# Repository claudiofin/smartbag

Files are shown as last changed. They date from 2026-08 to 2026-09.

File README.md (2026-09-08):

# SmartBag

**A removable smart insert for a handbag that recognises what is inside it —
without putting a tag on anything.**

Everything in this repo is generated by script: the PCB, the CAD, the renders,
the films. One command runs the whole chain, from KiCad to a finished MP4.

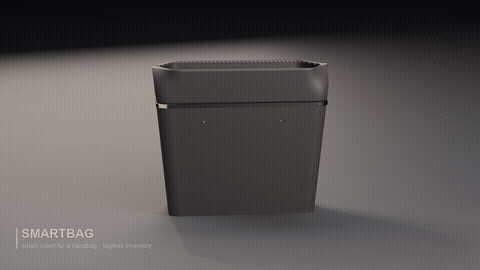
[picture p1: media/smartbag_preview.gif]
the bag opening in section


> *The GIF above is a short preview — click it for the full film.*
>
> **[▶ smartbag.mp4](media/smartbag.mp4)** (23 s) — how it is built ·
> **[▶ smartbag_sequence.mp4](media/smartbag_sequence.mp4)** (22 s) — how it works

---

## Read this first

This is a **design study**. Some of it is now checked by machine; none of it has
been built.

| | |
|---|---|
| schematic | **exists**, generated from `hardware/netlist.py`. **ERC: 0 violations.** |
| board | **113 footprints, six copper layers, routed, assembled on both sides.** DRC: **0 unconnected, 0 clearance violations, 0 shorts**; ERC clean. ⛔ It took a stackup change to get there, and the number that justified it is in [Six layers](#six-layers-and-the-number-that-decided-it). |
| part numbers | ⭐ **every IC is a real part, and its pinout comes from its own datasheet.** `tools/bom_report.py` measures each footprint against the datasheet's package on every run: **23 of 23 agree** — see [The bill of materials](#the-bill-of-materials). |
| firmware | the wake-up chain, the ledger, the taxel driver, the charge policy, the sensor bring-up, **the sensing loop that finally calls `sb_feed()`** and an Arducam Mega driver written from its own register table — **1035 assertions**, `-Werror`. ⭐ **And it builds for the nRF54L15**: [`firmware/target/`](firmware/target/) is a Zephyr app — ten HAL functions, the GATT service, the PMIC through Nordic's driver, a pin map **generated from the netlist** — at **177 KB of flash and 72 KB of RAM**, run by `tools/verify.sh`. ⚠️ Built, never run: nothing has met silicon. |
| recognition on the real part | the SoC has **no NPU**, so it was costed: 6.99 M MACs a frame on a 128 MHz M33 is **110–191 ms** against a settle window of 2000 ms — see [Recognition fits](#recognition-fits-the-processor). |
| recognition | an **enrolment pipeline that runs and is measured** — see [Recognition](#recognition). ⚠️ It now has to run on a Cortex-M33, not an NPU. |
| app | **written and running** — [`app/`](app/), tested against the firmware's own bytes. No native build; it is a web app. |
| RF | full-wave simulation rejected the antenna, closed-form analysis then rejected the whole feed — and the real part **dissolved the problem**: 60 GHz silicon has the antenna inside the package. There is now **no 60 GHz copper on this board.** See [RF](#rf). |
| thermal | **analysed** ([`thermal/budget.py`](thermal/budget.py)). It asked for charge current to be a function of cell temperature; the cell now has an NTC **in the pack**, a PMIC that reads it, and a policy under 544 assertions. |
| the taxel front end | measured wrong, then **fixed in hardware**: six transimpedance amplifiers and a 16:1 multiplexer — see [The taxel matrix](#the-taxel-matrix). |
| the 2.4 GHz antenna | ⛔ its datasheet found **three errors** in this design, one of them a terminal tied to ground that the part marks NC — see [The antenna](#the-antenna). |
| the optics flex | **exists now.** J1 was a connector to nothing for the whole project: the camera, the illuminators and the ToF live here. DRC 0 errors, 1 unconnected item. |
| the taxel sheet | **exists now.** 96 interdigitated sites, 16 columns and 6 rows, no components. **DRC 0 errors, 0 unconnected pads.** |
| fabrication | Gerbers for **all six copper layers**, drill, placement, DRC reports and a generated fab note for all three boards: `tools/fab.sh`. ⛔ The copper layer list is read out of the board file now — it was typed by hand, the stackup grew, and the next run plotted a six-layer board as four with In3 and In4 simply absent from the zip. ⚠️ **Two assembly sides now** — the processor's four decoupling capacitors are underneath it. |
| wireless power | ⛔ there was **no Qi receiver**: a coil was wired straight into a PMIC input that wants 4.0–5.5 V DC. There is now a BQ51013B, a dual resonant tank computed from the coil's own inductance, and a rectifier — see [Wireless power](#wireless-power). |

Run everything that can be checked:

```bash
./tools/verify.sh
```

```
== design constraints ==   all constraints hold
== firmware ==             28 + 324 + 53 + 264 + 21 checks, 0 failures
== protocol ==             15 tests passed
== ERC ==                  0 violations
== DRC ==                  0 errors · 4 unconnected pads · 0 footprint errors
== the other two boards == optics 0 errors, 2 pads · taxels 0 errors, 0 pads
== BOM vs footprints ==    23 of 23 named parts have a real MPN whose package fits
== recognition ==          ⭐ IT FITS, AND WITH ROOM
== physics ==              ✅ the 60 GHz feed question is settled
                           ⛔ Charging as specified puts the cell over its limit.
```

⚠️ The last two lines are printed on every run **on purpose** — and they are the
two findings that **rewrote the board**. The feed loss deleted the 60 GHz copper
and split one transceiver into two sensors; the charging analysis added a
thermistor and chose the PMIC. One is now a ✅ and one is still a ⛔, and both
keep printing: a suite that only reported its passes would be helping to forget
why the design looks the way it does.

## What it is

An **organiser that drops into any handbag** and knows what is inside it,
without tags on the objects:

| | |
|---|---|
| **IR camera** at the mouth | classifies each object as it enters or leaves |
| **60 GHz radar**, two 2×4 patch arrays | maps the volume through fabric — *where* it landed |
| **96-taxel FSR floor** | mass and footprint — *how heavy* and *what shape* |
| **ToF + Hall sensor** | the wake-up chain: closure opens → object enters → camera fires |
| **IMU** | integrates disturbance: tells the map when it has gone stale |

The bag itself is never modified, so the bag's value is never touched. The
insert slides out and moves to another one.

## The films

### smartbag_sequence.mp4 — how it works

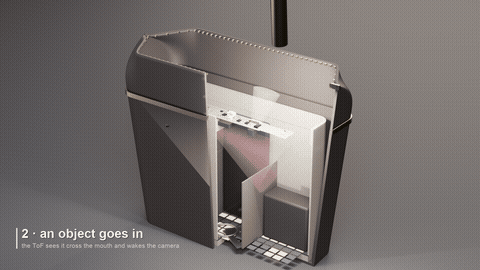
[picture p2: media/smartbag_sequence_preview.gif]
an object goes in and is scanned


1. **the zip opens** — the slider runs, the mouth gapes, the Hall sensor on the
   closure wakes the system
2. **an object goes in** — the ToF intercepts it crossing the mouth
3. **the IR camera fires** — three frames as it passes; the object itself lights
   up under the flash
4. **the radar maps the volume** — where it landed
5. **the FSR matrix weighs it** — the taxels under the object light up *when it
   lands*, not before
6. the zip closes again

### smartbag.mp4 — how it is built

The bag opens in section, the insert comes apart into its five layers with the
real KiCad board on top, the taxels light in a wave under the contents, then it
closes.

## Stills

| | |
|---|---|
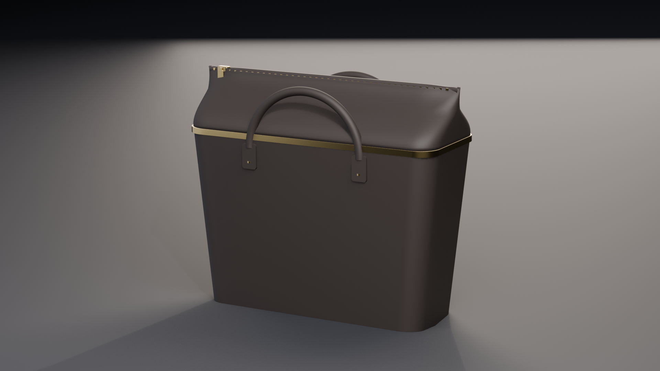
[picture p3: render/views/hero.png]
hero
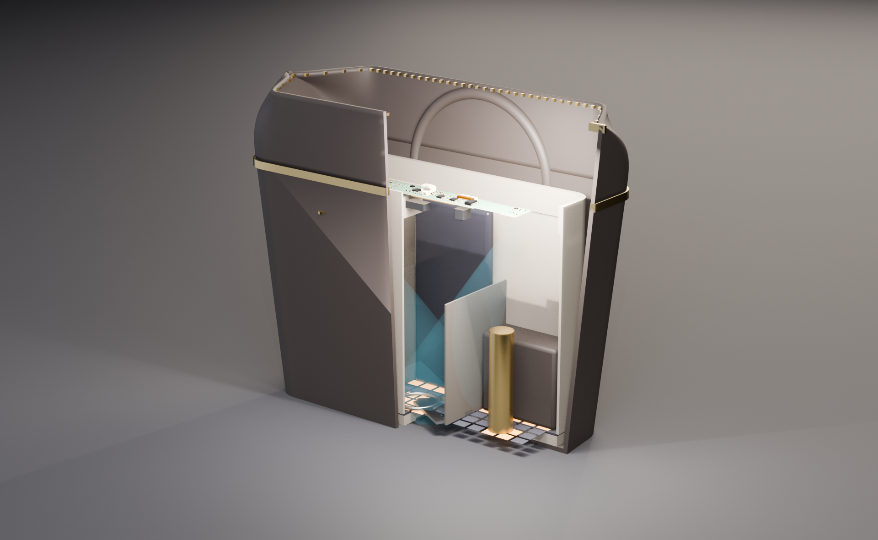
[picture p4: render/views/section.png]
section
|  |  |
| the bag closed: pinched neck, zip pulled shut | the section: contents upright, radar beam, taxels lit |

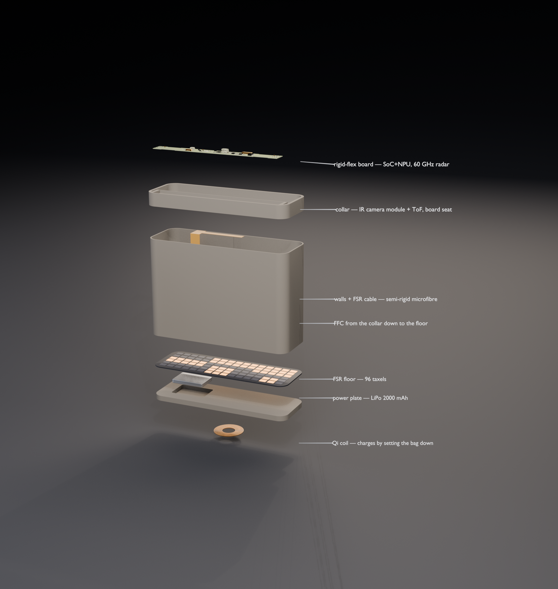
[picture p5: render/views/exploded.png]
exploded


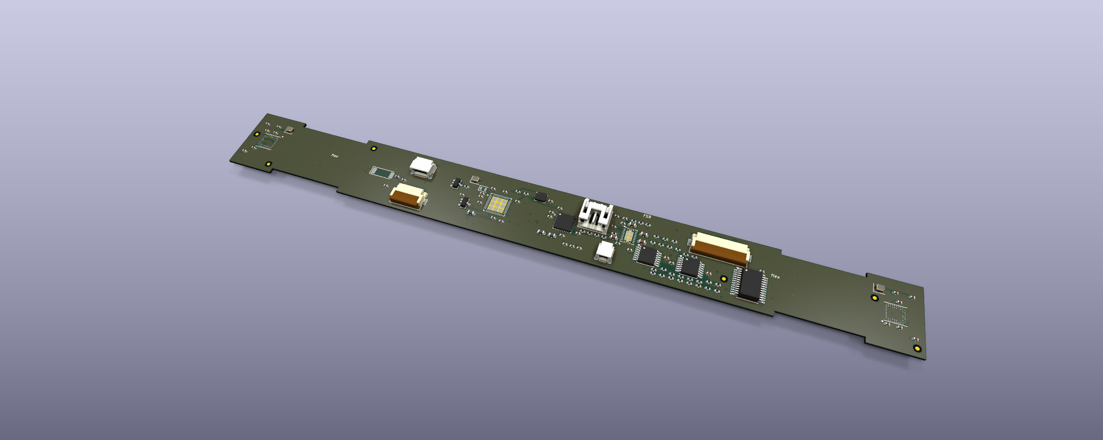
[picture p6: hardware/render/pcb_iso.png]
the board


---

## The pipeline

```
hardware/generate_pcb.py  ──> smartbag_core.kicad_pcb ──> KiCad raytracer renders
                                       │
                                       └─ kicad-cli export glb ──┐
cad/bag_and_insert.py     ──> 15 STL (bag + insert) ─────────────┴─> render/scenes.py
                                                                     (Blender EEVEE)
```

```bash
python3 tools/check.py             # the constraints, in ~0.1 s
./tools/pipeline.sh 1920           # circuit -> geometry -> stills   (~45 s)
./tools/render_animation.sh 1600   # 696 animation frames            (~26 min)
python3 render/build_video.py      # captions, fades, ffmpeg encode  (~3 min)
```

⭐ **`tools/check.py` asserts what the renders discovered.** Every constraint in
it was found the expensive way — modelling something, rendering it, and seeing
it was wrong. A board 51 mm deep in a 4 mm collar wall; an FSR tail 40 mm long
against a 150 mm drop; an object landing on top of a divider. None of those
raise an error anywhere: they produce a picture that looks fine until you look
closely. Written down as assertions they cannot silently come back — and the
first time it ran it caught three more, all invisible in the renders because
something else happened to be in front.

⭐ **It is a chain, not three separate things.** The PCB does not end up in a
PDF: it is exported to GLB and becomes an object in the *same Blender scene* as
the bag. That is the only way to find out that a board does not fit where it was
supposed to — and that is exactly what happened.

## Real numbers

| | |
|---|---|
| bag | 240×95 (floor) → 276×112 at 190 mm, 3.5 mm leather; soft neck 190→245 mm |
| insert | 225 × 78 × 180 mm, removable |
| board | 196 × 20 mm strip, 0.6 mm rigid islands on 2-layer polyimide flex |
| FSR matrix | 16 columns × 6 rows = 96 taxels, 22 lines on a 24-way FFC |
| radar arrays | 2 × (2×4 patches), 2.5 mm pitch = λ₀/2 at 60 GHz |
| battery | **Jauch LP523450JU**, 950 mAh, 53 × 34.5 × 5.8 mm, with PCM and a 10 k NTC on its harness — beside the Qi coil, not on top of it |

## What the renders actually rejected

This is the part worth reading. Putting the PCB and the CAD in the *same scene*
killed several things that looked fine on paper:

- **The first board layout was impossible.** A 126×51 mm cross with the FSR tail
  dropping out of the middle. Dropped into the insert, a board 51 mm deep either
  spans the mouth floating in mid-air or pokes out of the bag: the collar wall is
  4 mm. Redrawn as a **196 × 20 strip** sitting in a 24 mm front band.
- **The FSR tail on the board did not reach the floor.** 40 mm of flex against a
  150 mm drop. It became a **separate FFC** on J4 — which is also how it would
  really be assembled, because the cable has to pull out.
- **The insert has to pass through the smallest cross-section**, the floor, not
  the mouth. Hence 225×78 and not 240×82.
- **The bag never actually closed.** It was an open-mouthed tote, so the only
  thing "opening" was the section. Without a real closure there is no Hall
  sensor either — and that is the first link in the whole chain.
- **A zip is not a hinge; it is a mouth that pinches shut.** Four attempts
  rotated two rigid flaps hinged on the rim (up, down, inwards, outwards). All
  four read as a *hatch*, because two rigid plates rotating about a hinge **are**
  a hatch. The problem was upstream: a bag modelled as a rigid box cannot have a
  credible closure. The rigid body now ends at 190 mm and the last 55 are a
  **soft neck** — a surface with two states (oval mouth / mouth pinched to
  11 mm) interpolated by a shape key. The two rows of teeth do not rotate, they
  **separate**.
- **A zip has to be able to end somewhere.** With a rounded-rectangle mouth the
  teeth stayed 100 mm apart even at the tips and the slider finished its travel
  floating in mid-air. The mouth is now a **pointed oval**: the depth is squeezed
  to 4.5% over the last 40 mm, and only in the upper part of the neck (t³ —
  applied in proportion to height, the ends became wedges and from the side the
  bag looked like it had a pitched roof).
- **The object landed inside another object.** It fell at x = 44, straddling the
  divider at x = 37.5. Moved to x = 60, checked against divider, pouch and keys.
  The number lives in one place, `CONTENTS`, and both the render and the taxel
  logic read it from there.
- **The camera did not exist.** There was a pink cone flashing, but no module
  emitting it: light came out of a hole in the microfibre. A sensor you cannot
  see is a sensor nobody understands. There is now a module with its lens and
  four illuminators — and the **object lights up too**, which is the only thing
  that makes clear the flash is hitting it.
- **The hand was deleted.** Four attempts (from above, tilted, in section, with
  tapered and curled phalanges) and it stayed the worst thing in the frame while
  stealing attention from the sensors. An object descending on its own is
  understood in the first frame and has nothing to get wrong.

## The circuit

The connectivity is declared once, in [`hardware/netlist.py`](hardware/netlist.py):
pins, electrical types and nets for 26 parts. Three things consume it — the
schematic generator, the board generator, and the checks — so the board and the
schematic cannot drift apart. `kicad-cli pcb drc --schematic-parity` reports
**0 footprint errors**, which is that claim, verified.

**ERC found two things that were genuinely missing**, and the fix was to add
them rather than to silence the check:

- **no way to program the board.** SWDIO and SWCLK went nowhere. There is now a
  4-way SWD connector (J5), with its pins declared *bidirectional*, which is
  both electrically accurate and what makes ERC see the SoC's SWCLK input as
  driven.
- **a BLE radio with no antenna.** The SoC's ANT pin connected to nothing. There
  is now a 2.4 GHz chip antenna (AE1).

**DRC went from 439 violations to 0**, and almost all of the reduction was
deleting something rather than adding it:

| | |
|---|---|
| 439 → 215 | the board never declared its process. It is 0.1 mm lines on 2-layer polyimide flex with 0.3/0.15 vias; judged against KiCad's generic 0.2 mm defaults it collected 108 track-width and 112 via/drill violations that said nothing about the layout. |
| 215 → 1 | **the decorative routing.** Before there was a netlist, the generator drew bundles of tracks on net 0 to make the renders look like a circuit. Once the pads carried real nets, DRC read those tracks for what they were: 40 shorts, 6 clearance violations, 168 solder-mask bridges — one object producing more than half the errors on the board. |
| 1 → 0 | a courtyard overlap, and silkscreen. |

⛔ **The board is not routed.** Fanning out a 0.4 mm-pitch QFN-48, laying a
22-line bus and two 60 GHz microstrip feeds is a real job, and faking it with
decorative polylines is exactly the mistake that was just removed.

## RF

[`rf/patch_sim.py`](rf/patch_sim.py) solves Maxwell's equations on the patch
element with openEMS — ground plane, dielectric, patch, probe feed — and it
**falsified the antenna as first drawn**.

The setup is validated first, because a negative result is only worth stating if
the same solver reproduces a case theory says should work: a patch sized by the
transmission-line model (1.31 mm on 0.127 mm) comes back at **59.0 GHz, −9.3 dB**
— within 1.7% of target.

| substrate | patch | f_res | S11 | −10 dB BW | |
|---|---|---|---|---|---|
| 0.600 mm | 1.20 mm | 50.8 GHz | **−2.5 dB** | 0 | the rigid stack, as first drawn |
| 0.250 mm | 1.20 mm | **59.9 GHz** | **−27.2 dB** | **3.5 GHz** | the antenna islands, as now specified |

⛔ **On the 0.6 mm rigid stack the element does not work.** It sits 9 GHz low and
reflects almost everything. `h/λ₀` was 0.12, which is enormous at 60 GHz — the
board is 0.6 mm because that is what the rigid islands are, and nobody had
chosen that number for the antenna.

⭐ **The fix is the stackup, not the artwork.** At 0.25 mm the *same* 1.2 mm patch
matches at −27.2 dB with 3.5 GHz of bandwidth. On a rigid-flex board that costs
nothing: the antenna areas keep the flex core and a thin stiffener instead of the
full rigid buildup. A `.kicad_pcb` carries one board thickness, so it is a
fabrication note, on the Cmts.User layer and in `dimensions.py`.

⚠️ One element in isolation. No array coupling, no flex bend, no connector
parasitics, and εr is assumed — the numbers move with it.

**Getting the simulation to run at all took four wrong hypotheses.** It kept
returning `Energy: ~ nan` from the first timestep, and PML-over-a-conductor, the
lossy dielectric and the port were all blamed before a uniform-mesh control case
came back clean and pinned it on **mesh grading**: a 16:1 jump from the cells
over the patch to the far field. FDTD does not error on that, it silently
returns NaN. `rf/patch_sim.py` now refuses to run a mesh that will diverge, which
turns ninety wasted seconds into one line of output.

```bash
python3 rf/patch_sim.py --sweep
```

### And then the feed, which is worse

Fixing the element fixed the element. [`rf/feed_loss.py`](rf/feed_loss.py) asks
the next question — what does it cost to *reach* it — and the answer ends the
architecture.

The transceiver sits in the middle of a 196 mm board. The two antenna islands
are at the ends, 87 mm and 99 mm away. On the 0.25 mm substrate a 50 Ω line is
0.58 mm wide, and at 60 GHz it loses:

| | |
|---|---|
| dielectric | 0.64 dB/cm |
| conductor, roughened | 0.31 dB/cm |
| **total** | **0.94 dB/cm** |
| over 88 mm | **8.2 dB one way, 16.5 dB there and back** |

⛔ **A radar link budget goes as the fourth power of range.** 16.5 dB round trip
is a factor of 2.6 in range thrown away before the antenna has radiated
anything — on a sensor whose entire job is to see through 78 mm of handbag.

⭐ **This is not a routing problem and no layout fixes it.** The distance is the
floorplan, and the floorplan is the product: the two islands are at the ends
*because* two separated viewpoints are what makes the map work. Three ways out,
all of them architectural:

- a transceiver **on each island**, with a low IF and a reference clock
  distributed down the flex instead of 60 GHz;
- both antennas **next to the transceiver**, giving up the two viewpoints;
- **one island**, and a single viewpoint.

### And then a real part settled it

⭐ **The parts search dissolved the problem.** [`hardware/bom.py`](hardware/bom.py)
went looking for a 60 GHz transceiver you can actually buy. The Acconeer **A121**
is a 50-ball fcCSP, 5.2 × 5.5 × 0.88 mm, 57–64 GHz, 1.8 V, SPI — and its
datasheet says, in so many words:

> "The product has integrated antennas in package, it is not possible to connect
> trace antenna."

There is no 88 mm feed to lose 8.2 dB in, because **a real 60 GHz part is placed
where its antenna has to be.** That is option one above, arrived at by the parts
bin rather than by choice: `ANT_A1` and `ANT_A2` should not be nets, the two
antenna islands should be two sensors, and what runs down the flex to each of
them is SPI at a few tens of MHz instead of 60 GHz.

⚠️ Which also means the footprint on the board — a QFN-40 with four antenna
ports — is for a part that does not exist. That is one of the three mismatches
in [the bill of materials](#the-bill-of-materials).

```bash
python3 rf/feed_loss.py
```

## The board, rebuilt around parts you can buy

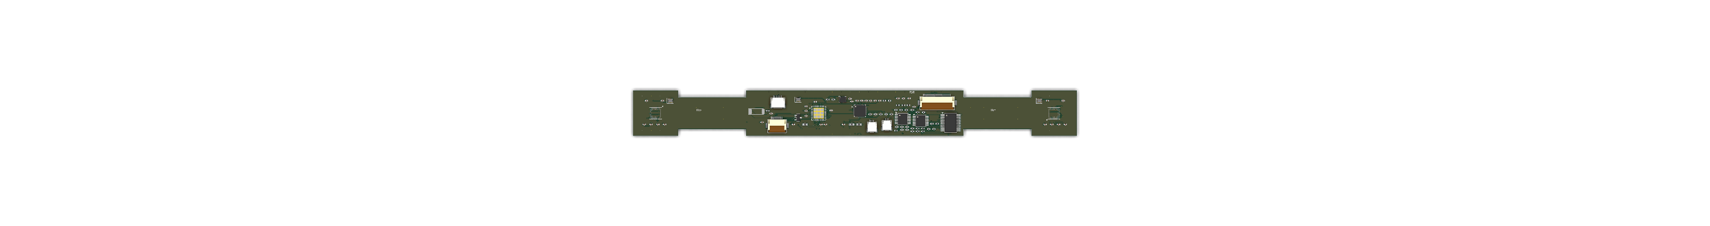
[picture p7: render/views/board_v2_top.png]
the routed board

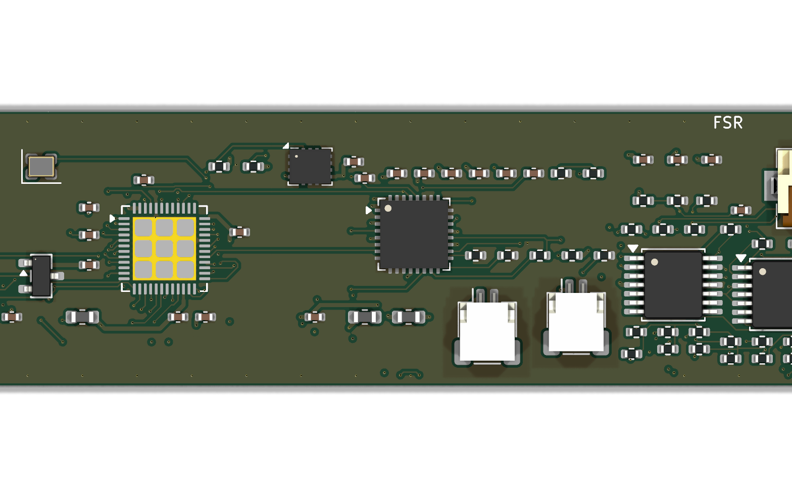
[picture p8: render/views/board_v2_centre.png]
the centre island


*Top: the whole 196 mm strip — two rigid end islands carrying a radar each, two
flex tails, and the centre island. Bottom: the centre island, where the QFN-48
processor, the QFN-32 PMIC, the taxel front end and the connectors live.*

The first version of this board was drawn from component *classes* — "SoC+NPU
BLE 5.4", "mmWave 60 GHz TRX" — with pinouts invented to suit. It said so, which
is better than not saying so, and it was still unbuildable: no real SoC has
ground on exactly pins 3 and 4. Going and finding the real parts changed the
architecture three times, and every change had already been asked for by
something else in this repo.

| what the parts changed | what had asked for it |
|---|---|
| **two radars, one on each end island, and no 60 GHz copper at all** | `rf/feed_loss.py` priced a central transceiver's feed at 8.2 dB one way. The Acconeer A121's datasheet then said the antenna is inside the package and *"it is not possible to connect trace antenna"*. The feed does not exist because a real part is placed where its antenna has to be. |
| **an NTC on the cell, into a PMIC that does JEITA charging** | `thermal/budget.py` put the cell near 60 °C on a 5 W charge against a 45 °C limit and asked for charge current to be a function of cell temperature. The nPM1300 has the input; the invented PMIC had nowhere to put one. |
| **six transimpedance amplifiers and a 16:1 multiplexer** | `firmware/test_sb_fsr.c` measured both scan modes the old board could run: one invents phantom taxels at 39% of a real press, the other reads real ones 83% light. |

⚠️ **And one thing the parts took away.** No BLE SoC in a QFN has an NPU *and* a
camera interface — the ones with an NPU are BGAs with no radio, the ones with a
radio have no NPU. The processor is an **nRF54L15**, a 128 MHz Cortex-M33, and
recognition has to run on it. That is survivable only because the firmware
already waits 2 s for an object to settle before measuring, so inference happens
inside a window that existed anyway.

⭐ **And it has now been counted rather than hoped for.**
[`ml/inference_budget.py`](ml/inference_budget.py) hooks the model and adds up
its multiply-accumulates instead of guessing: **6.99 M MACs**, which is 110–191
ms on a 128 MHz M33 with CMSIS-NN depending on how many cycles per MAC you are
willing to believe. The settle window is 2000 ms. The margin is an order of
magnitude, which is the only reason losing the NPU was survivable.

**113 footprints: 21 named parts, 86 passives, 6 fiducials.** The floorplan lives
in one block in `netlist.py`; [`hardware/place.py`](hardware/place.py) turns it
into positions whose courtyards do not intersect, because a hundred hand-typed
coordinates always collide somewhere — the first pass collided in 28 places.

⚠️ **The fiducials are placed by a different rule from everything else**, and
finding that out cost thirteen DRC violations. A fiducial has no net and no
neighbour it wants to be near, so the push-apart loop has nothing to work with:
it shoved two of them into capacitors and stalled. Telling it to maximise
clearance instead was worse — it emptied every fiducial onto the least crowded
island and left three in a row, and three collinear marks tell a placement
camera about one axis. They are a **decision**: two per rigid island, diagonally
opposite, because the flex tails let the islands move with respect to each other
and a machine that has located one has learned nothing about the next. The
search only nudges them off whatever they landed on.

⛔ **Nothing sits on the flex.** The board is a 196 mm strip with two tails in it,
and a package soldered across a section that bends does not stay soldered. An
early placement pass put a 24-way connector and a row of resistors out over a
tail and off the board edge with them; the placer now knows about the three rigid
islands and refuses.

## Routing

**KiCad has no autorouter.** It had one through version 5 and it was removed, so
the flow is: `pcbnew` writes a Specctra `.dsn`, somebody else's router writes a
`.ses`, `pcbnew` reads it back. The router here is **Freerouting**, a maze router
with rip-up and retry.

```bash
tools/route.sh                      # generate → DSN → route → import → stitch → DRC
hardware/reroute_from_session.sh    # rebuild from the committed .ses, no Java
hardware/stitch.py                 # tie orphaned ground islands back to the plane
```

⭐ **`maze.py` exists because Freerouting recommends something it cannot do.**
When it stops improving it says so: *"it is recommended to stop it and finish the
board manually."* Manually is fine — but a person drawing four tracks and
eyeballing them is exactly the step this project avoids everywhere else. So the
candidates are drawn blind and **DRC decides**: a route is kept only if the net
it was drawn for has fewer breaks and the board has no new violations, and
reverted otherwise. It cannot make the board worse; the worst it can do is fail
to help.

⛔ **Which is a harder test to write than it looks.** "Fewer unconnected pads on
the board" is wrong — KiCad reports one ratsnest line per NET, so closing one of
a net's two breaks changes nothing and a correct repair gets thrown away. "The
pair DRC named is gone" is wrong — KiCad picks a different representative item
every run, so it is always true, and under it this router once accepted twelve
vias that connected nothing and reported each as a success. Counting islands
through KiCad's own connectivity was wrong too. What works is asking DRC how
many breaks **this net** has left.

⚠️ Its first version reverted by reloading the board from the file it had just
written the failed candidate into. Three rejected tracks accumulated in the
board and the tool reported the damage as its starting state.

⛔ **And the maze router's collision model was optimistic by less than a cell**,
which is the hardest kind of wrong to see. Pillow rounds an ellipse *in*, so
every via was drawn as an obstacle up to one grid cell smaller than it is — 50 µm
at the fine pitch. `SPI_MISO` came back from a 2264-cell search with sixteen
clearance violations of 0.02–0.08 mm, every one a track passing a via, and the
router had proposed each of them believing it was legal. Rounding the obstacle
circles out took it to one. See
[Decoupling](#decoupling-the-defect-that-passed-every-check) for the other three
of the same family.

⭐ **Two of the last connections were never routing problems at all**, and
[`hardware/repairs.py`](hardware/repairs.py) says so out loud. One is a *gap* —
two pieces of a net a tenth of a millimetre apart, under a track width, which
looks joined at any zoom a person would use. The other is a *missed drop*: a
track that ends exactly on a pad, on the wrong layer, so the copper is in the
right place, there is no via, and the ratsnest line is **zero millimetres long**.
Sent at either, the maze router routes a centimetre around the houses, because
the pair DRC names is the two islands' representative items and not the two ends
that need joining. Each repair states what has to be true before it applies and
**refuses loudly** if the board has moved under it.

| | |
|---|---|
| tracks / vias | **1713 / 393**, 4.3 m of copper |
| DRC | **0 errors, 0 footprint errors**, schematic parity clean |
| unconnected | **1 item of ~500** |
| layers | F.Cu 724 · In2.Cu 919 · B.Cu 70 · **In1.Cu 0 — a solid ground reference** |

⛔ **Sixteen of those twenty were a pin assignment, not a routing problem.** The
board first came back with one contiguous run of U1's pins unrouted — `MUX_S3`,
`MUX_EN_N`, `CS_RADAR_R`, `RADAR_IRQ_R`, `SPI_MOSI` — and the thing they had in
common was direction: every destination was tens of millimetres to the **east**,
and `MUX_S3` sat on pin 11, which is on the package's **west** edge. That net
began by crossing the whole processor before it could start travelling.

⭐ **Which GPIO carries which signal is a layout decision**, and on this part it
is nearly free: the firmware addresses pins through a HAL of symbolic ids, so
the physical assignment is invisible to it. The P2 block is now ordered by
destination — westbound nets on the west pins, eastbound on the east ones,
furthest travel on the outermost pin. `SPI_SCK`, `SPI_MOSI` and `SPI_MISO` do
not move, because those are the pins the high-speed SPIM is wired to in silicon
and the other instances run at 8 MHz instead of 32.

| | before | after |
|---|---|---|
| unconnected | 16 | **4** |
| autoroute time | 65 min | **15 min** |

⭐ **And one of the four was closed by writing a router for it.**
[`hardware/maze.py`](hardware/maze.py) is A* over a 0.1 mm grid, and it exists
because a fixed set of shapes cannot go *around*: a straight line and two L-bends
per layer, which on a board this dense all cross something. It reports that
honestly and stops.

| | |
|---|---|
| **zones are not obstacles** | almost all of F.Cu and B.Cu is ground pour. KiCad re-fills around new copper, so the route lays itself into the pour and the pour retracts. Treating the pour as solid finds no route anywhere. |
| **obstacles are drawn, not computed** | testing a million grid points against two thousand segments is a minute per net; drawing those segments with a brush already fattened by (their width + clearance + ours) is milliseconds. Pillow is the collision engine. |
| **DRC decides** | every route is applied to a copy, checked by a real `kicad-cli pcb drc`, and kept only if the board comes out with fewer unconnected items and no new violations. |

It closed `RADAR_IRQ_R`, the longest of them — 108 mm from U1 to U6, across both
flex tails.

⭐ **Then a fanout took it to one.** Forty-eight pins escaping on a single layer
was the bottleneck all along, and it stayed invisible because it never produced a
wrong answer — only a router that gave up. U1 is a QFN48 on a 0.4 mm pitch with
thirty-five signals to get out, and without a fanout every one of them travels on
F.Cu until it finds room to drop, so the pins facing away from their destination
cross the whole package on the most congested layer of the board.
`qfn_fanout()` puts a via 0.35 mm outside each pin — what a person would draw,
and the standard escape for a fine-pitch QFN. **10 → 1.**

| | |
|---|---|
| wider flex tails (14 → 17 mm) | 10 → 10 |
| ground vias on the radars' interior balls | 10 → 10 |
| **a fanout via per QFN signal pin** | **10 → 4** |
| **supply pins in the fanout too** | **4 → 1** |

⚠️ The first two look like they did nothing and they were not wasted: the tails
carry the SPI bus that the fanout then had somewhere to put, and the ground vias
are an RF requirement rather than a routing one. What the table actually shows is
that measuring one change at a time is the only way to find out which one was the
constraint.

⛔ **It had gone up to ten first, for two reasons that are both improvements.**
Choosing a cell you can order brought a **JST PH** with it — nearly twice the SH's
footprint area, in the part of the board the SPI bus to the right radar has to
cross. And `via_in_pad()` stopped skipping ground: **fourteen of the A121's
interior balls are ground and not one of them had a via**, so the die's ground was
tied to the plane by whatever copper squeezed between balls on a 0.5 mm pitch. On
a 60 GHz radar with the antenna inside the package that is not a cosmetic
complaint. Twenty-eight more vias, in the tightest area of the board — and
freerouting got worse at exactly the rate you would expect.

⚠️ **The one that is left** is `VDD_3V3` at U1 pin 10. `maze.py` finds a route
that closes it and lands 0.02 mm inside the Power class's 0.15 mm clearance, so
DRC refuses it and so does this project: a rule relaxed to make a violation go
away is not a rule. It is a few minutes for a person with KiCad's interactive
router, which can push and shove neighbouring tracks — something a fixed-grid
router cannot do. The two signals are genuinely
sealed: a flood fill from U1 pin 10 reaches **79 cells** before it runs out of
board. At a 0.4 mm pitch the gap between two adjacent pads is 0.2 mm, and a
0.1 mm track with 0.1 mm either side needs 0.3 — so the escape has to go
outward, and outward is where the other forty pins already went. Closing them is
a floorplan change, not a better router.

⛔ **Turning U1 round is the obvious-looking fix and it does not work.** At 180°
and again at 90°, Freerouting's autorouter finished in minutes and its
*optimiser* then ground for over an hour without ever writing a session file —
three attempts, two angles, same outcome. Reassigning the pins got the same
result for free.

### Three hand-written attempts first, and what they got wrong

466, 989 and 852 violations. Two of the three conclusions drawn from them were
wrong, and finding that out was worth more than the attempts were:

| claimed | verdict |
|---|---|
| "at 0.4 mm pitch via-in-pad is not optional" | ⛔ **false for a QFN** — every pin is on the perimeter and escapes outwards. It is true for a 0.5 mm **BGA**, where four of the A121's signal balls are fully surrounded. Right conclusion, wrong package. |
| "two layers cannot carry this board" | still true, and still only ever measured on two layers. |
| "what is missing is a maze router with rip-up and retry" | ⭐ **true**, and the only one that mattered. |

⛔ **And one cause nobody had looked for.** Those attempts routed to 0.2 mm tracks
and clearances — KiCad's *generic netclass default* — because this project
declared its process **minimums** and never declared what the design **uses**.
DRC cannot complain that 0.2 mm is too wide when 0.1 mm is merely the floor. It
took handing the file to a router, which routes to the netclass, for the gap to
appear.

### What the router taught this board

- ⛔ **An autorouter given four signal layers will use four.** The first routed
  board put 34% of its tracks on In1.Cu — the layer a comment declared was
  "never routed on". A comment is not a rule. Marking it `power` in the DSN
  fixes it, and the price was measured: two signals stopped routing.
- ⛔ **The router has never heard of copper-to-edge clearance.** Specctra's
  boundary *is* the outline, so a via landed 0.120 mm from an edge against a
  0.150 mm rule. The first fix moved the via afterwards; it cleared the edge and
  landed 0.089 mm from a ground pad instead. **Nudging copper after the fact
  just moves a violation somewhere the router is no longer looking.** The
  boundary is now inset before the router ever sees it.
- ⛔ **A thermal spoke wider than its pad connects nothing.** J1's ground fingers
  are 0.3 mm and the zones used 0.4 mm spokes, so the pads sat isolated inside a
  ground pour and DRC reported them as unrouted ground — which reads like a
  routing failure and was a fill setting.
- ⭐ **Turning a part is free and turning it matters.** The A121's SPI pins are
  all on one edge of the ball grid; at 0 degrees that edge faced away from the
  processor on both sensors and the bus had to wrap around a 0.5 mm package.
  Rotating each sensor to face the processor took five unconnected pads off the
  board. ⚠️ Rotating the *processor* the same way looked like the same
  improvement and made Freerouting's optimiser grind for over an hour twice
  without producing a file — so it is not rotated, and `netlist.py` says why.
- ⛔ **A ground pour is not a ground plane until it is stitched.** Routing 1683
  tracks cut the top pour into islands, and an island with no via in it is not
  ground, it is a floating sheet of copper. `hardware/stitch.py` runs *after*
  routing — the islands are made by the routing, so they cannot be found before
  it — and closed six of the nine remaining unconnected pads.

  ⚠️ Its first version approximated each track by nine points to test clearance,
  which leaves 3 mm gaps in the middle of a 26 mm trace; a stitching via landed
  in one, 0.048 mm from a signal. A track is a segment and the distance to it is
  a closed form.

⭐ **The `.ses` is committed.** The routed board is a generated file — generator
plus routing session — and committing only the board would make the routing
something nobody could reproduce or review.

## Decoupling: the defect that passed every check

## Six layers, and the number that decided it

⛔ **Four copper layers meant THREE routable ones**, because In1 is the RF
reference and nothing is routed there — enforced by marking it a `power` layer
in the Specctra export, after the first routed board put 34% of its tracks on it.
A QFN48 with thirty-five escapes exhausts three layers.

⭐ **It was measured, not felt.** U1 pin 22 finished walled in: a breadth-first
search on a 0.1 mm grid over a 28 mm window, on every routable layer, reached

| layer | free cells reachable from the pin |
|---|---|
| F.Cu | 23 |
| In2.Cu | 41 |
| B.Cu | 2 |

**0.4 mm² of space, and no copper of its own net anywhere in it.** Moving the
escape via outward found no clear position within 2.4 mm of the pad either — C7,
C3, L1 and U5's courtyard are all in that millimetre. Straight links, L-bends,
two-segment paths with the corner on a grid, and the maze router itself: none of
them was the problem. The board was.

The stack is now **F.Cu / In1(GND) / In2 / In3 / In4(GND) / B.Cu** — the signal
pair between the two planes, so no signal layer is ever more than one dielectric
from a reference. ⚠️ **On a rigid-flex this is not the usual four-to-six
conversation**: it costs more than on FR4, and whether the flex tails carry all
six is a question for the quote.

⭐ **And it ends the other compromise too.** The two-millimetre decoupling rule
below was a routing constraint dressed as a placement rule; with a fourth
routable layer the capacitors can sit where the datasheet wants them.

### What it produced

```
0 unconnected pads · 0 clearance violations · 0 shorts · ERC 0 errors 0 warnings
```

Six warnings remain and all six are known: two A121 library mismatches that have
been overridden since the footprint was transcribed from its datasheet, and four
escape vias that `drop_dangling` now spares **on purpose** — removing two of
them is what stranded these pins in the first place, and that took most of a
session to find.

⛔ **And the finishing is part of the pipeline now, because it was not.** A
`.ses` file holds what the *router* did; five of this board's connections are
closed after it, by four steps that were being run by hand. Regenerating from
the session threw all of it away and the rebuild still **looked** routed —
which is the worst way for a board file to be wrong. `route.sh` and
`reroute_from_session.sh` run them in the order that matters, and
[`hardware/repairs.py`](hardware/repairs.py) carries the two paths that close
U1 pins 10 and 22 as polylines with a premise each: if the board moves under
them they refuse loudly rather than laying copper into whatever is there now.

⛔ **Forty-one of forty-one.** Every supply pin of every IC on this board had its
nearest decoupling capacitor on the same rail more than 2 mm away. The worst was
the multiplexer at **26 mm** — a 100 nF part twenty-six millimetres from the pin
it serves is not a capacitor, it is an inductor with a capacitor in series with
it. The board had been routed, DRC'd, rendered, costed and declared orderable in
that state.

⚠️ **And `netlist.py` said it had already been fixed.** In as many words:

> ⛔ THE 100 nF PARTS HUG THE PINS THEY DECOUPLE. […] The QFN has VDD on all four
> sides, so there is a capacitor on all four sides.
> `"C5": (-17.5, -5.0),  # beside pins 47/48, top edge`

C5 is 2.2 nF on DECRF — an internal regulator pin, not a supply. **U1 pins 47 and
48 never had decoupling at all**, and neither did U7. The comment described a
repair that had happened on three edges out of four and nobody noticed, because
**a comment is not a check**.

### Why it drifted, and why it could not not drift

`place.py` is a relaxation: *if two courtyards overlap, push both apart*. There
is nothing in it that pulls anything toward anything. Every capacitor started at
a hand-typed coordinate near its pin and every round moved it a little further
away. The floorplan was a hint and the arbiter only knew one direction.

So the intent moved out of the comments and into
[`netlist.py`](hardware/netlist.py)'s `DECOUPLE` map — 23 pairs of *this
capacitor serves that pin* — and `place.py` now reads the pin's real pad position
out of the footprint and places the capacitor against it **after** the relaxation
has settled everything else. Same treatment the fiducials get, for the same
reason: a part that must be within a millimetre of one specific pad is not an
ordinary part.

### The half that was missed, which was the important half

The distance check passed. Then the board came back with **C7 — the processor's
own decoupling — sitting with its ground terminal on a 0.69 mm² scrap of pour
that had no via in it.** Its return path went nowhere.

⛔ **A capacitor 1 mm from its pin with a 20 mm return is worse than one 3 mm away
with a via underneath it.** The loop is what sets the inductance and the loop is
*both* sides. And it was not a coincidence: moving the capacitors hard against
the packages is exactly what pinches the pour off around them. `generate_pcb.py`
now drops a ground via 0.35 mm from every decoupling capacitor's return pad, and
`tools/check.py` measures it.

### And then the escape channels, which is why four parts are on the back

A QFN48 on a 0.4 mm pitch escapes through a ring of vias 0.35 mm outside its
pads, and everything on that edge travels the gap between the package and the
ring. A 0402 in the gap closes it. Measured, not assumed: putting them there cost
`RADAR_IRQ_R` and `CS_RADAR_R`, two signals that had routed for months.

Widening the band the placer keeps clear recovered both. It did not recover the
bottom edge, which has ten signals leaving it — so **U1's four capacitors are on
the back, under their pins**. Ground terminal directly on the bottom pour,
supply terminal up through a via in its own pad, nothing crossing the surface.

⚠️ **It costs a second assembly side.** 109 parts on the front and four on the
back: one extra stencil on five prototypes, a second reflow pass on every board
in volume. That is in `fab/README-FAB.md` and it is a real number, not a detail.

| what the checks now assert | |
|---|---|
| every DECOUPLE pair names a pad that exists | 23/23 |
| every capacitor within 2 mm of its pin, **pad to pad** | 23/23 |
| every capacitor has a ground via within 1 mm of its return | 19/19 on the front; the four on the back are *on* the pour |
| every IC rail has a capacitor anchored to it | 0 uncovered |

### Four tool bugs came out with it

⛔ **The relaxation pushed by a fixed step.** A third of a millimetre each way is
0.7 mm of separation per round, and a part in a lane only fractionally taller
than itself gets thrown past the far wall, bounced back and thrown again —
forever. C80 sat between a resistor and the coil connector in 1.82 mm of room
needing 1.76, and six hundred rounds never placed it. It pushes by half the
overlap now and converges in one.

⛔ **The overlap check ignored rotation.** The two radars are the only rotated
parts on the board, so for them it was checking a rectangle 0.15 mm out in each
axis from the one that gets fabricated. Latent until something sat that close.

⛔ **Pillow draws ellipses rounding *in*.** The maze router's line case already
knew this — `math.ceil(width) + 1`, with a comment — and the ellipse case did
not, so **every via was drawn as an obstacle up to a cell smaller than it is**. At
the fine 0.05 mm grid that is 50 µm of clearance the router believed it had. Not
a rounding curiosity: it is exactly the size of the failures. `SPI_MISO` came
back from a 2264-cell search with sixteen clearance violations of 0.02–0.08 mm,
every one a track passing a via, and the router had proposed each of them
believing it was legal. Rounding the obstacle circles out took it to one.

⛔ **`GetNetsByName()` does not match Python strings.** `"VDD_3V3" in nets.keys()`
is `False` for a net that is right there. Two repair tools reported politely that
they had nothing to do while skipping every net on the board — which is
indistinguishable from a board with nothing wrong.

⚠️ **And two writers, two dialects.** `generate_pcb.py` writes a via's net as a
number (`(net 3)`); KiCad's own writer, which touches the file the moment
anything runs `pcbnew` on it, writes the name (`(net "GND")`). The return-via
check knew one of them, so on a board KiCad had rewritten it found **no vias at
all** — and "no vias" has the same shape as a real defect. It reads both now, and
fails loudly if it finds none.

## Thermal

[`thermal/budget.py`](thermal/budget.py). **The interesting case is not the one
you expect.**

A 60 GHz ping and an NPU inference sound like the thermal problem. They are not:
0.15 s, forty times a day.

| | |
|---|---|
| every sensing load, averaged | **0.18 mW** |
| whole-bag rise from it | **+0.000 K** |
| worst burst, adiabatic, package only | **+5 K**, gone in seconds |

⛔ **Charging is the thermal problem.** 5 W in at 80% is a watt of loss for two
hours, inside a closed bag, with the Qi coil directly under the lithium cell —
and the insert wall between it and the outside world is soft microfibre over
foam, which is to say an insulator, chosen for exactly the reason it is bad here.

| | |
|---|---|
| wall, 3 mm of k = 0.05 | 11 K/W |
| surface | 23 K/W |
| **coil face** | **≈ 60 °C** |
| **cell temperature** | **≈ 26 °C**, against a 45 °C charging limit |

⭐ **The cell got out of it by moving, not by being argued with.** Every earlier
run of this model put the cell near 60 °C, and that number rested on one sentence:
*the Qi coil sits directly under the LiPo*. It did — because the cell was a
148 mm pouch drawn to fill the insert floor, and there was nowhere else for the
coil to go. Choosing **a cell you can actually order** made it 53 mm, which left
170 mm of floor free, so the two now sit **side by side**. The heat has to travel
62 mm along foam to reach the cell — 4493 K/W against the 23 K/W it would take
straight up to air — and takes **0.5%** of the coil's rise.

⚠️ **The finding moves rather than disappearing.** A watt still has nowhere to go;
all that changed is what is sitting on top of it. The coil face is still at
**≈ 60 °C**, against microfibre, foam and then leather, for two hours at a time.
Nothing there has a 45 °C limit, but leather ages and a bag is a thing people
hold — so the interlock keeps its place and changes its reason.

✅ **Implemented**, and the numbers are the cell's own rather than lithium's in
general. [`firmware/sb_power.c`](firmware/sb_power.c) holds the policy — full
current only with the bag **open** and the cell between **15 and 45 °C**, 2.9 W
otherwise, 0.5 C between 45 and 55, and nothing at all if the thermistor reads
open-circuit — under **276 host assertions**, including a sweep over every cell
temperature with the bag shut.

⛔ **Those thresholds were 10 and 40 until the cell was real.** Not wrong — a
guess that happened to be conservative, which is not the same as being right.
The LP523450JU datasheet states its own table (0.2 C from 0 to 15 °C, 1.0 C from
15 to 45, 0.5 C from 45 to 55) and `tools/check.py` now asserts the firmware
against it, so the two cannot drift apart again.

⛔ **And the thermistor moved off the board.** It was a 0402 NTC beside the PMIC,
which measures the PMIC: the cell whose temperature the entire policy is about is
twenty millimetres of foam away. It is now the third pin of the battery
connector, in the pack, where the nPM1300's datasheet calls it *the battery
thermistor* — so [`J2`](hardware/bom.py) is a 3-way SM03B-SRSS-TB and not the
2-way part it was. A pull-up resistor went with it: the PMIC's measurement is
ratiometric against its own reference, and a second pull-up to VSYS corrupts it.

⚠️ The number above is still what the hardware does **unconfigured**, and it is
kept for that reason — it is true on the first boot, before anything writes to
the PMIC. A limit is only real once somebody has set it.

```bash
python3 thermal/budget.py
```

## Wireless power

⛔ **There was no receiver.** For the whole project J3 was labelled *Qi coil* and
wired into the PMIC's VBUS — an input whose datasheet asks for **4.0 to 5.5 V
DC**. A coil on a charging pad does not produce that. It produces alternating
current at 100–200 kHz, at whatever amplitude the coupling happens to give, and
the design had nothing between the two. Every one of the checks in this
repository passed, because none of them knew what a coil is.

⭐ **What the missing piece actually is.** A Qi receiver is not a rectifier with
extra steps. It is a resonant network, a synchronous rectifier, and a
*communication channel* — the receiver tells the transmitter how much power to
send by modulating its own load, and a transmitter that hears nothing shuts down
after a few seconds. The part is a **BQ51013B**, and it brings eleven components
with it:

| | |
|---|---|
| **Cs**, series with the coil | **270 nF** C0G — resonates 8.8 µH at 100 kHz |
| **Cd**, parallel | **2.7 nF** C0G — the 1 MHz tank the transmitter pings to detect a receiver |
| **COMM1/COMM2** | the load-modulation capacitors that let the receiver talk back |
| **CLAMP1/CLAMP2, BOOT1/BOOT2** | overvoltage clamp and the rectifier's bootstrap rails |
| **RILIM, ADEN, FOD** | current limit, and the resistor divider that tells the transmitter what losses to expect |

Both resonant values come from the coil's own inductance rather than from a
reference design — [`hardware/qi_resonance.py`](hardware/qi_resonance.py) prints
them and, more usefully, prints how far they move if the assembled **L′** is not
the datasheet's 8.8 µH: 10% high takes Cs to 262 nF, 20% to 240 nF.

⚠️ **C0G is not a preference here.** Both capacitors carry the full coil current
at 100 kHz, and a class-II dielectric loses capacitance under bias — an X7R part
of the same nominal value detunes the tank as soon as it is working.

⚠️ **Still untuned on hardware.** The resonance is computed, the FOD divider is a
starting value, and neither can be finished without a built board: L′ has to be
measured on the assembled coil in its final position, and FOD has to be
calibrated against a real transmitter. Both are named in
[`fab/README-FAB.md`](tools/fab_notes.py).

## The taxel matrix

96 sensors on 22 wires and **not one diode** — that is what makes the matrix
affordable, and it is also a circuit in which current does not stay where you
put it.

[`firmware/test_sb_fsr.c`](firmware/test_sb_fsr.c) does not mock the hardware. It
builds the nodal admittance matrix of the real thing — 16 columns, 6 rows, 96
resistors, a sense resistor per row — and solves it. Press three taxels in an L:

| scan mode | the phantom taxel | a real taxel |
|---|---|---|
| unselected columns floating | **112 µS — 39% of a real press** | 289 µS |
| unselected columns grounded | 0 µS | **83 µS instead of 500 — 83% low** |
| rows at virtual ground (TIA) | 0 µS | **500 µS, exact** |

⛔ **Neither mode the board can actually run is usable.** Floating columns
manufacture objects that are not there — three contacts create a fourth, the
same sneak path that makes cheap keyboards register phantom keys, and a bag full
of objects is exactly the many-simultaneous-contacts case that provokes it.
Grounding the columns kills the phantom and then puts them in parallel with the
sense resistor, so every real taxel reads six times light whenever anything else
in its row is loaded.

⭐ **The third row is the control case, and it is what makes the other two mean
something:** the matrix is not inherently unreadable. Hold the rows at virtual
ground and every non-selected taxel has zero volts across it, carries nothing,
and the reading is exactly the selected taxel. That costs six op-amps, or one
plus an analog mux. Neither is in `hardware/netlist.py`.

⚠️ Selecting `SB_FSR_SCAN_TIA` in firmware on the board as drawn changes the
drive pattern and nothing else. This is a hardware gap, stated as one.

The same tests found an ordinary bug the interesting one would have hidden: blob
centroids were stored as `int16_t` micrometres, which saturates at 32.8 mm on a
225 mm insert. Every object in the outer two thirds of the bag reported the same
position, and it read as plausible because 32 mm is a real place.

## The bill of materials

`netlist.py` used to name component *classes* — "SoC+NPU BLE 5.4", "mmWave
60 GHz TRX" — and pick a package that looked plausible for each. ⛔ **That is a
comfortable way to be wrong: a footprint invented to fit an idea always fits.**

[`hardware/bom.py`](hardware/bom.py) names parts you can buy and copies their
package dimensions out of their own datasheets;
[`tools/bom_report.py`](tools/bom_report.py) measures what the KiCad footprints
actually are and prints every disagreement.

```bash
tools/fetch_datasheets.sh       # the PDFs are not committed — see below
python3 tools/bom_report.py     # writes hardware/bom.csv
```

**23 of 23 named parts agree with their datasheets**, and the three that did not
were fixed by changing the board, not the spreadsheet — see [the
rebuild](#the-board-rebuilt-around-parts-you-can-buy). Plus 82 passives, whose
values are read out of `netlist.py` rather than kept in a second list that can
drift.

⭐ **The check had to be rewritten twice before it was worth anything**, and both
mistakes are instructive:

| version | what it did | what it certified |
|---|---|---|
| 1 | counted `(pad "...")` records | **passed U2**, the worst mismatch on the board: KiCad splits a QFN-40 thermal pad into nine sub-pads, giving 40 + 9 + 1 = **50 pad records** — exactly the ball count of the 50-ball part it resembles in no other way. |
| 2 | counted distinct *numeric* pad numbers | scored the A121 at **zero pins**. A BGA's pads are named A1, K9, J10; a rule written for QFNs reports the part as empty rather than as wrong. |
| 3 | distinct pad **names**, minus mechanical ones | thermal sub-pads share a name and collapse to one, which is the behaviour that made the check worth writing. |

A coincidence in one number is all it takes for a naive check to certify the
thing it exists to catch.

⚠️ **The datasheets are not in the repo.** They are third-party copyrighted
documents: reading one to check a package dimension is ordinary use,
republishing a vendor's PDF from a public repository is not. `bom.py` carries the
URL and the numbers read out of each, and the fetch script puts the documents
back on your disk. Several vendors (Mouser, LCSC, Hirose) serve an HTML challenge
page to `curl`, so those are reported as failures and left to a browser rather
than saved as a PDF-named error page.

⛔ **Reading a datasheet is not always reading text.** The nRF54L15's QFN48 pin
table is split across page breaks in a way no text extractor survives — three
attempts produced three different wrong pinouts — so the assignment *figure* was
rasterised and read as an image. The nPM1300's figure is the opposite: numbers
only, with the names in a table on the next page.

### What is still missing

This list used to have five entries and now has two, and the three that left did
not leave quietly:

- ~~a camera module~~ — **CAM is an Arducam Mega 3MP NoIR**, $29.99, with a
  driver in [`firmware/sb_camera.c`](firmware/sb_camera.c) written from its
  application note's register table and its own SDK. ⛔ Writing that driver
  found a mistake nobody had noticed: register 0x20 offers JPEG, RGB and YUV and
  **no greyscale**, so the 96×96 frame the model wants is 18 432 bytes on the
  wire and not 9 216, and `ml/inference_budget.py` had been charging the SPI
  burst at half its real cost since the day it was written.
- ~~an NPU~~ — settled by arithmetic rather than by a part;
  `ml/inference_budget.py` puts the whole pipeline at 137…219 ms inside a 2 s
  window the firmware already waits.
- ~~a real fuel gauge~~ — the state of charge was a straight line from 3.0 V to
  4.2 V. ⛔ **The cell's own datasheet refutes that line.** "Delivery State of
  Charge: Max. 30% (3.75–3.79 V); Optional 60% (3.85–3.95 V)" is two points on
  this cell's discharge curve, and the straight line reads the first of them as
  **64% where the cell says 30%**. [`firmware/sb_power.c`](firmware/sb_power.c)
  now interpolates the four points the datasheet actually gives, and corrects
  the terminal voltage for 180 mΩ of pack impedance — at the 1 A charge current
  that is 180 mV, a fifth of the cell's whole range.
- **a tuned antenna match** — L2/C6/C11 are the chip vendor's reference values,
  and a chip antenna matches against the ground plane around it. This ground
  plane is not theirs. ⚠️ This one cannot be closed on paper; see
  [Calibration](#calibration-the-four-things-a-datasheet-cannot-settle).
- **real sensor data** — every threshold is a datasheet figure or arithmetic
  over one, and `ml/classify.py`'s accuracy is measured on rendered primitives.
  Whether a wallet can be told from a passport through four IR LEDs at 96×96 is
  a question the built thing answers and nothing else does.

## Calibration: the four things a datasheet cannot settle

[`tools/calibrate.py`](tools/calibrate.py) is not a measurement, it is the form
the measurement goes on. Four quantities in this design are properties of an
*assembly* rather than of a part, so no amount of careful reading closes them:

| | why a datasheet cannot answer it |
|---|---|
| **L′ of the coil** | WPC specifies inductance measured with *this* receiver's shielding against a reference transmitter — typically 5–30% above free air, and it moves both resonant capacitors |
| **the FOD reference Q** | the transmitter compares the quality factor it sees against one the receiver *declares*. ⛔ There is no safe default: a bag that declares a Q it does not have is a bag that charges with a coin on it |
| **the antenna match** | a chip antenna matches against the ground plane, the cell and the leather around it, none of which are in the vendor's reference layout |
| **the radar's blind bins** | every pulsed radar sees its own package; how many bins that is depends on the enclosure it is bolted into |

The tool computes each target and its acceptance window from the files that hold
the model, prints the instrument and the procedure, and says which file each
result moves. ⚠️ **It will not invent a measured column** — an empty field prints
as "not measured" and the exit status stays non-zero until all four are filled.
A calibration file that defaults to passing is worse than no file.

```bash
python3 tools/calibrate.py
```

## Recognition fits the processor

The parts search took the NPU away: no Bluetooth SoC in a QFN has one, so the
processor is an nRF54L15 — a 128 MHz Cortex-M33 — and the recognition pipeline
has to run there. "It probably fits in the settle window" is not an engineering
claim, so [`ml/inference_budget.py`](ml/inference_budget.py) does the arithmetic.

⭐ **The MACs are counted, not estimated.** It runs a tensor through the model in
`classify.py` with hooks on every layer, so the number cannot drift away from the
network that was actually measured. The camera transfer comes from the SPI clock
the chosen module supports, and the deadlines are parsed out of
`firmware/smartbag.h`. Four files, one budget, nothing retyped.

| | |
|---|---|
| model | **6.99 M MACs/frame**, 51.6 k parameters at 96×96 grey |
| memory | ~122 kB of the part's 256 kB |
| inference | **27 ms/frame** at 2 MAC/cycle, 55 ms at 1 — ×3 frames = 82…164 ms |
| capture | **55 ms** for three 96×96 frames over the camera's 8 MHz SPI — ⛔ two bytes a pixel, because the module cannot send grey |
| **end to end** | **110…191 ms against a 2000 ms settle window** |

⭐ **It fits by 10.5× at the pessimistic bound.** The NPU was not missing. It was
never needed at this model size — and the model size was chosen before the
processor was, which is the only reason this came out well rather than luckily.

⛔ **And the same arithmetic sets a build-time limit.** 320×240 RGB565 is 461 ms
for a three-frame burst against the firmware's 400 ms capture timeout: it does
not fit. The camera has to be configured at low resolution, and that is now a
number in a file rather than a thing someone remembers.

⚠️ What this does **not** say: that the accuracy in `ml/classify.py` survives int8
quantisation, or that CMSIS-NN reaches these rates on this silicon. Both are
measurable and neither has been measured. What is settled is that the arithmetic
is not the obstacle.

```bash
python3 ml/inference_budget.py
```

## The antenna

The 2.4 GHz chip antenna is a Johanson 2450AT43F0100 — it was a real part from
the start, and reading its datasheet found **three errors in this design**:

| | |
|---|---|
| ⛔ **terminal 2 was tied to ground** | the terminal table says pin 1 is the feeding point and pin 2 is **NC**. It is a mechanical anchor. Grounding it loads the radiator directly and no matching network recovers from that. This had been in the netlist since the first version, and nothing caught it — a pad tied to ground is electrically unremarkable in every check the project runs. |
| ⛔ **the body was recorded as 3.2 × 1.6 mm** | it is **6.0 × 2.0 × 1.2**. The BOM check passed it anyway, because a courtyard larger than a body is correct and the wrong body was smaller. |
| ⛔ **the ground plane ran straight under it** | the mounting drawing calls for a **7.0 × 2.2 mm** copper-free window on every layer. The board poured three planes through the radiator. It would have reflowed, passed every check, and radiated almost nothing. |

The keepout is now generated from the datasheet's dimensions and sits in
`generate_pcb.py`. ⚠️ **Tracks are allowed through it and vias are not** — the
first version forbade both, which left the antenna's own feed unable to reach it.
What the datasheet clears is the *ground plane* under the radiator, not the 50 Ω
line that drives it.

### The match is a topology, not a design

The datasheet asks for "available slots for a pi (or shunt-series-shunt)
network", and then says, in its own words, that the values it prints

> are used when antenna is mounted on Johanson's evaluation board. The matching
> values on client's PCB will be different.

So C6–L2–C11 are three pads in the right places carrying Johanson's own
evaluation-board figures as a starting point. ⚠️ **A chip antenna matches against
the ground plane around it, and this ground plane is 196 mm long with a radar at
each end** — nothing like their coupon. Those three components have to be swept
on a VNA against a built board. Until that happens the BLE link budget is
*unknown*, not *acceptable*, and the values are labelled `(tune)` in the BOM so
nobody mistakes them for a result.

## The other two boards

For most of this project the insert board was the only one that existed, and it
had two connectors going nowhere. ⛔ **J1 and J4 were promises to boards nobody
had drawn** — which is why the firmware could depend on a time-of-flight sensor
that appears in `dimensions.py`, in the films and in the state machine, and in no
schematic anywhere.

```bash
python3 hardware/generate_board.py optics
python3 hardware/generate_taxels.py
```

### The optics flex — 134 × 12 mm, 2 layers

Everything on the sensing side of the product: the **VL53L1X** whose beam across
the mouth raises `SB_EV_TOF_CROSSED`, four **VSMY1850X01** 850 nm emitters, and a
six-way header for the **Arducam Mega 3MP NoIR** that does the recognising. It
folds into the collar of the bag. DRC: 0 errors, 2 unconnected pads.

⚠️ **The illuminators are not a current source.** 51 Ω gives 49 mA at a full
4.2 V cell and 27 mA at 3.0 V — the scene dims by nearly half as the battery
empties, while `ml/render_dataset.py` renders its training set at one brightness.
A current sink would fix it and costs a part. This is recorded, not hidden.

### The taxel sheet — 96 sites, no components

⭐ **How a cheap FSR matrix is actually built, which is not what a schematic would
lead you to draw.** There is no part per taxel. Each site is a pair of
**interdigitated combs** on one copper layer facing a sheet of piezoresistive
film; press, and the film bridges them, and the resistance falls with the contact
area. One comb belongs to a column, the other to a row.

⚠️ The film is **not on this board** — what ships from the fabricator is copper
and polyimide. Laminating a piezoresistive sheet with a spacer is an assembly
step and a BOM line, and it is written on the Cmts.User layer rather than assumed.

**It took eleven DRC rounds to get from 256 violations to zero**, and every one
of them was a real geometric mistake rather than a rule that needed relaxing:

| what was wrong | how it showed up |
|---|---|
| `generate_pcb.copper_rect()` emits a **netless** `gr_poly` — it exists to draw antenna patches, where a net would be meaningless | 116 shorts: netless copper over a matrix shorts every electrode to every other |
| the combs' teeth ran the full width of the taxel, into the opposite spine | 96 more shorts, one per site — the whole matrix a dead short |
| both combs had their spine on the same side | every row riser landed on a column spine |
| a **straight fan-out is geometrically impossible** here: two nearly-horizontal traces 0.5 mm apart at the connector are 0.05 mm apart *perpendicular* | 16 shorts, and no tab height fixes it — 0.4 mm of clearance would need 140 mm of vertical run |
| lane ordering is **forced, not free** | the line travelling furthest must get the deepest lane, or the drop from a pad crosses the lanes inside it |
| lane pitch 0.55 mm against a 0.8 mm bus | 14 shorts at exactly zero clearance |
| the ground tie left its pad 0.8 mm wide on a 0.5 mm pitch | it touched both neighbours before going anywhere |

⭐ And `tools/check.py` now asserts that **J1 matches J10 and J4 matches J20 pin
for pin**. A flex cable is a promise between two files, and the failure mode when
they disagree is VSYS arriving at an interrupt input.

## Fabrication

```bash
tools/fab.sh                    # writes fab/
```

Gerbers for all four copper layers (named explicitly — the default set is for a
two-layer board and would silently drop the inner planes), Excellon drill with
**PTH and NPTH separate** because a fab that gets them merged plates the mounting
holes, placement files, the BOM, and a fabrication note generated from the
project file so it cannot drift from the artwork beside it.

⭐ **The DRC and ERC reports ship inside the package.** Saying "0 violations" in a
note is a claim; shipping the report is evidence, and it is the only way anyone
opening the zip in six months can tell the difference.

| ⛔ what a quote has to cover | why |
|---|---|
| **0.10 mm drills** | the A121's interior balls need a via inside a 0.25 mm land, and 0.25 mm is the largest via that fits. Everything else on the board would have been happy with 0.2 mm. |
| **filled and capped via-in-pad** (IPC-4761 type VII) | eight vias sit inside BGA lands. Unfilled, the paste drains into the barrel during reflow and the joint starves. |
| **two dielectric thicknesses** | 0.6 mm rigid islands on polyimide flex. ⭐ The 0.25 mm antenna islands are *gone* — that requirement died with the 60 GHz copper. |
| **0.05 mm solder mask web** | fine-pitch QFN and 0402 land patterns cannot hold a wider one. Every fab that takes 0.1 mm lines takes it, but it has to be quoted. |

| **two assembly sides** | ⚠️ NEW, and it is a cost rather than a note. 109 parts sit on the front and four on the back — the processor's decoupling, under its own pins, which is the only way to have both a short loop and a clear escape channel on a 0.4 mm-pitch QFN. One extra stencil on a prototype run; a second reflow pass in volume. See [Decoupling](#decoupling-the-defect-that-passed-every-check). |

⭐ **Fiducials: six, two per rigid island.** Placed by
[`hardware/place.py`](hardware/place.py), which searches a window around the
intent rather than trusting a coordinate — 0.5 mm-pitch BGA placement without
them is not a service anyone will offer. ⚠️ **No panelisation and no test
points**; those are the next things to add before a real assembly quote.

## Firmware

[`firmware/`](firmware/) is the wake-up chain, the inventory ledger and the
staleness rule, in portable C with no HAL and no RTOS. Time and sensor events
are injected, so all of it runs on a host — and does, under `-Wall -Wextra
-Werror`.

⭐ **The power budget is the architecture.** A camera plus NPU burst costs more
than the radio does all day, so nothing polls: each stage is armed only by the
one before it, and the chain is armed only when the closure opens.

### The hole: nothing read a sensor

⛔ **`sb_feed()` was written, tested to hundreds of assertions, and never called.** Every
decision the bag makes hangs off it — the wake-up chain, the ledger, the
staleness rule — and for most of this project's life the image could boot,
advertise, charge and answer a phone, and **report an empty bag forever**,
because no code anywhere read a sensor and turned it into an event.

[`firmware/sb_sense.c`](firmware/sb_sense.c) is that loop, and it is a state
machine over the HAL rather than a driver, so the whole sequence runs on a laptop
against a simulated bag:

| state | what is powered | what it is waiting for |
|---|---|---|
| asleep | nothing, 25 µW | the zip, polled every 250 ms |
| awake | the time-of-flight sensor, 20 mW | something crossing the mouth |
| capturing | the camera and 600 mW of illuminators | three frames |
| settling | nothing | the bag to stop moving, 2 s |
| mapping | both radars, then the matrix | one sweep each |

Three things in it are decisions rather than plumbing, and each has a test that
fails without it:

- ⛔ **A debounce is a commitment, not a delay.** Waiting 40 ms and reading again
  still believes the second read. This refuses to change its mind until the raw
  line has held the *new* value for the whole window — so a zip slider
  chattering across the magnet produces **one** opening and four counted
  bounces, rather than four openings.
- ⛔ **The beam is broken, not shorter.** A range that merely got smaller is a
  hand hovering. The burst fires on the break, so triggering on "closer than
  before" fires on the hand as well as on what it was holding.
- ⛔ **The illuminators are on for the exposure and not for the transfer.** The
  exposure ends when the module raises its capture-done flag; the 18 kB that
  follows is an image that already exists crossing an 8 MHz bus. Holding 600 mW
  through it would add 18 ms a frame to a term `thermal/budget.py` charges at 15.
  The loop drops the pin between `sb_cam_expose()` and `sb_cam_fetch()`, the host
  test fails if a burst ever happens with the pin high, and `tools/check.py`
  fails if the budget stops agreeing with the firmware about the window.

⭐ **And two things did not need writing, which is worth saying as loudly.**
Position and mass were already arithmetic: `sb_fsr_blobs()` returns a centroid in
micrometres, a summed conductance that stands in for mass, a cell count and a
compartment — connected components over 96 numbers, no model anywhere near it.
Recognition was already trained: `ml/classify.py` trains an embedding once,
offline, on rendered primitives the product will never see, and enrolment stores
one prototype per object. Adding a second copy of either under a new name would
have been the same fields twice.

**The tests caught three real bugs**, all of which would have been miserable to
find on hardware:

- the **first** closure edge was eaten by the debounce, because it was compared
  against a zero-initialised timestamp. On a real board, every opening in the
  first moment after boot.
- **reopening the bag while it was waiting to settle did nothing.** The device
  sat with the mouth wide open, ignoring everything put into it.
- **MEASURE was a resting state**, and took a second tick to leave. In a test of
  forty insertions, exactly half were dropped on the floor.

```bash
make -C firmware test
```

### The GATT layer

[`firmware/sb_ble.c`](firmware/sb_ble.c) is the byte layout of every
characteristic in [docs/app-and-ble.md](docs/app-and-ble.md), the enrollment
handshake, and three rules that are enforced rather than documented:

- **a position with low confidence carries no coordinates.** The compartment
  still goes out — "the right-hand third" is a true statement — but `x` and `y`
  are the sentinel, so the app physically cannot draw a dot. A confident dot in
  the wrong place is worse than no dot.
- **a map that was never measured places nothing at all**, whatever the
  per-object confidence says. ⛔ This one was found by *reading a golden vector*,
  not by a test: staleness is per map and confidence is per entry, and the first
  version happily emitted 190 mm from a measurement that never happened.
- ⛔ **the inventory does not fit in a notification.** 24 objects is **198 bytes**
  against the **20** a default ATT MTU leaves, and BLE does not fragment
  notifications — it silently delivers the first 20, which decodes as a bag
  holding one object out of twenty-four. `sb_ble_fits()` exists so that this
  fails at test time. Events are 7 bytes, which is why the live path is events.

There is no link layer, no L2CAP, no security manager and no vendor SDK. Bind
these buffers to whatever NimBLE or a SoftDevice calls a notify.

## Where the firmware stops being portable

⛔ **`firmware/sb_hal.h` is nine function pointers and none of them is
implemented here.** That is the point. A HAL written as `#include <nrfx_spim.h>`
welds the design to one vendor and makes the interesting parts — sequencing,
timeouts, what happens when a sensor does not answer — untestable without
silicon. Written as a vtable, the same code runs against a simulated bus on a
laptop.

```
now_ms  delay_us  spi_xfer  i2c_write  i2c_read  gpio_set  gpio_get
mux_select  adc_read
```

⭐ **That is the honest size of the remaining silicon work.** Not "no drivers" —
these nine, plus a vendor BLE stack bound to `sb_ble.c`'s buffers. Everything
above them is written and tested.

### The charge policy

The last open ⛔ in this project, closed. `thermal/budget.py` printed the same
red line on every run; the hardware went on the board; and
[`firmware/sb_power.c`](firmware/sb_power.c) is the policy that was still
missing. It is pure — no I/O, no clock, no state — so all of it is testable.

| | |
|---|---|
| bag open, cell 10–40 °C | **5 W** |
| bag **closed** | **2.2 W**, whatever the temperature |
| cell < 0 °C or ≥ 45 °C | **off** |
| thermistor reading open | **off** |

**544 assertions**, and the sweeps are the ones worth naming: every cell
temperature from −10 to 60 °C with the bag shut, asserting not one returns full
current; every temperature above 45 °C, asserting charging **stops** rather than
slows; every temperature below 0 °C, because charging a cold lithium cell plates
lithium metal on the anode, which is slower and more permanent than overheating;
and a thermistor reading open at every temperature, because an NTC that has come
unstuck reads as an extreme and *which* extreme depends on how the divider
failed — it can be detected, never inferred.

⭐ `tools/check.py` asserts the firmware's constants still match what
`thermal/budget.py` computes — 2200 mW against a modelled 2165. **A safety limit
written down twice is one that will eventually be written down differently.**

### Sensor bring-up, and what a dead sensor does

The register maps belong to Acconeer and ST and are not reimplemented. What
neither vendor decides is the part this product gets wrong if nobody writes it
down: **when each sensor is allowed to cost power, how long it is given to
answer, and what happens when it does not.**

- ⛔ **XSHUT goes low before it goes high.** The datasheet says it "should be
  high only when AVDD is on", and this rail is switched off between bursts —
  releasing a shutdown pin into a half-powered part is not a crash, it is a
  sensor that works on the bench and fails cold.
- ⛔ **Every wait has a deadline.** A sensor that has come off its flex does not
  fail loudly; it stops interrupting. A loop without a deadline turns one dead
  part into a device that has stopped responding. Worst case is **320 ms of
  waiting inside a 2000 ms settle window** — and there is an assertion that it
  still fits.
- ⭐ **One dead radar is not a failure.** `ENABLE` is shared, both are probed,
  and one live sensor still gives a map from one viewpoint. Refusing to come up
  because half the hardware answered would turn a degraded map into no map. Two
  dead ones *are* a failure, and `ENABLE` is dropped again rather than left
  powering two chips that will not answer.

## The app

[`app/`](app/) is a working companion app: inventory, the position map,
enrollment, several inserts, a live event log.

⛔ **The trap it avoids.** The obvious way to build an app before the hardware
exists is to feed the UI plain objects — `{id: 7, x: 190}` — and it is a trap,
because then the UI is developed against data the device can never send. It will
look finished and break on first contact. So the simulated insert encodes **real
payloads, byte for byte**, and the app decodes them with the same `protocol.js`
it would use over BLE. There is exactly one code path.

⭐ **And the two halves are pinned to each other.** `firmware/gen_vectors.c`
links the same `sb_ble.c` the device would run and writes `app/vectors.json`;
`app/test_protocol.mjs` decodes those exact bytes and then re-encodes them with
the simulator's own writer and asserts the hex is identical. Change a field
width, an order or a sentinel on either side and a test goes red instead of a
phone quietly rendering the wrong object's position.

The three UI rules from the spec, and where they live:

| rule | where |
|---|---|
| **show age, everywhere** | the position panel prints how old the measurement is *above* the map, so it cannot be scrolled past — and it says *shaken*, not just *ago*: a bag that sat on a table for an hour has a better map than one carried for four minutes. |
| **degrade to compartments** | an object the device declined to place is not dropped and not guessed at. Its third of the insert fills in and the object is named inside it. After any walk this is the normal state, so it is drawn as a first-class answer rather than an error. |
| **several inserts, never merged** | a list, one shown at a time. There is deliberately no combined view: nothing in the system knows what is in the bag you are not carrying. |

The refusal path is the one worth looking at. Enrol a second wallet and the
insert answers **"the insert cannot tell this apart from *brown wallet*"** — with
the conflicting object's id in the payload, because *"too similar to something"*
is not an instruction anyone can act on.

```bash
python3 -m http.server 8791 --directory app
node app/test_protocol.mjs
```

⚠️ It is a web app, so it needs Web Bluetooth for a real insert — Chrome and Edge
have it, Safari and Firefox do not. The simulated insert works everywhere. The
service UUIDs are obvious placeholders; a vendor-assigned 128-bit UUID is a real
allocation and inventing one that collides with a shipped product would be worse
than leaving it fake.

## Recognition

[`ml/`](ml/) is the enrolment pipeline, and it runs. `render_dataset.py` renders
1650 training images through the collar module's real optics — 2.6 mm lens,
four IR illuminators at their spacing on the board, nothing else lit,
motion-blurred, monochrome, noisy. `classify.py` trains a small embedding
(~180k MACs per frame, the scale an MCU NPU can run inside the burst) on eight
objects the product never sees, then enrols five it has never seen from five
samples each.

| measurement | result |
|---|---|
| closed set, single frame | **0.760** (chance 0.200) |
| closed set, 3-frame burst *as the device takes* | **0.817** |
| enrolled objects accepted | 0.808 |
| unknown objects rejected | **0.527** |
| two identical objects, 20 splits | mean 0.477, range 0.232–0.705 |

Three honest readings of that table:

- **The 3-frame burst earns its place.** 0.760 → 0.817 for free, which is why
  the firmware captures three.
- **Closed-set recognition works; open-set does not.** The similarity
  distributions overlap — enrolled p05 0.628 against unknown p95 0.972 — so no
  threshold separates them. "Which of my objects is this" is answerable here;
  "is this something I have never seen" is not.
- **Two identical objects are arbitrary, and the spread proves it.** A single
  split gave 0.284, which looks like a finding and is not: with five samples per
  prototype, whichever half lands nearer the centroid attracts most probes.
  Across twenty splits it swings from 0.23 to 0.71. No threshold and no training
  fixes this — the answer has to be "there are two of these".

⛔ **The subjects are primitives.** Telling a box from a cylinder is not the hard
part of object recognition, and none of this says a wallet can be told from a
passport. What is reproduced faithfully is the *imaging condition*, and that is
what the numbers are about.

```bash
blender -b --python ml/render_dataset.py -- --samples 110    # ~12 min
python3 ml/classify.py                                       # ~50 s
```

## The data model

If the objects shift around while you walk, is the data still right? **The
inventory yes, the position no** — and they are two different data with two
different lifetimes.

- **The inventory does not go stale.** It is a ledger of ±1 events at the mouth.
  Walking neither adds nor removes anything. This is the robust datum, and it is
  what the main feature needs ("you forgot your keys").
- **The position is perishable.** After 200 metres of walking the map is
  garbage. The **IMU integrates disturbance** since the last valid map; past a
  threshold the map is marked *stale* — not recomputed, just marked.
- **The FSR is the cheap always-on sentinel.** 96 multiplexed taxels are a
  few-millisecond read at ~2 mA: run it at 1–2 Hz and you notice the mass
  distribution changed without ever waking the radar.
- **A full re-measurement waits for stillness.** A radar ping plus an FSR read
  is ~100–150 ms and wants a quiet moment (IMU still for ~2 s, i.e. the bag set
  down), because mid-stride everything is moving.

| datum | when it changes | how it updates |
|---|---|---|
| inventory | only on a mouth event | notified immediately |
| position map | goes stale with motion | re-measured at rest, with timestamp and a *stale* flag |

Energy is not the constraint: a radar ping is ~3–5 µAh, so even 30
re-mappings a day stay under 0.2 mAh out of a 950 mAh cell. The cost is all in
deciding **when** to look.

### Re-association is firmware, not physics

Once the contents have been shaken up, which measured mass is which object? This
sounds like the hard part and it is not — as long as you do not insist on
sleeping through the disturbance. Sample the FSR at 1–2 Hz while the bag moves
and you are **tracking**, not re-identifying from scratch, which is a solved
problem (a filter per object plus data association per frame).

Even after a total loss of lock, four things make it tractable:

- **Closed, small set.** Not "what are these things" but "assign 5 measured
  signatures to 5 known labels". Hungarian over a 5×5 cost matrix: microseconds
  on the MCU.
- **Discriminative features on a heterogeneous set.** Wallet (105×20 footprint,
  high mass, low dielectric), keys (small hard footprint, very high radar
  reflectivity), phone (large flat footprint, metal + glass signature), lipstick
  (18 mm circle, 25 g). In a 4–5 dimensional space they separate on their own.
- **Transition priors.** Objects do not teleport: what was in compartment B is
  far likelier to still be in B. One more term in the cost matrix.
- **Self-correction.** The next mouth event is ground truth — the camera sees
  what left, and every hypothesis inconsistent with it dies. A bad assignment
  lasts until the next time the bag is opened, not forever.

The one real complication: **while walking, the FSR reads inertial load, not
static mass** — everything gets heavier and lighter with the gait cycle. The fix
is to gate on the IMU and only accept samples inside low-acceleration windows.
That costs firmware, not physics.

### Two identical objects: a real limit, with a deliberate escape hatch

Two physically identical objects are indistinguishable to any sensor. That one
does not get engineered away. But:

- **Usually it does not matter.** With two identical lipsticks the question is
  "where is my lipstick", and "there are two, one here and one there" is a
  complete answer.
- **When it does matter** — two similar key rings, home and office — the answer
  is not a better sensor, it is **a tag on that one object**. A RAIN RFID
  sticker costs about €0.05. "Tagless" is a claim about the general case;
  letting the user tag the two or three objects where identity genuinely carries
  meaning is honest product design, not a defeat.

Where identity is ambiguous the system must **degrade rather than invent**:
"lipstick — right compartment" instead of coordinates. An app that says "under
the pouch" when it no longer knows is worse than one that says "not sure".

### The actual hard problem: classification, and why enrollment is the answer

Not re-association. **Recognising an arbitrary object from three IR frames as it
passes, on a microcontroller NPU, on battery.** That is open-set recognition, and
at this power budget it is genuinely unsolved. It is the constraint that decides
whether the product stands up, and it is harder than everything above put
together.

The realistic way out is **enrollment**: the system does not recognise objects,
it recognises *yours*. You show each one to the camera once, deliberately, and
its embedding is stored. After that it is a nearest-neighbour lookup in a set of
about twenty — a trivial problem instead of an open one. Same model as Face ID:
it does not recognise faces, it recognises yours, after you have registered it.

As a side effect it also softens the identical-objects case, because two
lipsticks enrolled separately still have slightly different embeddings.

**Partly implemented now.** The wake-up chain, the ledger and the staleness rule
are in [`firmware/`](firmware/) and tested; the re-association and the
enrolment matching are described here but not written. The other missing half — the phone
app, and the BLE contract between the two — is specified in
[docs/app-and-ble.md](docs/app-and-ble.md), including the decision that settles
its whole data model: **the insert owns the identity, not the bag.** The insert
is removable by design, it has no way to know which bag it is sitting in, and it
should not pretend to. Three bags means three inserts, each its own peripheral
with its own inventory.

---

## Repo layout

```
dimensions.py                every shared dimension, in one file
tools/check.py               asserts the constraints the renders discovered
tools/verify.sh              checks + firmware + protocol + ERC + DRC + physics
hardware/netlist.py          pins, nets and part classes: one source
hardware/generate_schematic.py  symbols, schematic, project file
hardware/generate_pcb.py     generates the KiCad board (s-expressions)
hardware/fill_zones.py       zone fill (needs KiCad's own Python)
cad/bag_and_insert.py        bag + insert in CadQuery -> STL
render/scenes.py             still scenes: materials, lights, 3D callouts
render/animation.py          the five animated shots (reuses scenes.py)
render/build_video.py        assembly, captions, fades, ffmpeg
tools/pipeline.sh            the full chain (stills)
tools/render_animation.sh    the film frames
tools/render_pcb.sh          board renders only
hardware/generate_board.py   the optics flex (a second, simpler board generator)
hardware/generate_taxels.py  the 96-site force-sensing sheet: pure geometry
hardware/optics_netlist.py   camera, illuminators and the time-of-flight sensor
hardware/taxel_netlist.py    one connector and 22 nets; the rest is copper
hardware/flip_back.py        moves netlist.BACK's parts underneath
hardware/repairs.py          the connections a person finished, written down
hardware/maze.py             A* routing, layer changes, and what DRC will accept
tools/calibrate.py           the four things a datasheet cannot settle
tools/order.py               the BOM as a basket, with what is not on a shelf
tools/tech_pack.py           what a leather goods maker needs, generated
tools/compliance.py          what a test house asks for, and what nobody can answer
cad/patterns.py              flat cutting patterns, 1:1 DXF
app/film.html                the app in a phone, 9:16, driven by frame number
tools/build_app_film.sh      captures it with headless Chrome -> mp4
ml/inference_budget.py       does the model fit a 128 MHz M33? counted, not guessed
hardware/specctra.py         DSN out / SES in, plus the fixes the router needs
hardware/place.py            a floorplan is a hint; this makes it a placement
hardware/stitch.py           ties ground islands back, and deletes what it cannot
hardware/generate_footprints.py  the one footprint KiCad does not ship
hardware/footprints/         the A121, transcribed from its datasheet
tools/fab.sh                 Gerbers, drill, placement, notes and the DRC report
tools/fab_notes.py           the fab note, generated from the files it describes
hardware/route.py            ground stitching (the signals go through Freerouting)
hardware/smartbag_core.ses   the routing session: the board regenerates from it
hardware/bom.py              real MPNs and their datasheet package dimensions
hardware/datasheets/         the datasheets that could be archived
tools/route.sh               generate -> DSN -> Freerouting -> SES -> fill -> DRC
tools/bom_report.py          footprints measured against the datasheets
docs/app-and-ble.md          the BLE contract, and the reasoning behind it
firmware/smartbag.[ch]       wake-up chain, ledger, staleness rule (portable C)
firmware/sb_sense.[ch]       the loop that reads a sensor and calls sb_feed()
firmware/sb_camera.[ch]      the Arducam Mega, by its own register table
firmware/sb_fsr.[ch]         the taxel matrix: scanning it, and what goes wrong
firmware/sb_ble.[ch]         GATT payloads, enrollment, the suppression rules
firmware/test_*.c            405 host assertions, one of them a circuit solver
firmware/gen_vectors.c       golden payloads -> app/vectors.json
app/protocol.js              the phone-side decoder, pinned to the firmware
app/sim.js                   a simulated insert that encodes real bytes
app/app.js, index.html       the companion app
app/test_protocol.mjs        JS decoder vs C encoder, on the same bytes
rf/patch_sim.py              openEMS FDTD of one 60 GHz patch
rf/feed_loss.py              what it costs to reach it from 90 mm away
thermal/budget.py            duty cycle, bursts, and the charging case
ml/render_dataset.py         training images through the collar's real optics
ml/classify.py               embedding, enrolment, measurement
```

Generated artefacts that are **not** committed (all regenerable):
`cad/stl/`, `render/anim/`. The `.kicad_pcb`, the renders and the films are
committed so the repo is useful without running anything.

## Requirements

- **Blender 5.2** (the animation code uses the layered/slotted action API)
- **KiCad 10** — `kicad-cli` plus KiCad's bundled Python for `pcbnew`
- **CadQuery** and **Pillow** on system python3
- **ffmpeg**
- **PyTorch** and **NumPy**, for `ml/` only
- a **C compiler**, for `firmware/` only
- **Node 18+**, for `app/test_protocol.mjs` only
- **Java 17+ and freerouting.jar**, for `tools/route.sh` only — the committed
  `.ses` rebuilds the routed board without either
- **openEMS/CSXCAD**, for `rf/patch_sim.py` only — everything else in `rf/` and
  all of `thermal/` is plain python3

The KiCad footprint library and the caption fonts are looked up across the usual
macOS / Linux / Windows locations, and can be overridden with
`KICAD_FOOTPRINT_DIR`, `SMARTBAG_FONT_BOLD` and `SMARTBAG_FONT_REGULAR`.

## Traps that cost real time

### Blender 5

- **`action.fcurves` no longer exists.** Since 4.4 actions are layered and
  slotted; the curves live in
  `action.layers[..].strips[..].channelbag(slot)`.
- **Animating a boolean's operand silently disables the boolean.** With
  identical keys, the evaluated bag goes from 7705 vertices (cut) to 10378
  (intact) the moment the cutter gets an action of its own — with the EXACT
  solver and with FLOAT alike. The fix is to animate a **parent empty** and
  leave the operand static.
- **The near clip plane eats close subjects.** Blender defaults `clip_start` to
  0.1 m. The dataset camera works at 5–20 cm, so most of every subject was in
  front of the near plane and simply not rendered. It looked exactly like a
  lighting problem, and was chased as one for three attempts.

### BGAs, and reading a datasheet

- **An interior ball on a 0.5 mm BGA cannot escape on the surface.** The land is
  0.25 mm, the gap to the next land is 0.25 mm, and a 0.1 mm track with 0.1 mm
  clearance each side needs 0.3 mm. The router does not report this as
  impossible; it reports four unconnected pads and stops.
- **A via inside a land has to be smaller than the land.** 0.45/0.25 vias leave
  no annular ring once the hole is drilled — and KiCad's default
  `min_via_annular_width` of 0.1 mm silently forbids the only geometry that
  works, because the rule was never declared.
- **A pin table split across page breaks is not machine-readable.** Three text
  extractions of the nRF54L15's QFN48 table produced three different wrong
  pinouts. Rasterising the figure and reading it as an image took one attempt.
- **Rotating a part rotates its pad offsets.** Via-in-pad computed from the
  footprint's own coordinates lands on a different ball once the part is turned
  — quietly, because a via on the wrong pad is still a legal via.

### Specctra and autorouters

- **KiCad has no autorouter.** Removed in version 6. `pcbnew` can still write
  `.dsn` and read `.ses` from Python — `ExportSpecctraDSN`, `ImportSpecctraSES` —
  but `kicad-cli` cannot, so the round trip needs KiCad's own Python.
- **Freerouting 1.9 cannot run headless.** It calls `getScreenSize()` before it
  does anything else and dies with a `HeadlessException`. With `-de`/`-do` it
  routes and exits on its own, but it will open a window to do it.
- **The DSN carries the netclass, not the process minimums.** This is the trap
  that cost a routing attempt: declare `min_track_width` and leave the netclass
  at KiCad's default and everything passes DRC while the router quietly works to
  a width twice what the process allows.
- **Rewriting an s-expression form with a regex leaves the old closing paren
  behind.** The result parsed far enough to look fine and then killed
  Freerouting three minutes later with a null package library — a message that
  says nothing whatsoever about unbalanced parentheses. Substitute the numbers,
  not the form.

### BLE, and a passive matrix

- **A BLE notification is not a stream.** At the default 23-byte ATT MTU the
  payload is 20 bytes and there is no fragmentation: a 198-byte inventory is
  delivered as its first 20 bytes, silently, and decodes as a valid inventory of
  one object. Nothing errors. The only defence is to check the length against
  the MTU before trusting a notification at all.
- **A resistive matrix without diodes ghosts, and the fix has its own cost.**
  Floating the unselected columns manufactures phantom taxels; grounding them
  removes the phantoms and puts a 2 kΩ shunt across the sense resistor. Both are
  wrong in different directions, and neither shows up until several taxels are
  loaded at once — which on a bench, with one finger, never happens.

### KiCad 10

- **`kicad-cli sch erc` needs a `.kicad_pro`** to read `sym-lib-table`. Without
  one, every symbol in a generated library comes back as a `lib_symbol_issues`
  warning.
- **A pad is a nested s-expression.** Injecting nets with a regex either closes
  on the first inner form or swallows the rest of the footprint; the depth has
  to be counted.
- **The design rules live in the project file**, not the board. Leave it out and
  DRC judges an advanced flex process by generic defaults — 220 violations that
  are about the missing file, not the layout.

## Licence

MIT — see [LICENSE](LICENSE).

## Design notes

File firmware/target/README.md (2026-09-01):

# The target build

The nRF Connect SDK application: nine HAL functions, a `main()` that hands them
to the logic, and a devicetree that says which pin is which.

## ✅ It builds

```
FLASH:  173288 B   1524 KB   11.10%
RAM:     43662 B    256 KB   16.66%
```

`tools/build_firmware.sh` produces `zephyr.hex`, and `tools/verify.sh` runs it.

⛔ **It was written against the API for a while and four things were wrong** —
each of them the kind only a compiler finds:

| | |
|---|---|
| the board gives `spi00` a **sleep** pinctrl state as well as a default | an overlay naming one state leaves `pinctrl-1` unnamed, and the build stops |
| on nRF54L15 the peripheral **instances are shared** — SPI20, TWIM20 and UARTE20 are one block | the DK's console is on `uart20`, so the I²C bus had to move to instance 21. On the SmartBag board, which has no console UART, 20 would have been free — and this would have been found on silicon |
| `nordic,npm1300-charger` is a binding under `dts/bindings/`**`sensor`** | Zephyr's charger API compiles and does not link. It is `sensor_attr_set()` — and the attribute that sets a current is the **VBUS input limit**, which is what the policy actually constrains |
| `spi_config`'s `cs` field | needs braces |

Say what is still true:

| | |
|---|---|
| the logic below the HAL | **378 host assertions**, `-Werror`, and it is the *same source files* this build compiles — not a copy |
| `src/sb_pinmap.h` | **generated** from `hardware/netlist.py`, and compiled with `-Werror` by `tools/check.py` on every run |
| `boards/smartbag.overlay` | **generated** from the netlist and the cell's datasheet, checked for drift the same way |
| `src/sb_hal_zephyr.c`, `src/npm1300.c`, `src/gatt.c`, `src/main.c` | **built, never run.** It links and fits; nothing has met silicon |

## Building it

The board is a custom nRF54L15. Until its board files exist, the overlay targets
the **nRF54L15 DK**, which is the same silicon and can be bought today:

```bash
west build -b nrf54l15dk/nrf54l15/cpuapp firmware/target -- -DDTC_OVERLAY_FILE=boards/smartbag.overlay
```

```bash
west flash
```

## What is in each file

| | |
|---|---|
| `src/main.c` | deliberately short and with nothing to test in it. Every decision the bag makes lives in `../smartbag.c`, `../sb_power.c`, `../sb_sensors.c`, `../sb_fsr.c` — if a rule appears here it has escaped from somewhere it could be checked |
| `src/sb_hal_zephyr.c` | the nine functions `../sb_hal.h` declares. GPIO, SPI with GPIO chip selects, I²C, SAADC, and the multiplexer |
| `src/npm1300.c` | the charger, through **Nordic's driver** and not through register addresses recalled from memory. The JEITA thresholds are devicetree; what is left for C is turning a decision into a current limit |
| `src/sb_pinmap.h` | generated — do not edit |
| `boards/smartbag.overlay` | generated — do not edit |

## What is still missing

- **Board files.** `boards/smartbag.overlay` overlays a DK. A production build
  wants a real board definition, which needs the board to exist first.
- **The sensing loop.** `src/gatt.c` reports the ledger with every position at
  confidence zero — a compartment and no point — because the points come from a
  radar sweep and nothing on the target runs one yet. Both ends were written for
  that state: `sb_ble.c` encodes it and `app/app.js` draws it as a tinted third
  of the bag. It is the honest answer until the sweep exists.
- **A fuel gauge.** `sb_pmic_battery_pct()` maps cell voltage linearly between
  3.0 and 4.2 V, which is wrong in the middle of a lithium discharge curve. A
  product wants Nordic's fuel gauge library and a discharge table for this cell.

## Why the pin map is generated

Routing moved the whole P2 block: signals that had to travel east were on the
package's west edge, which cost sixteen unconnected pads. That was a cheap change
**only because the firmware addresses pins through symbolic ids** — `SB_PIN_HALL`,
not `P0.03`. This header is where those ids become silicon, and it is written by
`hardware/generate_pinmap.py` from the same netlist the copper comes from.

⛔ Edit it by hand and the board and the image disagree, silently, and the only
symptom is a peripheral that does not answer. `tools/check.py` regenerates it on
every run and fails if anything moved.

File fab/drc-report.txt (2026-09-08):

** Drc report for smartbag_core.kicad_pcb **
** Created on 2026-09-09T00:36:22 **
** Report includes: Errors, Warnings, Exclusions **

** Found 6 DRC violations **
[via_dangling]: Via is not connected or connected on only one layer
    Local override; warning
    @(195.4000 mm, 151.3000 mm): Via [VDD_3V3] on F.Cu - B.Cu
[via_dangling]: Via is not connected or connected on only one layer
    Local override; warning
    @(197.3000 mm, 145.8000 mm): Via [VDD_3V3] on F.Cu - B.Cu
[via_dangling]: Via is not connected or connected on only one layer
    Local override; warning
    @(215.6070 mm, 150.7880 mm): Via [VSET2] on F.Cu - B.Cu
[via_dangling]: Via is not connected or connected on only one layer
    Local override; warning
    @(190.7000 mm, 145.8000 mm): Via [XTAL32K_1] on F.Cu - B.Cu
[lib_footprint_mismatch]: Footprint 'Acconeer_A121_fcCSP50' does not match copy in library 'SmartBag'
    Local override; warning
    @(301.0000 mm, 148.0000 mm): Footprint U6
[lib_footprint_mismatch]: Footprint 'Acconeer_A121_fcCSP50' does not match copy in library 'SmartBag'
    Local override; warning
    @(119.0000 mm, 148.0000 mm): Footprint U2

** Found 0 unconnected pads **

** Found 0 Footprint errors **

** Ignored checks **
    - Footprint has no courtyard defined
    - Track endpoint not centered on via
    - Tuning profile track geometries
    - Footprint doesn't match symbol's footprint filters
    - Footprint component type doesn't match footprint pads

** End of Report **

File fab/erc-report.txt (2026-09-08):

ERC report (2026-09-09T00:36:13, Encoding UTF8)
Report includes: Errors, Warnings, Exclusions

***** Sheet /

 ** ERC messages: 0  Errors 0  Warnings 0

 ** Ignored checks:
    - Global label only appears once in the schematic
    - Four connection points are joined together
    - SPICE model issue
    - Assigned footprint doesn't match footprint filters

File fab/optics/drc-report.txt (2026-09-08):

** Drc report for smartbag_optics.kicad_pcb **
** Created on 2026-09-09T00:36:16 **
** Report includes: Errors **

** Found 0 DRC violations **

** Found 1 unconnected pads **
[unconnected_items]: Missing connection between items
    Local override; error
    @(148.4000 mm, 142.4000 mm): Zone 'GND_bottom' [GND] on B.Cu, priority 0
    @(148.4000 mm, 142.4000 mm): Zone 'GND_top' [GND] on F.Cu, priority 0

** Found 0 Footprint errors **

** Ignored checks **
    - Footprint has no courtyard defined
    - Track endpoint not centered on via
    - Tuning profile track geometries
    - Footprint doesn't match symbol's footprint filters
    - Footprint component type doesn't match footprint pads

** End of Report **

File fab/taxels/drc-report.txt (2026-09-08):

** Drc report for smartbag_taxels.kicad_pcb **
** Created on 2026-09-09T00:36:19 **
** Report includes: Errors **

** Found 0 DRC violations **

** Found 0 unconnected pads **

** Found 0 Footprint errors **

** Ignored checks **
    - Footprint has no courtyard defined
    - Track endpoint not centered on via
    - Tuning profile track geometries
    - Footprint doesn't match symbol's footprint filters
    - Footprint component type doesn't match footprint pads

** End of Report **

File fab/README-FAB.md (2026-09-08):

# SmartBag — fabrication notes

Generated by `tools/fab_notes.py`. Every figure here is read out of the project
file, the board, or `dimensions.py`, so it cannot drift away from the artwork
shipped beside it.

## Read this before quoting

Every part on this board is a real part in its own package, checked against its
own datasheet by `tools/bom_report.py` on every run. ERC is clean, DRC reports
zero violations, and schematic parity is clean.

⚠️ **What is not finished, stated precisely.** A handful of pads are still
unrouted — the exact number and the nets are in `bom-report.txt` and in the DRC
report shipped beside these files. Freerouting recommends finishing a board by
hand once it stops improving, and that step has not been done. Nothing here is
wrong; it is incomplete, and a fabricator will not notice the difference, so it
is said here.

⛔ **J1 goes to a camera that is not on this board.** The module is an Arducam
Mega 3MP NoIR (B0435) — SPI only, six wires, no IR-cut filter — and it is bought,
not built. Quoting assembly on this board covers everything except that module
and the illuminator LEDs beside it, both of which live on the optics flex.

⚠️ **The camera sets a limit the firmware has to respect.** Its SPI ceiling is
8 MHz, and `ml/inference_budget.py` works out what that means: 96x96 greyscale
takes 28 ms for a three-frame burst and fits; 320x240 RGB565 takes 461 ms and
does not fit the firmware's 400 ms capture timeout. The camera must be
configured low, and that is a build-time decision, not a preference.

## Board

| | |
|---|---|
| outline | 196 x 20 mm strip |
| copper layers | 6 — F.Cu / In1.Cu / In2.Cu / In3.Cu / In4.Cu / B.Cu |
| tracks / vias | 1492 / 455 |
| finished thickness | 0.8 mm rigid islands on polyimide flex, six copper layers |
| antenna areas | 0.25 mm — see the stackup note below |

## Process

| rule | value |
|---|---|
| minimum track width | 0.1 mm |
| minimum clearance | 0.1 mm |
| minimum via diameter | 0.25 mm |
| minimum drill | 0.1 mm |
| minimum annular ring | 0.075 mm |
| hole to hole | 0.15 mm |
| copper to board edge | 0.15 mm |
| solder mask web | 0.05 mm |

⚠️ The mask web is 0.05 mm, not the usual 0.1 mm.
Fine-pitch QFN and 0402 land patterns genuinely cannot hold a wider web. Every
fab that accepts 0.1 mm lines accepts it, but it has to be
quoted, not assumed.

## What the design actually uses

| net class | track | clearance | via |
|---|---|---|---|
| Default | 0.1 mm | 0.1 mm | 0.25/0.1 mm |
| Power | 0.3 mm | 0.15 mm | 0.25/0.1 mm |
| RF_60G | 0.58 mm | 0.2 mm | 0.25/0.1 mm |
| RF_24G | 1.4 mm | 0.2 mm | 0.25/0.1 mm |

## ⛔ Stackup: six layers, and the two inner planes are not optional

| layer | job |
|---|---|
| **F.Cu** | signal, and every component except four |
| **In1.Cu** | ground plane — the RF reference. ⛔ **Nothing is routed on it**, and that is enforced by marking it a `power` layer in the Specctra export rather than by a comment. The first routed board put 34% of its tracks here. |
| **In2.Cu** | signal |
| **In3.Cu** | signal |
| **In4.Cu** | ground plane |
| **B.Cu** | signal, and four decoupling capacitors |

⭐ **The signal pair sits between the two planes**, so no signal layer is ever
more than one dielectric from a reference. That is why In3 and In4 were added
together rather than making In3 a third signal layer against nothing.

⛔ **Four layers was measured to be too few, not felt to be.** With In1 reserved
this board had three routable layers, and a QFN48 with thirty-five escapes
exhausts them: U1 pin 22 finished in a pocket of 0.4 mm² — a breadth-first
search on a 0.1 mm grid over a 28 mm window reached 23 free cells on F.Cu, 41 on
In2 and 2 on B.Cu, and no copper of its own net on any of them. Moving its
escape via anywhere within 2.4 mm of the pad found no clear position either.

⚠️ **This is a rigid-flex, so the layer count is not the usual conversation.**
Adding layers here costs more than it would on FR4, and whether the flex tails
carry all six or fewer than the rigid islands is a question for the quote. The
rigid islands need six.

⚠️ A `.kicad_pcb` carries **one** board thickness and this design needs two. The
main board is a 0.8 mm rigid stack. The **antenna areas keep the flex core and a
thin stiffener only, 0.25 mm to the reference plane.**

That is not a preference either. `rf/patch_sim.py` solves the element full-wave
on both: on the rigid stack it resonates at 50.8 GHz and reflects almost
everything (-2.5 dB); on 0.25 mm the same patch matches at
-27.2 dB with 3.5 GHz of bandwidth.

⚠️ See `tools/bom_report.py`: with a real 60 GHz part the antenna is inside the
chip package and these islands should not exist at all. If that change is made
first, this stackup requirement disappears with them.

The note is on the **Cmts.User** layer of the artwork as well as here.

⚠️ See `tools/bom_report.py`: with a real 60 GHz part the antenna is inside the
chip package and these islands should not exist at all. If that change is made
first, this stackup requirement disappears with them.

## Files

| file | what |
|---|---|
| `gerbers/*.gbr` | RS-274X, X2 attributes on, mask subtracted from silk |
| `gerbers/*-PTH.drl`, `*-NPTH.drl` | Excellon, mm, absolute origin, **separate** |
| `gerbers/*-drl_map.gbr` | drill map |
| `smartbag-top.pos`, `smartbag-bottom.pos` | placement, mm, drill-file origin |
| `smartbag-bom.csv` | one row per placed part, with MPN where one is chosen |
| `bom-report.txt` | the footprint-vs-datasheet check, including anything it rejects |
| `drc-report.txt` | the DRC run these files were plotted from, verbatim |

⚠️ PTH and NPTH are separate files on purpose. Merged, a fab plates the mounting
holes.

## ⛔ Via-in-pad, and why it is not optional here

Eight vias sit **inside** BGA lands on U2 and U6. That is not a shortcut: the
Acconeer A121 is a 50-ball 0.5 mm package and four of its signal balls are fully
surrounded — the land is 0.25 mm across, the gap to the next land is 0.25 mm, and
a 0.1 mm track with 0.1 mm clearance on each side needs 0.3 mm. There is no route
out of those balls on the surface.

**These holes must be filled and capped (IPC-4761 type VII).** An unfilled via in
a pad drains the solder paste into the barrel during reflow and starves the
joint. This is a real cost adder and it has to be quoted, not assumed.

⚠️ The same constraint sets the drill for the whole board: 0.25 mm vias on
**0.10 mm** drills, because 0.25 mm is the largest via that fits inside that
land. Everything else on the board would have been happy with 0.2 mm.

## Assembly

- **8 parts at 0.5 mm pitch or finer**, including two 50-ball BGAs.
  Reflow only; nothing here is hand-solderable, and the ground pours use solid
  pad connection rather than thermal relief for that reason.
- ⚠️ **The A121 is MSL 3 and takes at most two reflow passes.** Bake before use
  if the dry-pack has been open.
- **6 fiducials**, two per rigid island, diagonally opposite. ⚠️ Two per
  island and not three on the board: the flex tails let the islands move with
  respect to each other, so a machine that has located one has learned nothing
  about the next. Each has a 2 mm keepout on every layer — the footprint's own
  soldermask opening — so no copper shows through the window.
- No panelisation, no tooling holes, no test points.

## Ordering

| | |
|---|---|
| `smartbag-order.csv` | the named parts with manufacturer and Digi-Key numbers and **quantities for 5 boards plus 2 spares** — upload it to a distributor's BOM tool and the basket prices itself |
| `smartbag-passives.csv` | the 29 passive values as a SPECIFICATION rather than part numbers |
| `smartbag-bom.csv` | every line with its datasheet, for the record |

⛔ **The passives are deliberately not part numbers.** All 86 of them are 0402
commodity parts, and an assembly house fits those from its own reels; naming a
particular Murata reel raises the price and adds lead time for no electrical
reason. What has to be exact is the value, the tolerance, the dielectric and the
voltage, and those are in the file.

⚠️ **Two lines are not commodity and decide the schedule.** The Würth
760308103202 receiver coil showed **zero stock** at Digi-Key when this was
written — it is a catalogue part with a lead time and it is the only line here
that has one, so it is the line to order first. The Jauch cell is stocked but is
a lithium pouch: it ships under UN38.3 and some couriers will not carry it by
air at all.

⭐ **Prices in `hardware/bom.py` carry the date they were taken** and are there to
size an order, not to be believed later. A number in a repository does not go out
of stock on its own.

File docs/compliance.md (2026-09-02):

# SmartBag — what has to be certified, and what nobody has asked yet

⚠️ **Generated by `tools/compliance.py` from `hardware/bom.py` and
`thermal/budget.py`.** The equipment table is derived, so it cannot drift from
the design. The rest is a list of what to go and find out.

⛔ **Nothing here is legal advice and no clause number is quoted unless it is
certain.** A wrong standard reference in a compliance plan is worse than a blank
one: it gets believed, budgeted and scheduled, and the mistake surfaces at the
lab. Where the applicable standard depends on a judgement a test house makes,
this says so.

---

## 1 · What radiates

This is the table a test house asks for first, and it is the reason this file is
generated rather than written.

| | part | band | antenna | duty cycle | |
|---|---|---|---|---|---|
| **Bluetooth LE** | NRF54L15-QFAA-R | 2400–2483.5 MHz | chip antenna 2450AT43F0100E | advertising 1 ms/s; a connection during a sync | intentional radiator. The one everybody expects. |
| **60 GHz radar ×2** | A121-001-T&R | 57–64 GHz | antenna inside the package | ≈50 ms per event, ≈40 events a day | ⛔ THE HARD ONE. Two of them, and they are the reason this document exists. |
| **wireless power receiver** | BQ51013BRHLR | ≈100–205 kHz (WPC) | Ø48 mm coil, 760308103202 | only while on a pad | a receiver, not a transmitter — but it is part of the system a lab measures. |

Average power of the whole product, from `thermal/budget.py`: **0.15 mW**. The
duty cycles above are not incidental — they are the architecture. Nothing polls;
each stage is armed by the one before it.

## 2 · Europe

The product is radio equipment, so it falls under the **Radio Equipment
Directive (2014/53/EU)**. Under RED a manufacturer self-declares against
harmonised standards, and where no harmonised standard covers a case, a
**notified body** has to be involved.

| what | status |
|---|---|
| **2.4 GHz BLE** | ✅ well-trodden. A wideband data transmission module in this band is the most tested thing in consumer electronics, and the SoC vendor supplies test reports for its own radio. The *product* still has to be measured — the antenna is on this board, next to this ground plane, inside leather. |
| **60 GHz radar ×2** | ⛔ **the open question.** 57–64 GHz is licence-exempt in the EU for short-range devices, but which harmonised standard applies to a pulsed coherent radar in a consumer bag — and whether one applies at all — is a judgement for a test house. **Ask Acconeer first**: they sell the A121 into consumer products and will know what route their customers take, and whether any of it transfers. |
| **EMC** | applies. Immunity and emissions for a radio product. |
| **RF exposure** | applies. Two radars and a BLE radio against a body, in a bag carried against a hip. The powers are tiny; the assessment still has to exist. |
| **Electrical safety** | applies to the product as a whole, including the charging path. |
| **Battery** | the cell is already **UN 38.3** and **IEC 62133-2** certified by Jauch — that is on its datasheet. ⚠️ The finished product is a separate matter. |
| **RoHS / REACH** | applies. Every part in `hardware/bom.py` is a current catalogue part from a major distributor, so compliance data exists for all of them — but it has to be collected. |
| **WEEE** | applies. It is an electronic product with a built-in battery. |

## 3 · United States

| what | status |
|---|---|
| **2.4 GHz BLE** | standard FCC certification for an intentional radiator in the ISM band. |
| **60 GHz radar** | ⛔ **do not assume this is the same as Europe.** The rules for 57–64 GHz field-disturbance sensors in the US have their own history and their own limits, and they are not the same question as the European one. Ask a US test house directly, and ask Acconeer what their customers have done. **This may be the constraint that decides which markets ship first.** |
| **Battery shipping** | the finished bag contains a lithium cell: **UN 3481**, packed with equipment. |

## 4 · Wireless power

The receiver is a **BQ51013BRHLR** — a standard WPC 5 W receiver —
so any Qi pad speaks its language.

- ⚠️ **Using the Qi logo requires WPC membership and certification of the
  receiver.** Without it the product still works on Qi pads; it just cannot be
  called Qi in marketing or on the box.
- ⛔ **Foreign object detection is not certified, it is calibrated.** The
  transmitter compares the receiver's quality factor against a number the
  receiver declares, and that number has to be measured on the assembled bag.
  See `tools/calibrate.py`. A bag that declares a Q it does not have is a bag
  that charges with a coin on it.

## 5 · The order this actually happens in

⭐ **The 60 GHz question comes first and it is the only one that can kill the
design.** Everything else is cost and schedule; that one is a yes or a no, and
it wants answering before five prototypes are ordered rather than after.

1. **Ask Acconeer.** What route do their consumer customers take in the EU and
   the US, what test reports exist for the A121, and what transfers to a product
   that embeds it. One email, and it may answer most of section 2 and 3.
2. **Ask one test house for a scoping call.** They will want the table in
   section 1. That call is usually free and it produces the real standards list
   and a quote.
3. **Then order the prototypes** — the radiated measurements need a built board
   in a built bag, so the sample is the input to everything above anyway.
4. Battery paperwork, RoHS/REACH declarations, WEEE registration: these are
   administration and they follow the technical work.

## 6 · What this means for the schedule

⚠️ **Certification is measured in months and thousands, not days.** A full RED
route for a product with an unusual radiator is the longest single item between
here and a shipped box — longer than tooling the bag, longer than the PCB lead
times, longer than the firmware.

⛔ **And it is not in any plan in this repository.** That is the finding, and it
is why this file exists.

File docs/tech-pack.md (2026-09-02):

# SmartBag — tech pack

⚠️ **Generated by `tools/tech_pack.py` from `dimensions.py`, `hardware/bom.py`
and `cad/patterns.py`.** Do not edit this file; edit the design and run it again.
Everything below is derived, so a change to the bag reaches the person cutting
the hides instead of stopping at a CAD model.

⛔ **This is a first pattern, and that is how the trade works.** You cannot unroll
a 3D loft into a leather pattern and cut hides from it: a structured bag gets its
shape from the stiffener and the stitching as much as from the outline, leather
stretches on the bias and not across it, and every maker eases a curve
differently. Cut a toile in cheap material first. Two or three iterations before
the pattern is right is normal and none of them are a fault in this document.

---

## 1 · The bag

| | |
|---|---|
| silhouette | flared trapezoid, rigid body then a soft neck |
| base | **240 × 95 mm**, R20 vertical corners |
| at the top of the rigid body | **276 × 112 mm**, R22 |
| rigid height | **190 mm** |
| mouth | **245 mm** from the base — the last 55 mm is the soft neck |
| leather | structured, **3.5 mm** finished thickness |
| handles | rolled, attached at **z = 176 mm** — to the body, not the rim |

⚠️ **The handles do not go on the rim.** The neck pinches shut; a handle stitched
to the rim hangs in mid-air the moment the bag is closed.

## 2 · Cut list

Patterns: [`fab/patterns/smartbag-patterns.dxf`](../fab/patterns/smartbag-patterns.dxf),
1:1 in millimetres. **CUT** layer is the cutting line, **SEAM** the stitch line,
8 mm apart.

| panel | ×  | cut size | note |
|---|---|---|---|
| **front/back** | 2 | 248 × 207 mm | flat face, 200 -> 232 mm over 190.9 mm of slant |
| **gusset** | 2 | 153 × 207 mm | side face 55 mm plus a 20 mm corner each end; 118 -> 137 mm |
| **base** | 1 | 256 × 111 mm | 240 x 95 mm, R20 corners |
| **neck** | 1 | 754 × 71 mm | band 738 x 55 mm, joined into a loop at one end |
| **handle** | 2 | 291 × 56 mm | rolled over a 9 mm core; 195 mm of arc plus 40 mm tabs each end, attached at z = 176 mm |

**Leather, panels only: 2694 cm² (2.90 sq ft).** At a
realistic 65% yield once the belly, the brands and the scars are avoided, about
**4.46 sq ft a bag** — before lining, stiffener,
reinforcement patches and the closure, which roughly double it.

---

## 3 · What the electronics require — these are specifications

### 3.1 ⛔ The charging window: Ø56 mm at the centre of the base

A **Ø48 mm** wireless charging coil sits at the exact centre of the
insert's underside, facing down through the base of the bag. Inside a
**Ø56 mm** circle centred on the base:

- ⛔ **no metal of any kind.** No feet, no rivets, no plate, no magnetic snaps,
  no metallised or foil-backed lining, no metal-cored stiffener.
- ⛔ **base thickness 3.5 mm and not more.** This is the gap between the
  two coils and it is already most of the budget: a standard pad works to about
  5 mm coil to coil, and 3.5 mm of leather plus the pad's own surface uses
  it up. A doubled base or a thick reinforcement here stops the bag charging and
  will look like an electronics fault.
- ✅ leather, fabric lining, non-woven stiffener, thread and glue are all fine.
  The field does not care about them.

⚠️ **Metal feet are standard practice on a bag this size and they are the single
most likely thing to go wrong.** If the bag needs feet, they go **outside** the
Ø56 mm circle and they should be non-metallic.

### 3.2 ⛔ The closure magnet wakes the product

The insert has a magnetic sensor in its collar: it is what tells the bag it has
been opened, and the entire power budget depends on it. Everything else is
asleep until the closure opens.

- the closure **must** carry a small permanent magnet;
- it has to pass within about **5 mm** of the insert collar when the bag shuts;
- ⛔ **one magnet, and no other magnets anywhere in the bag.** A magnetic
  pocket snap near the collar holds the product permanently awake, which shows
  up as a battery that lasts days instead of months;
- ⛔ **no magnet within Ø56 mm of the base centre** — see 3.1.

### 3.3 The insert pocket

The insert is a rigid tray that drops into the bag and sits on its inner floor.

| | |
|---|---|
| footprint | **225 × 78 mm**, R16 |
| height | **179.6 mm** |
| bag inner at the base | 233 × 88 mm |
| clearance | **4.0 mm** each side, **5.0 mm** front and back |

⚠️ **That clearance is small and it is where a lining goes.** A padded or quilted
lining on the lower walls does not leave room for the insert. Line the walls flat.

### 3.4 The cell is a lithium pouch

LP523450JU+PCM+JST PHR-3 70MM — 950 mAh, in the insert, not in the bag. It
never comes out and there is no user-accessible battery door.

- ⛔ nothing in the construction may compress the base of the insert;
- ⚠️ the finished bag ships with a cell in it, which is a **UN 3481** shipment
  and needs the paperwork. The cell itself is already **UN 38.3** and
  **IEC 62133-2** certified by its maker — that is on its datasheet — but the
  finished product is a separate declaration.

---

## 4 · What is still open on the bag

Everything in section 3 is settled. None of the following is:

- ⛔ **no maker.** No pellettiere has seen this, no sample has been sewn, no
  quote exists.
- ⛔ **no closure chosen.** The neck has to pinch shut and carry a magnet;
  whether that is a zip, a magnetic flap or a drawstring is a design decision
  nobody has taken, and it changes the neck pattern.
- ⛔ **no lining or stiffener specified.** Which stiffener a structured bag uses
  decides how the panels are cut, so this comes before the pattern is final.
- ⛔ **no hardware.** Handle fixings, feet if any, closure hardware.
- ⚠️ **the pattern has never been cut.** See the note at the top: expect two or
  three iterations with the maker.

---

## 5 · How to read the rest of the repository

| you want | look at |
|---|---|
| the shape in 3D | `cad/bag_and_insert.py`, and `render/views/section.png` |
| what goes inside | `README.md`, "The circuit" |
| why the coil is where it is | `thermal/budget.py` — it moved the cell, not the coil |
| the numbers behind this file | `dimensions.py` |

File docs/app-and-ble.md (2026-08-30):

# The companion app, and the BLE contract it talks to

**This document is now implemented on both sides.** The device side is
[`firmware/sb_ble.c`](../firmware/sb_ble.c); the phone side is
[`app/`](../app/). What follows is still the specification — it is the reason
each field exists, which the code cannot tell you — and it is now also checked:
`firmware/gen_vectors.c` writes golden payloads and `app/test_protocol.mjs`
decodes those exact bytes, so the two halves cannot drift apart quietly.

It was written first because the repo was describing a device that had no way to
tell anyone what it knew. An insert that recognises its contents and cannot
report them is not half a product, it is no product — and the interface is the
part worth pinning down early, because it is where the two halves have to agree.

⚠️ Still not implemented, and listed at the end: pairing, bonding, encryption,
OTA, and anything to do with an account.

---

## What owns the identity: the insert, not the bag

This decides the whole data model, so it comes first.

The insert is **removable by design** — that is the entire reason it exists, so
the bag never has to be modified. Which means:

- **one insert = one BLE peripheral = one inventory.** The insert is the thing
  with a MAC address, a ledger and a battery. It is the unit.
- **the bag is not a thing the system knows about.** Move the insert from the
  black tote to the tan one and nothing changes electrically. The insert has no
  sensor that could tell it which bag it is sitting in, and it should not
  pretend otherwise.
- **several bags means several inserts.** If you own three, the app pairs three
  peripherals and shows three inventories. "Which bag am I carrying?" becomes
  "which insert is in range?", which is a question BLE can actually answer.

The app may of course let you *name* an insert ("work bag", "weekend") — but
that is a label the user assigns, not something the hardware discovers. Anything
else would be an invented fact, which is the failure mode this whole design
keeps trying to avoid.

### The one honest exception

If someone genuinely needs the insert to know which bag it is in, the answer is
the same escape hatch as for two identical objects: a passive tag **in the bag**.
The current board has no NFC reader, so this is not free — it is a hardware
change, and it is listed here as a possibility, not a plan.

---

## Two data, two update policies

The app must never render these the same way, because they do not have the same
truth value. (See the data model section of the main README for the reasoning.)

| datum | changes | staleness |
|---|---|---|
| **inventory** — what is inside | only on an event at the mouth | never goes stale on its own |
| **position map** — where each thing is | on every disturbance | perishable; carries a timestamp and a `stale` flag |

An inventory entry is a fact. A position is a measurement with an age. The UI
has to show the age, and has to be able to say *"I do not know precisely"* —
"lipstick, right compartment, measured 40 minutes ago" is a good answer;
"lipstick, under the pouch" when the map is three walks old is a lie with a
confident font.

---

## GATT service

One primary service. All multi-byte values little-endian, all lengths in bytes.

**Service** `SmartBag Inventory` — 128-bit UUID, vendor-assigned.

### `Inventory` — read, notify

The current contents. Notified on every change; a full read returns the whole
list.

```
uint8   version            protocol version, starts at 1
uint8   count              number of entries that follow
uint32  ledger_seq         increments on every mouth event, ever
{ repeated `count` times:
  uint16  object_id        stable id assigned at enrollment
  uint8   class            enum: wallet, phone, keys, pouch, cosmetic, ...
  uint8   flags            bit0 confirmed by camera · bit1 present by mass only
  uint32  since            seconds since it entered (device uptime clock)
}
```

`ledger_seq` lets the app detect that it missed events while out of range and
ask for a resync, without the device having to buffer notifications.

### `PositionMap` — read, notify

Where things are, and how much to trust it.

```
uint8   version
uint8   count
uint8   staleness          0 = just measured, 255 = badly shaken since
uint32  measured_ago       seconds since the last full measurement
{ repeated `count` times:
  uint16  object_id
  int16   x, y             millimetres, insert coordinates
  uint8   compartment      0 left · 1 middle · 2 right · 255 unknown
  uint8   confidence       0..255 from the assignment cost
}
```

⚠️ **`compartment` is not derived from `x`.** When confidence is low the device
reports the compartment it is still sure of and sets `x, y` to a sentinel. The
app must render the compartment, not invent a dot on a map. Two fields exist
precisely so the device can answer at the resolution it actually has.

### `Event` — notify only

The wake-up chain, as it happens. Small and frequent; this is what makes the app
feel live rather than polled.

```
uint8   type               1 closure opened · 2 closure closed · 3 object in
                           · 4 object out · 5 remap done · 6 low battery
uint16  object_id          0 if not applicable
uint32  timestamp
```

### `Enrollment` — write, indicate

The registration flow (see the README: recognition is closed-set, so every
object has to be shown once).

```
write:   uint8 command   1 begin · 2 commit · 3 abort · 4 forget
         uint16 object_id     (0 on begin: the device allocates one)
         uint8  class
         utf8   label[..]     user-visible name
indicate: uint8 status   1 ready, show the object
                         2 captured, N samples so far
                         3 committed
                         4 failed: too dark / too fast / too similar to <id>
```

⚠️ Status 4 with `too similar to <id>` is the one that matters. If a new object
is not separable from one already enrolled, the device must **say so at
enrollment time**, not silently accept it and then confuse the two forever.

### `DeviceInfo` — read

```
uint8   version
uint8   battery_pct
uint16  firmware            major << 8 | minor
uint32  uptime              seconds
uint8   taxel_faults        taxels failing self-test, 0..96
uint8   state               the wake-up chain state, for diagnostics
uint16  energy_uah          charge spent since boot
```

### ⛔ The size limit that decides the transport

A full inventory is `6 + 24 × 8` = **198 bytes**. The default ATT MTU is 23,
which leaves **20**, and BLE does **not** fragment notifications — it delivers
the first 20 bytes and reports success. Those 20 bytes are a structurally valid
inventory containing one object.

So: either the phone negotiates an MTU of at least 201, or the app must **read**
`Inventory` rather than rely on the notification. `sb_ble_fits()` on the device
and `fitsNotification()` in the app both exist to make this a loud failure
instead of a quiet one.

⭐ `Event` is 7 bytes on purpose. The live path has to work on a link that
negotiated nothing.

---

## What the app has to do that is not obvious

- **Show age, everywhere.** Any position older than a few minutes gets rendered
  as an approximation. This is the single most important UI decision in the
  product.
- **Degrade to compartments.** The map view must have a legible "somewhere in
  the right compartment" state. If the design only works when coordinates are
  exact, it will look broken in normal use.
- **Handle several inserts without pretending they are one bag.** A list of
  inserts, each with its own inventory. No merged "everything I own" view that
  implies knowledge nobody has.
- **Own the enrollment flow.** It is the setup cost of the whole product and the
  place where it will be abandoned. Ten objects at ten seconds each is the
  budget worth designing against.
- **Survive being out of range.** `ledger_seq` in, resync out. The bag keeps
  working when the phone is not there; that is the point of putting the
  intelligence in the insert.

## What is deliberately not specified here

Pairing and bonding, the encryption of the characteristics, OTA updates, and
anything to do with a cloud account. All of them are real work, none of them are
interesting design decisions at this stage, and guessing at them would add
volume without adding information.

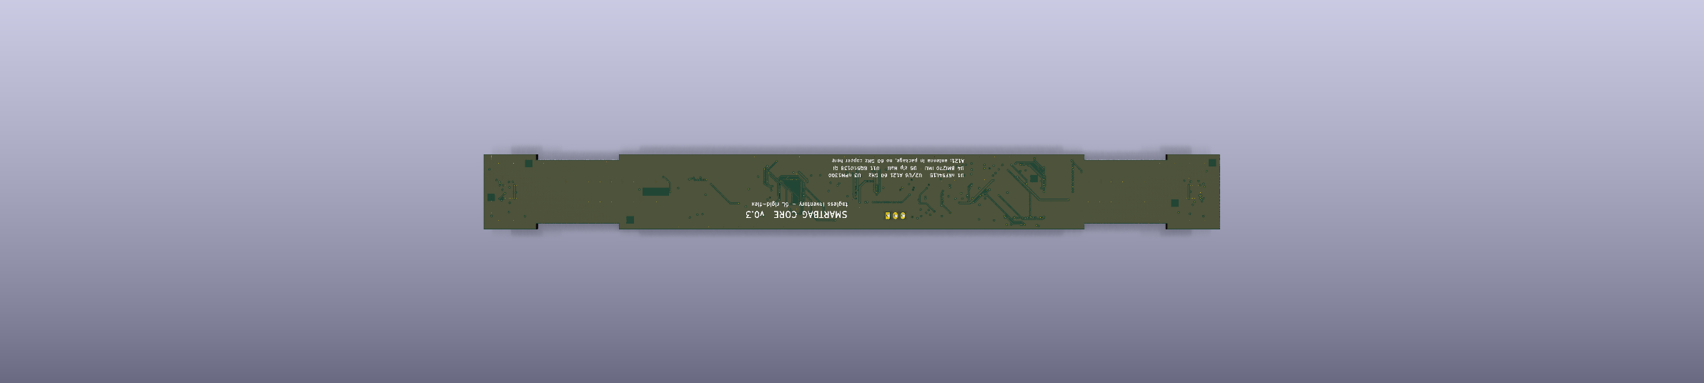
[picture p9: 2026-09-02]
hardware/render/pcb_bottom.png

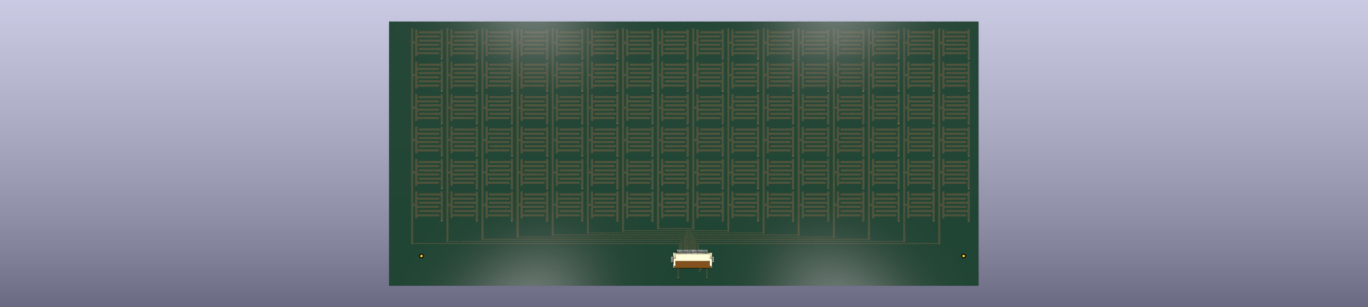
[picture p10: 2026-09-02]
hardware/render/pcb_taxels.png

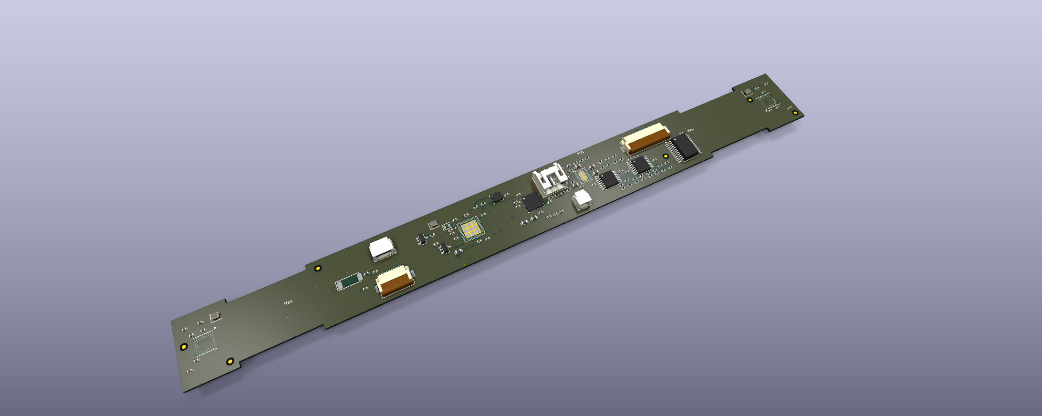
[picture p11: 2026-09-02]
hardware/render/pcb_iso_b.png

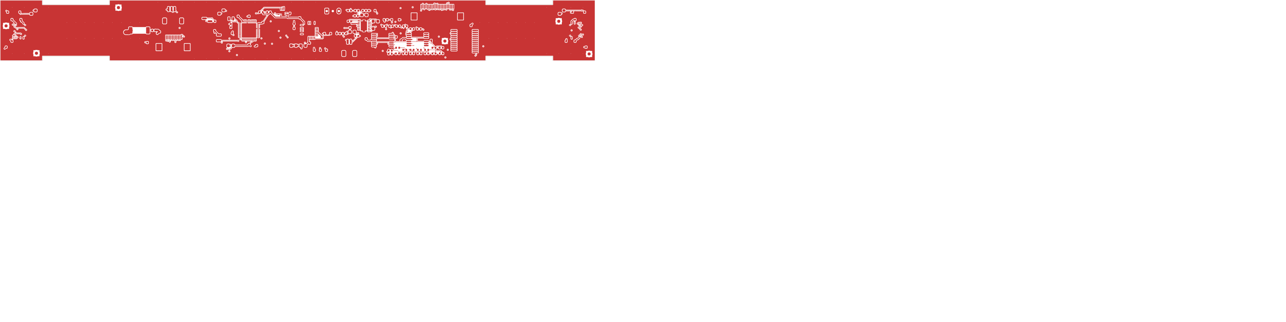
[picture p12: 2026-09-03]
media/evidence/artwork-top-copper.png

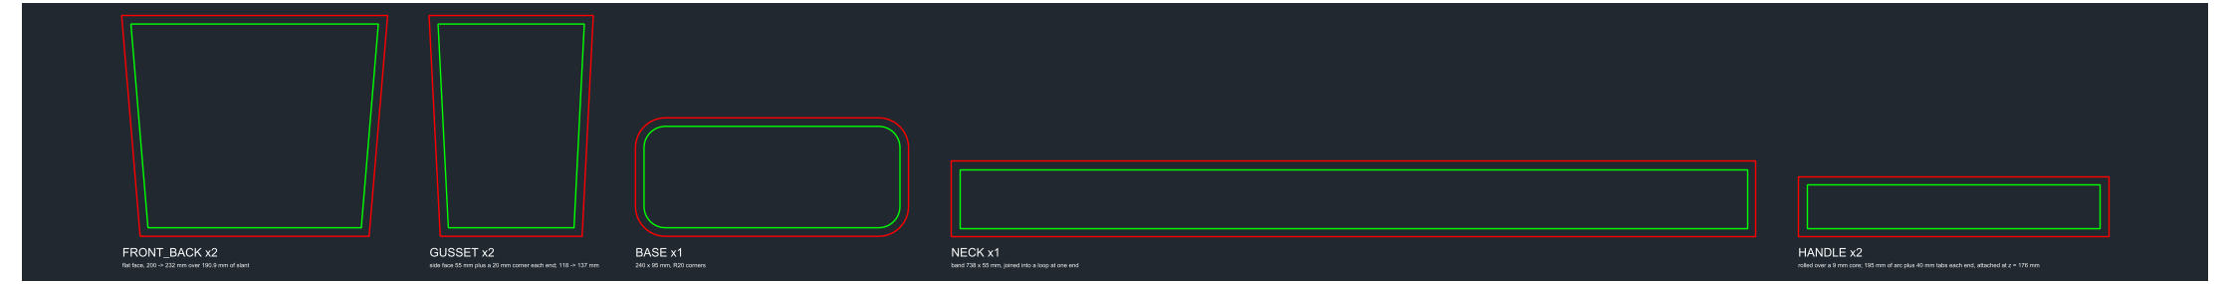
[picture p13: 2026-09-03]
media/evidence/pattern-1to1.png

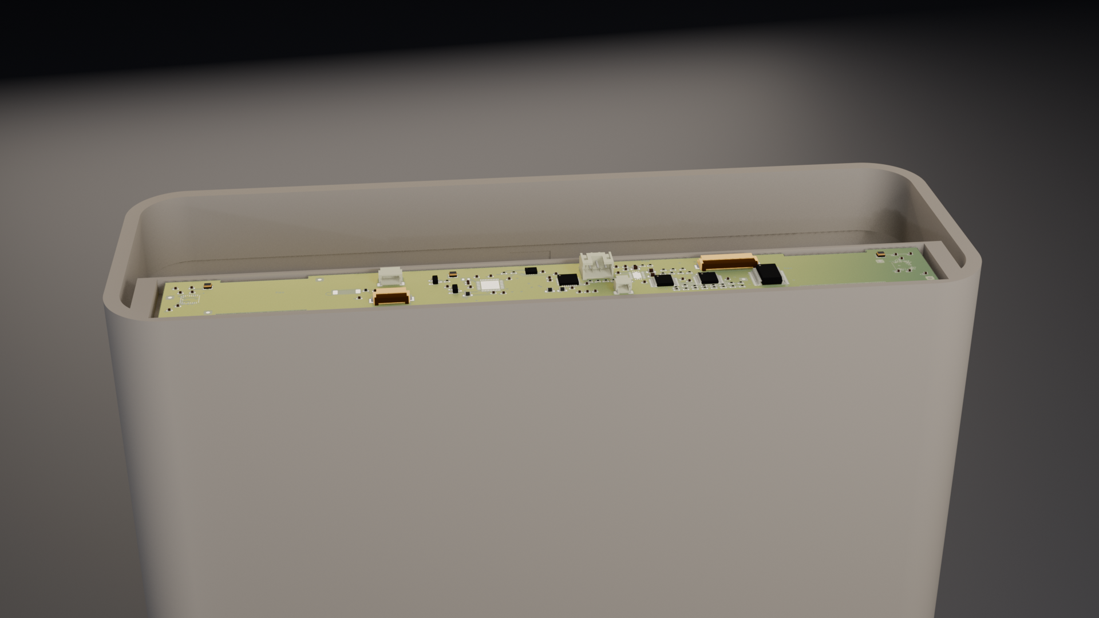
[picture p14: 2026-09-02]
render/views/collar.png

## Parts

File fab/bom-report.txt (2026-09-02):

BOM vs footprints — measured, not asserted

  ok U1   NRF54L15-QFAA-R        QFN48      datasheet  48 pins / 6.0x6.0 mm   footprint  49 pins /   7.5x7.2 mm
  ok U2   A121-001-T&R           fcCSP50    datasheet  50 pins / 5.2x5.5 mm   footprint  50 pins /   5.7x6.0 mm
  ok U6   A121-001-T&R           fcCSP50    datasheet  50 pins / 5.2x5.5 mm   footprint  50 pins /   5.7x6.0 mm
  ok U3   NPM1300-QEAA-R7        QFN32      datasheet  32 pins / 5.0x5.0 mm   footprint  33 pins /   6.6x6.3 mm
  ok U4   BMI270                 LGA-14     datasheet  14 pins / 2.5x3.0 mm   footprint  14 pins /   3.8x3.3 mm
  ok U5   DRV5032FBDBZR          SOT-23-3   datasheet   3 pins / 2.92x2.37 mm   footprint   3 pins /   3.9x3.4 mm
  ok U11  BQ51013BRHLR           VQFN-20 (RHL) datasheet  20 pins / 4.5x3.5 mm   footprint  21 pins /   4.4x5.4 mm
  ok Q1   SI2302CDS-T1-GE3       SOT-23     datasheet   3 pins / 2.9x1.3 mm   footprint   3 pins /   3.9x3.4 mm   [pdf not archived]
  ok U7   CD74HC4067SM96         SSOP-24    datasheet  24 pins / 5.3x8.2 mm   footprint  24 pins /   9.4x8.9 mm
  ok U8   TLV9064IPWR            TSSOP-14   datasheet  14 pins / 4.4x5.0 mm   footprint  14 pins /   7.7x5.6 mm   [pdf not archived]
  ok U9   TLV9064IPWR            TSSOP-14   datasheet  14 pins / 4.4x5.0 mm   footprint  14 pins /   7.7x5.6 mm   [pdf not archived]
  ok Y1   ABM8-32.000MHZ-B2-T    SMD-2016-4 datasheet   4 pins / 2.0x1.6 mm   footprint   4 pins /   3.0x2.6 mm   [pdf not archived]
  ok Y4   ABS07-32.768KHZ-9-T    SMD-2012-2 datasheet   2 pins / 2.0x1.2 mm   footprint   2 pins /   3.0x2.2 mm   [pdf not archived]
  ok Y2   ABM8-24.000MHZ-B2-T    SMD-2016-4 datasheet   4 pins / 2.0x1.6 mm   footprint   4 pins /   3.0x2.6 mm   [pdf not archived]
  ok Y3   ABM8-24.000MHZ-B2-T    SMD-2016-4 datasheet   4 pins / 2.0x1.6 mm   footprint   4 pins /   3.0x2.6 mm   [pdf not archived]
  ok J1   FH12-12S-0.5SH(55)     FH12-12S   datasheet  12 pins / 10.4x4.3 mm   footprint  12 pins /  12.1x7.9 mm   [pdf not archived]
  ok J4   FH12-24S-0.5SH(55)     FH12-24S   datasheet  24 pins / 16.4x4.3 mm   footprint  24 pins /  18.1x7.9 mm   [pdf not archived]
  ok J2   S3B-PH-K-S(LF)(SN)     JST-PH-03  datasheet   3 pins / 7.9x4.5 mm   footprint   3 pins /   8.9x8.6 mm   [pdf not archived]
  ok J3   SM02B-SRSS-TB(LF)(SN)  JST-SH-02  datasheet   2 pins / 4.25x2.9 mm   footprint   2 pins /   5.8x6.6 mm   [pdf not archived]
  ok J5   SM04B-SRSS-TB(LF)(SN)  JST-SH-04  datasheet   4 pins / 6.25x2.9 mm   footprint   4 pins /   7.8x6.6 mm   [pdf not archived]
  ok AE1  2450AT43F0100E         SMD chip   datasheet   2 pins / 6.0x2.0 mm   footprint   2 pins /   7.4x2.7 mm   [pdf not archived]
  ok U10  VL53L1CXV0FY/1         LGA-12     datasheet  12 pins / 4.9x2.5 mm   footprint  12 pins /   5.5x3.1 mm
  ok J11  SM06B-SRSS-TB(LF)(SN)  JST-SH-06  datasheet   6 pins / 8.25x2.9 mm   footprint   6 pins /   9.8x6.6 mm   [pdf not archived]

  availability, as of 2026-08-30 — a snapshot, not a promise:
     U1   LCSC C42458750, $3.99/1, $2.72/100, out of stock 2026-08-30
     U2   distributor stock not verified
     U6   distributor stock not verified
     U3   LCSC C7501206, $1.75/1, $1.66/100, out of stock 2026-08-30
     U4   commodity, widely stocked
     U5   commodity, widely stocked
     U11  commodity
     Q1   commodity
     U7   commodity
     U8   commodity
     U9   commodity
     Y1   commodity
     Y4   commodity
     Y2   commodity
     Y3   commodity
     J1   commodity
     J4   commodity
     J2   commodity
     J3   commodity
     J5   commodity
     AE1  commodity
     U10  commodity
     J11  commodity

  86 passives in 29 distinct values, derived from the netlist:
     0402           0.3p C0G               x1   C11
     0402           0R                     x1   R12
     0402           1.2k 1%                x1   R11
     0402           1.5p NP0               x1   C6
     0402           100R 1%                x1   R21
     0402           100k 1%                x17  R13 R60 R61 R62 R63 R64 +11 more
     0402           100n X7R               x11  C4 C50 C51 C52 C61 C62 +5 more
     0402           10k 1%                 x4   R2 R22 R3 R5
     0402           10n X7R                x2   C82 C83
     0603           10u X5R 25V            x1   C88
     0402           10u X5R 6.3V           x3   C40 C41 C42
     0402           10u X6S 6.3V           x1   C3
     0402           1M 1%                  x1   R4
     0402           1k 1%                  x1   R6
     0402           1u X5R                 x13  C20 C21 C22 C23 C30 C31 +7 more
     0402           2.2n X7R               x1   C5
     0603           2.2u 1.2A              x2   L3 L4
     0402           2.2u X6T 2.5V          x2   C1 C2
     0402           2.7n                   x1   L2
     0402           220R 1%                x1   R20
     0603           220n C0G (Cs)          x1   C80
     0402           2n2 C0G (Cd)           x1   C81
     0402           4.7k 1%                x2   R7 R8
     0603           4.7u 120mA             x1   L1
     0603           470n X7R 25V           x2   C84 C85
     0402           47n X7R                x2   C86 C87
     0402           6.8k 1%                x1   R10
     0402           8.2k 1%                x6   R40 R41 R42 R43 R44 R45
     0402           8p NP0                 x4   C24 C25 C34 C35
⚠️ 2 things the design needs and the board has not got:

   - a tuned antenna match
     L2/C6/C11 are the chip vendor's reference values. A chip antenna matches against the ground plane around it, and this ground plane is not theirs. ⚠️ This one cannot be closed on paper: it wants a network analyser and one of the boards this BOM orders.

   - real sensor data
     every threshold in the firmware is either a datasheet figure or arithmetic over one, and ml/classify.py's accuracy is measured on rendered primitives. Whether a wallet can be told from a passport through four IR LEDs at 96x96 is a question the built thing answers and nothing else does.

wrote hardware/bom.csv

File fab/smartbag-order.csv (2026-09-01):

Manufacturer Part Number | Digi-Key Part Number | Quantity | Customer Reference | Description
NRF54L15-QFAA-R | 1490-NRF54L15-QFAA-R-ND | 7 | U1 | Cortex-M33 wireless SoC, Bluetooth LE, 1.5 MB NVM, 256 kB RAM
A121-001-T&R | 1891-A121-001-T&RCT-ND | 7 | U2 | 60 GHz pulsed coherent radar, antenna in package, SPI
A121-001-T&R | 1891-A121-001-T&RCT-ND | 7 | U6 | 60 GHz radar, second viewpoint at the other end of the insert
NPM1300-QEAA-R7 | 1490-NPM1300-QEAA-R7CT-ND | 7 | U3 | PMIC: 800 mA charger with NTC/JEITA, fuel gauge, 2 bucks, 2 LDOs
BQ51013BRHLR | 296-38885-1-ND | 7 | U11 | 5 W Qi receiver: synchronous rectifier, WPC control, 5 V out
760308103202 | 732-5257-ND | 7 | L_COIL | WE-WPCC Qi receiver coil, 12 µH, 48 mm, litz wire with shield
LP523450JU+PCM+JST PHR-3 70MM | 1908-LP523450JU+PCM+JSTPHR-370MM-ND | 7 | BT1 | Li-Po 3.7 V 950 mAh pouch, PCM + 10k NTC, JST PHR-3 harness
BMI270 | 828-1091-1-ND | 7 | U4 | 6-axis IMU, 14-pin LGA, I2C
DRV5032FBDBZR | 296-47323-1-ND | 7 | U5 | Omnipolar digital Hall latch, 1.65-5.5 V, ~540 nA average
CD74HC4067SM96 |  | 7 | U7 | 16:1 analog multiplexer, the FSR column selector
TLV9064IPWR | 296-50014-1-ND | 7 | U8 | Quad RRIO op-amp, 1.8-5.5 V — four of the six taxel amplifiers
TLV9064IPWR | 296-50014-1-ND | 7 | U9 | Quad RRIO op-amp — the remaining two amplifiers
ABM8-32.000MHZ-B2-T |  | 7 | Y1 | 32 MHz crystal, Cl = 8 pF — the SoC's HFXO
ABM8-24.000MHZ-B2-T |  | 7 | Y2 | 24 MHz crystal for the first radar
ABM8-24.000MHZ-B2-T |  | 7 | Y3 | 24 MHz crystal for the second radar
FH12-12S-0.5SH(55) |  | 12 | J1 | FFC connector, 12 way, 0.5 mm — the optics flex
SI2302CDS-T1-GE3 | SI2302CDS-T1-GE3CT-ND | 7 | Q1 | Logic-level N-channel MOSFET — the illuminator switch
ABS07-32.768KHZ-9-T | 535-9544-1-ND | 7 | Y4 | 32.768 kHz crystal, Cl = 9 pF — the low-power timebase
FH12-24S-0.5SH(55) |  | 7 | J4 | FFC connector, 24 way — the taxel matrix
S3B-PH-K-S(LF)(SN) | 455-1720-ND | 7 | J2 | PH series 3-pin 2.0 mm side-entry header — the cell
SM02B-SRSS-TB(LF)(SN) | 455-SM02B-SRSS-TBCT-ND | 7 | J3 | SH series 2-pin header — the Qi receiver coil
SM04B-SRSS-TB(LF)(SN) | 455-SM04B-SRSS-TBCT-ND | 7 | J5 | SH series 4-pin header — SWD
2450AT43F0100E | 712-2450AT43F0100001ECT-ND | 7 | AE1 | 2.4 GHz ceramic chip antenna
VL53L1CXV0FY/1 | 497-17764-1-ND | 7 | U10 | Time-of-flight ranging sensor, 940 nm, I2C, LGA-12
VSMY1850X01 | VSMY1850X01CT-ND | 7 | D1..D4 | 850 nm infrared emitter, 0805, Vf 1.65 V at 100 mA
SM06B-SRSS-TB(LF)(SN) |  | 12 | J11 | SH series 6-pin 1.0 mm header — the camera module
B0435 (Arducam Mega 3MP NoIR) |  | 7 | CAM | 3 MP SPI camera module, M12 lens, no IR-cut filter

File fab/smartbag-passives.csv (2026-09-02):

Value | Package | Quantity per board | Total | References
0.3p C0G | 0402 | 1 | 7 | C11
0R | 0402 | 1 | 7 | R12
1.2k 1% | 0402 | 1 | 7 | R11
1.5p NP0 | 0402 | 1 | 7 | C6
100R 1% | 0402 | 1 | 7 | R21
100k 1% | 0402 | 17 | 87 | R13 R60 R61 R62 R63 R64 R65 R66 R67 R68 R69 R70 R71 R72 R73 R74 R75
100n X7R | 0402 | 11 | 57 | C4 C50 C51 C52 C61 C62 C63 C64 C7 C8 C9
10k 1% | 0402 | 4 | 22 | R2 R22 R3 R5
10n X7R | 0402 | 2 | 12 | C82 C83
10u X5R 25V | 0603 | 1 | 7 | C88
10u X5R 6.3V | 0402 | 3 | 17 | C40 C41 C42
10u X6S 6.3V | 0402 | 1 | 7 | C3
1M 1% | 0402 | 1 | 7 | R4
1k 1% | 0402 | 1 | 7 | R6
1u X5R | 0402 | 13 | 67 | C20 C21 C22 C23 C30 C31 C32 C33 C43 C44 C45 C46 C60
2.2n X7R | 0402 | 1 | 7 | C5
2.2u 1.2A | 0603 | 2 | 12 | L3 L4
2.2u X6T 2.5V | 0402 | 2 | 12 | C1 C2
2.7n | 0402 | 1 | 7 | L2
220R 1% | 0402 | 1 | 7 | R20
220n C0G (Cs) | 0603 | 1 | 7 | C80
2n2 C0G (Cd) | 0402 | 1 | 7 | C81
4.7k 1% | 0402 | 2 | 12 | R7 R8
4.7u 120mA | 0603 | 1 | 7 | L1
470n X7R 25V | 0603 | 2 | 12 | C84 C85
47n X7R | 0402 | 2 | 12 | C86 C87
6.8k 1% | 0402 | 1 | 7 | R10
8.2k 1% | 0402 | 6 | 32 | R40 R41 R42 R43 R44 R45
8p NP0 | 0402 | 4 | 22 | C24 C25 C34 C35

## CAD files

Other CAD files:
fab/patterns/smartbag-patterns.dxf

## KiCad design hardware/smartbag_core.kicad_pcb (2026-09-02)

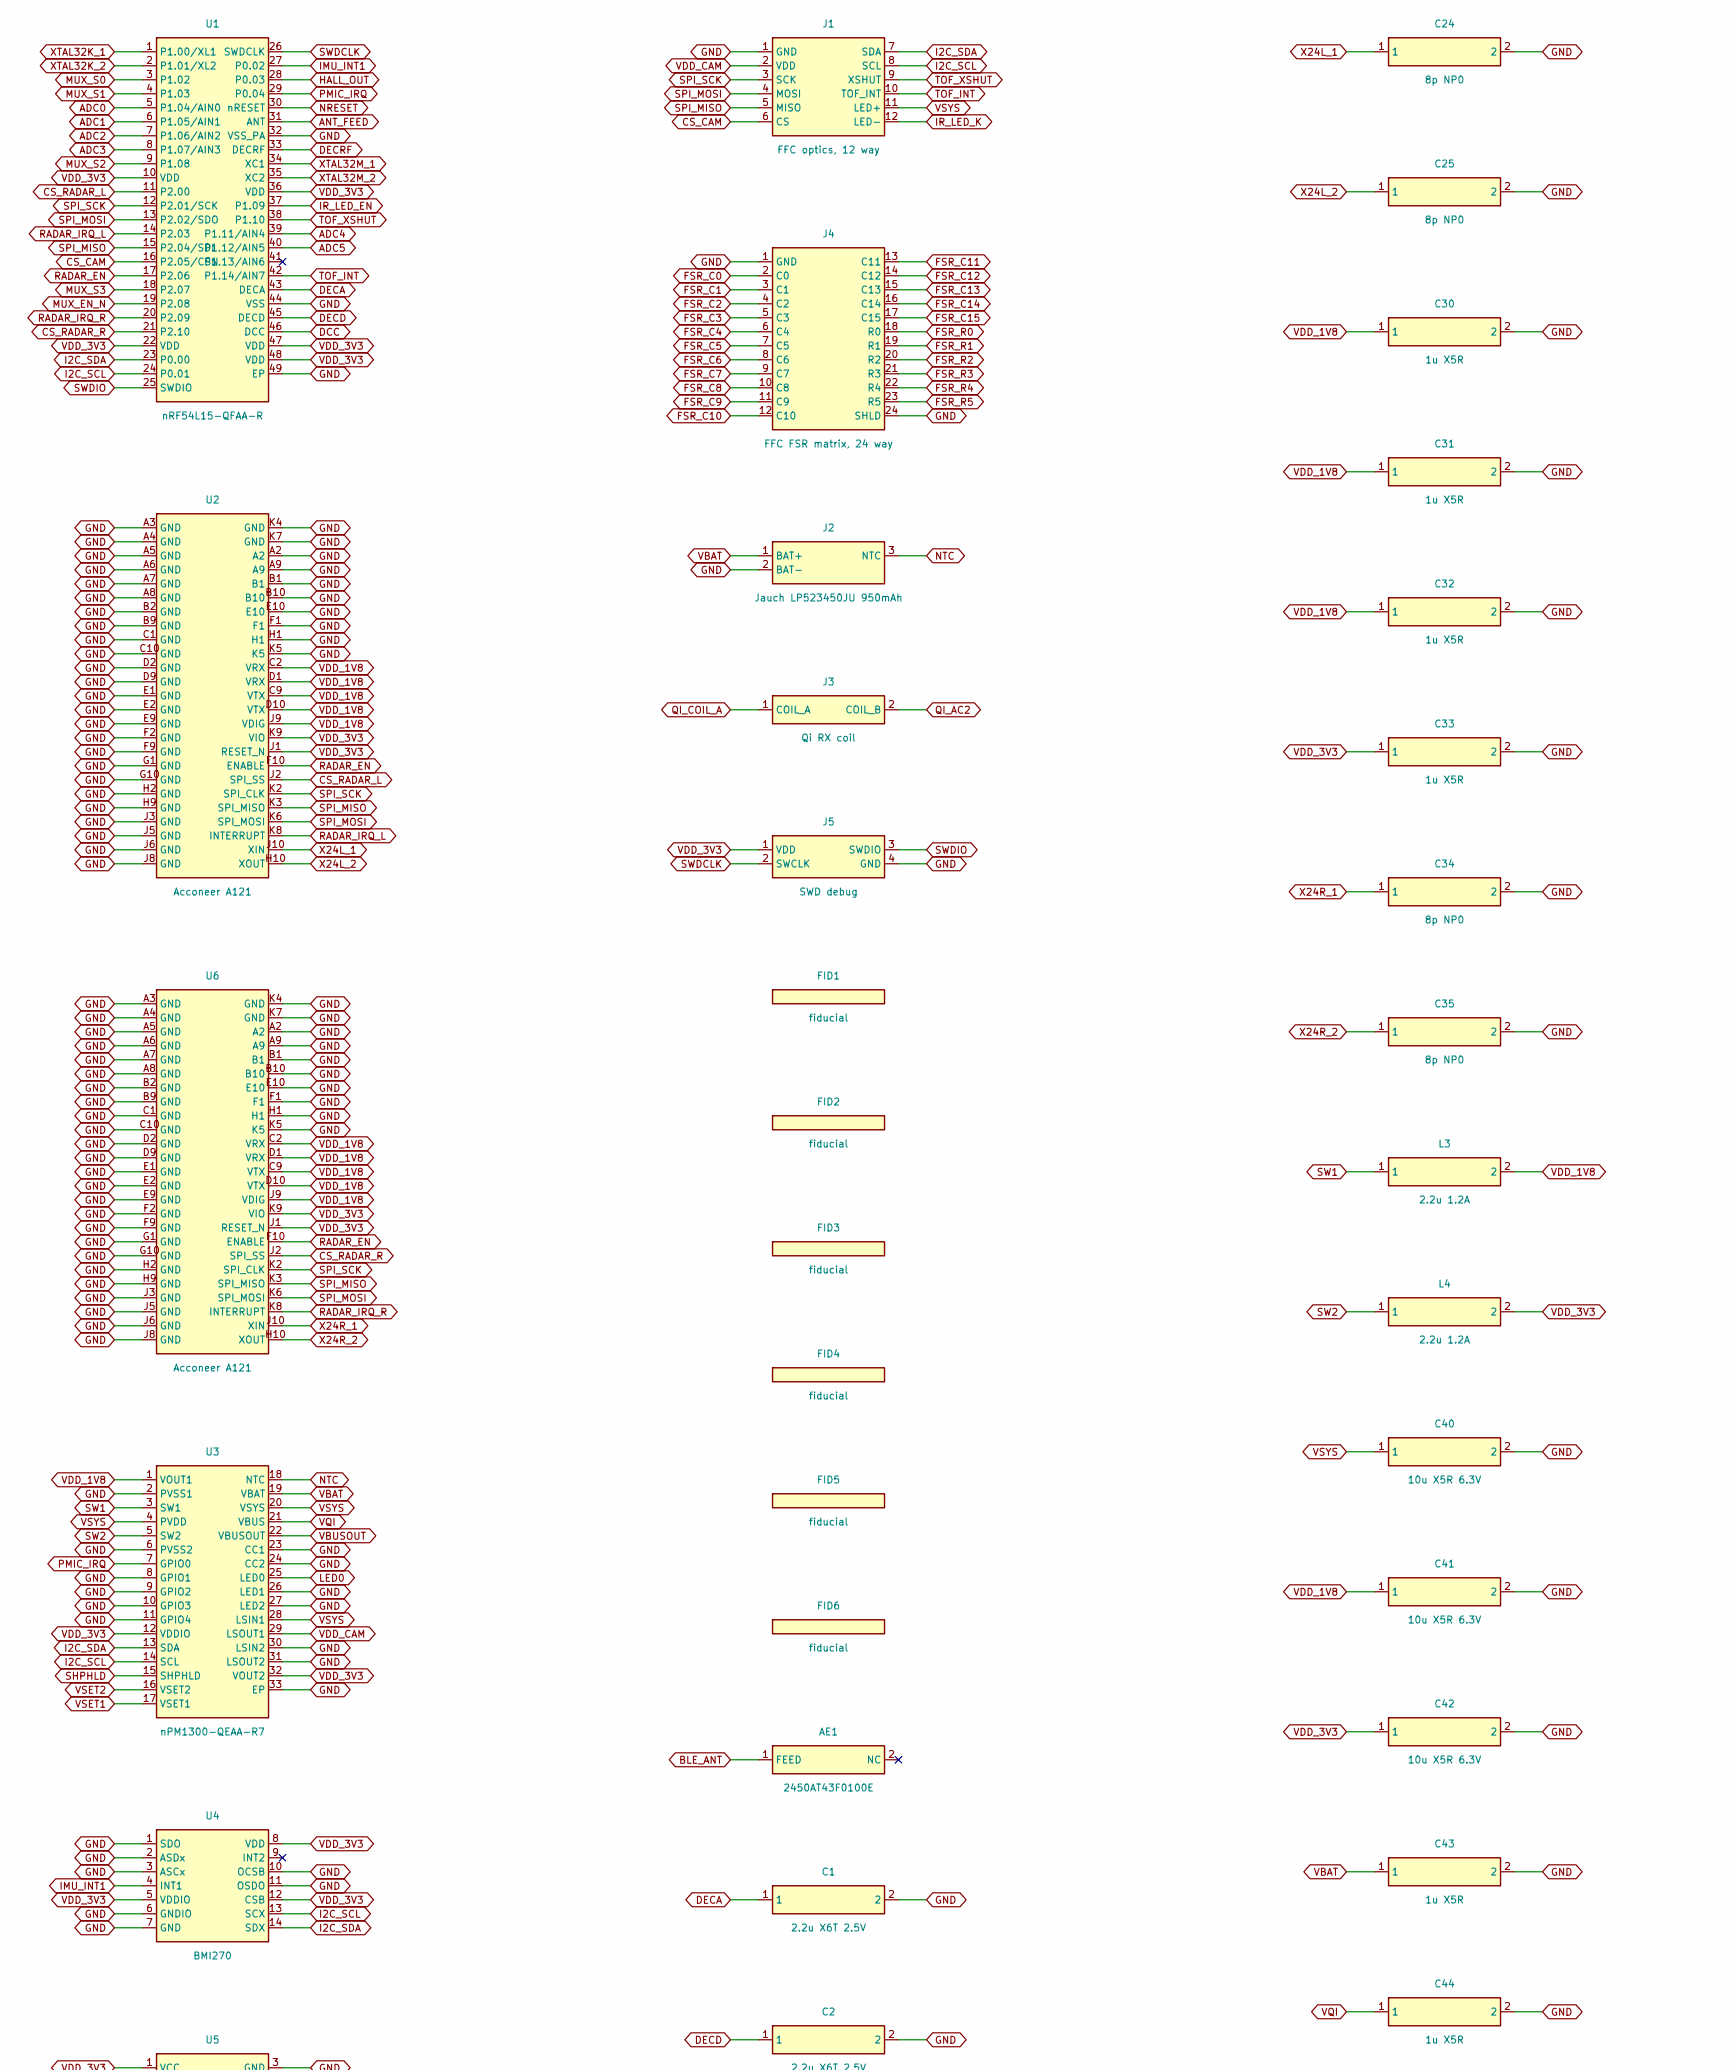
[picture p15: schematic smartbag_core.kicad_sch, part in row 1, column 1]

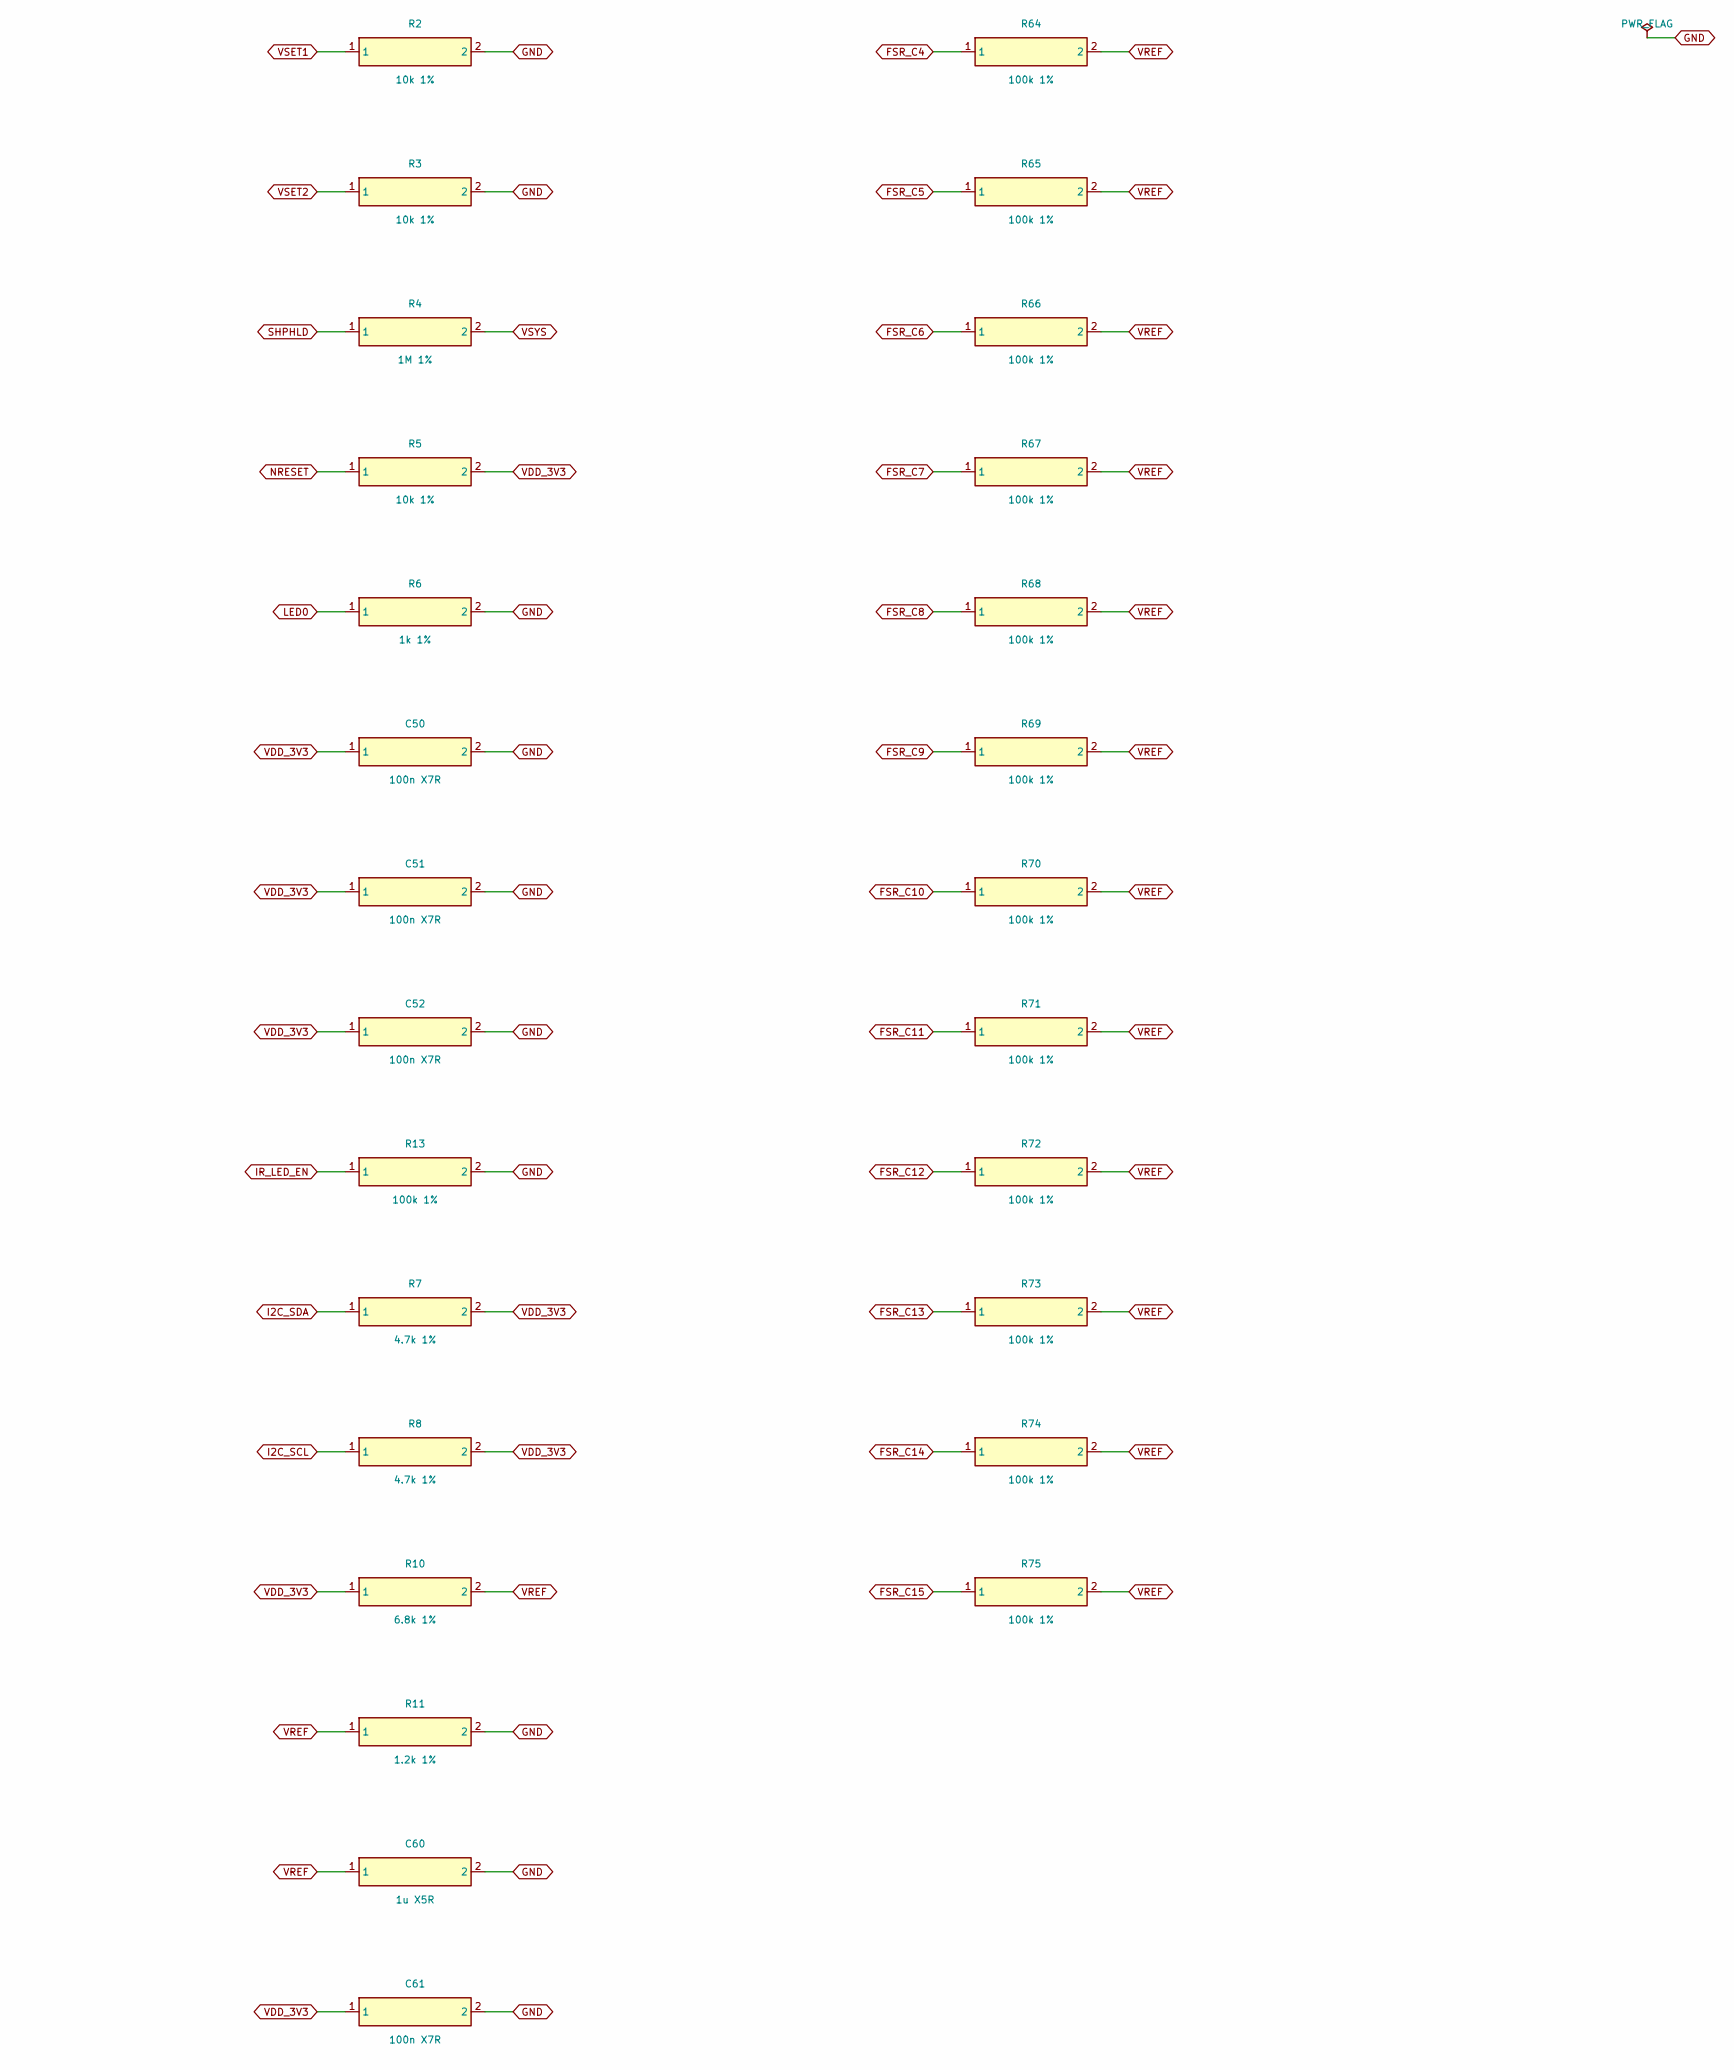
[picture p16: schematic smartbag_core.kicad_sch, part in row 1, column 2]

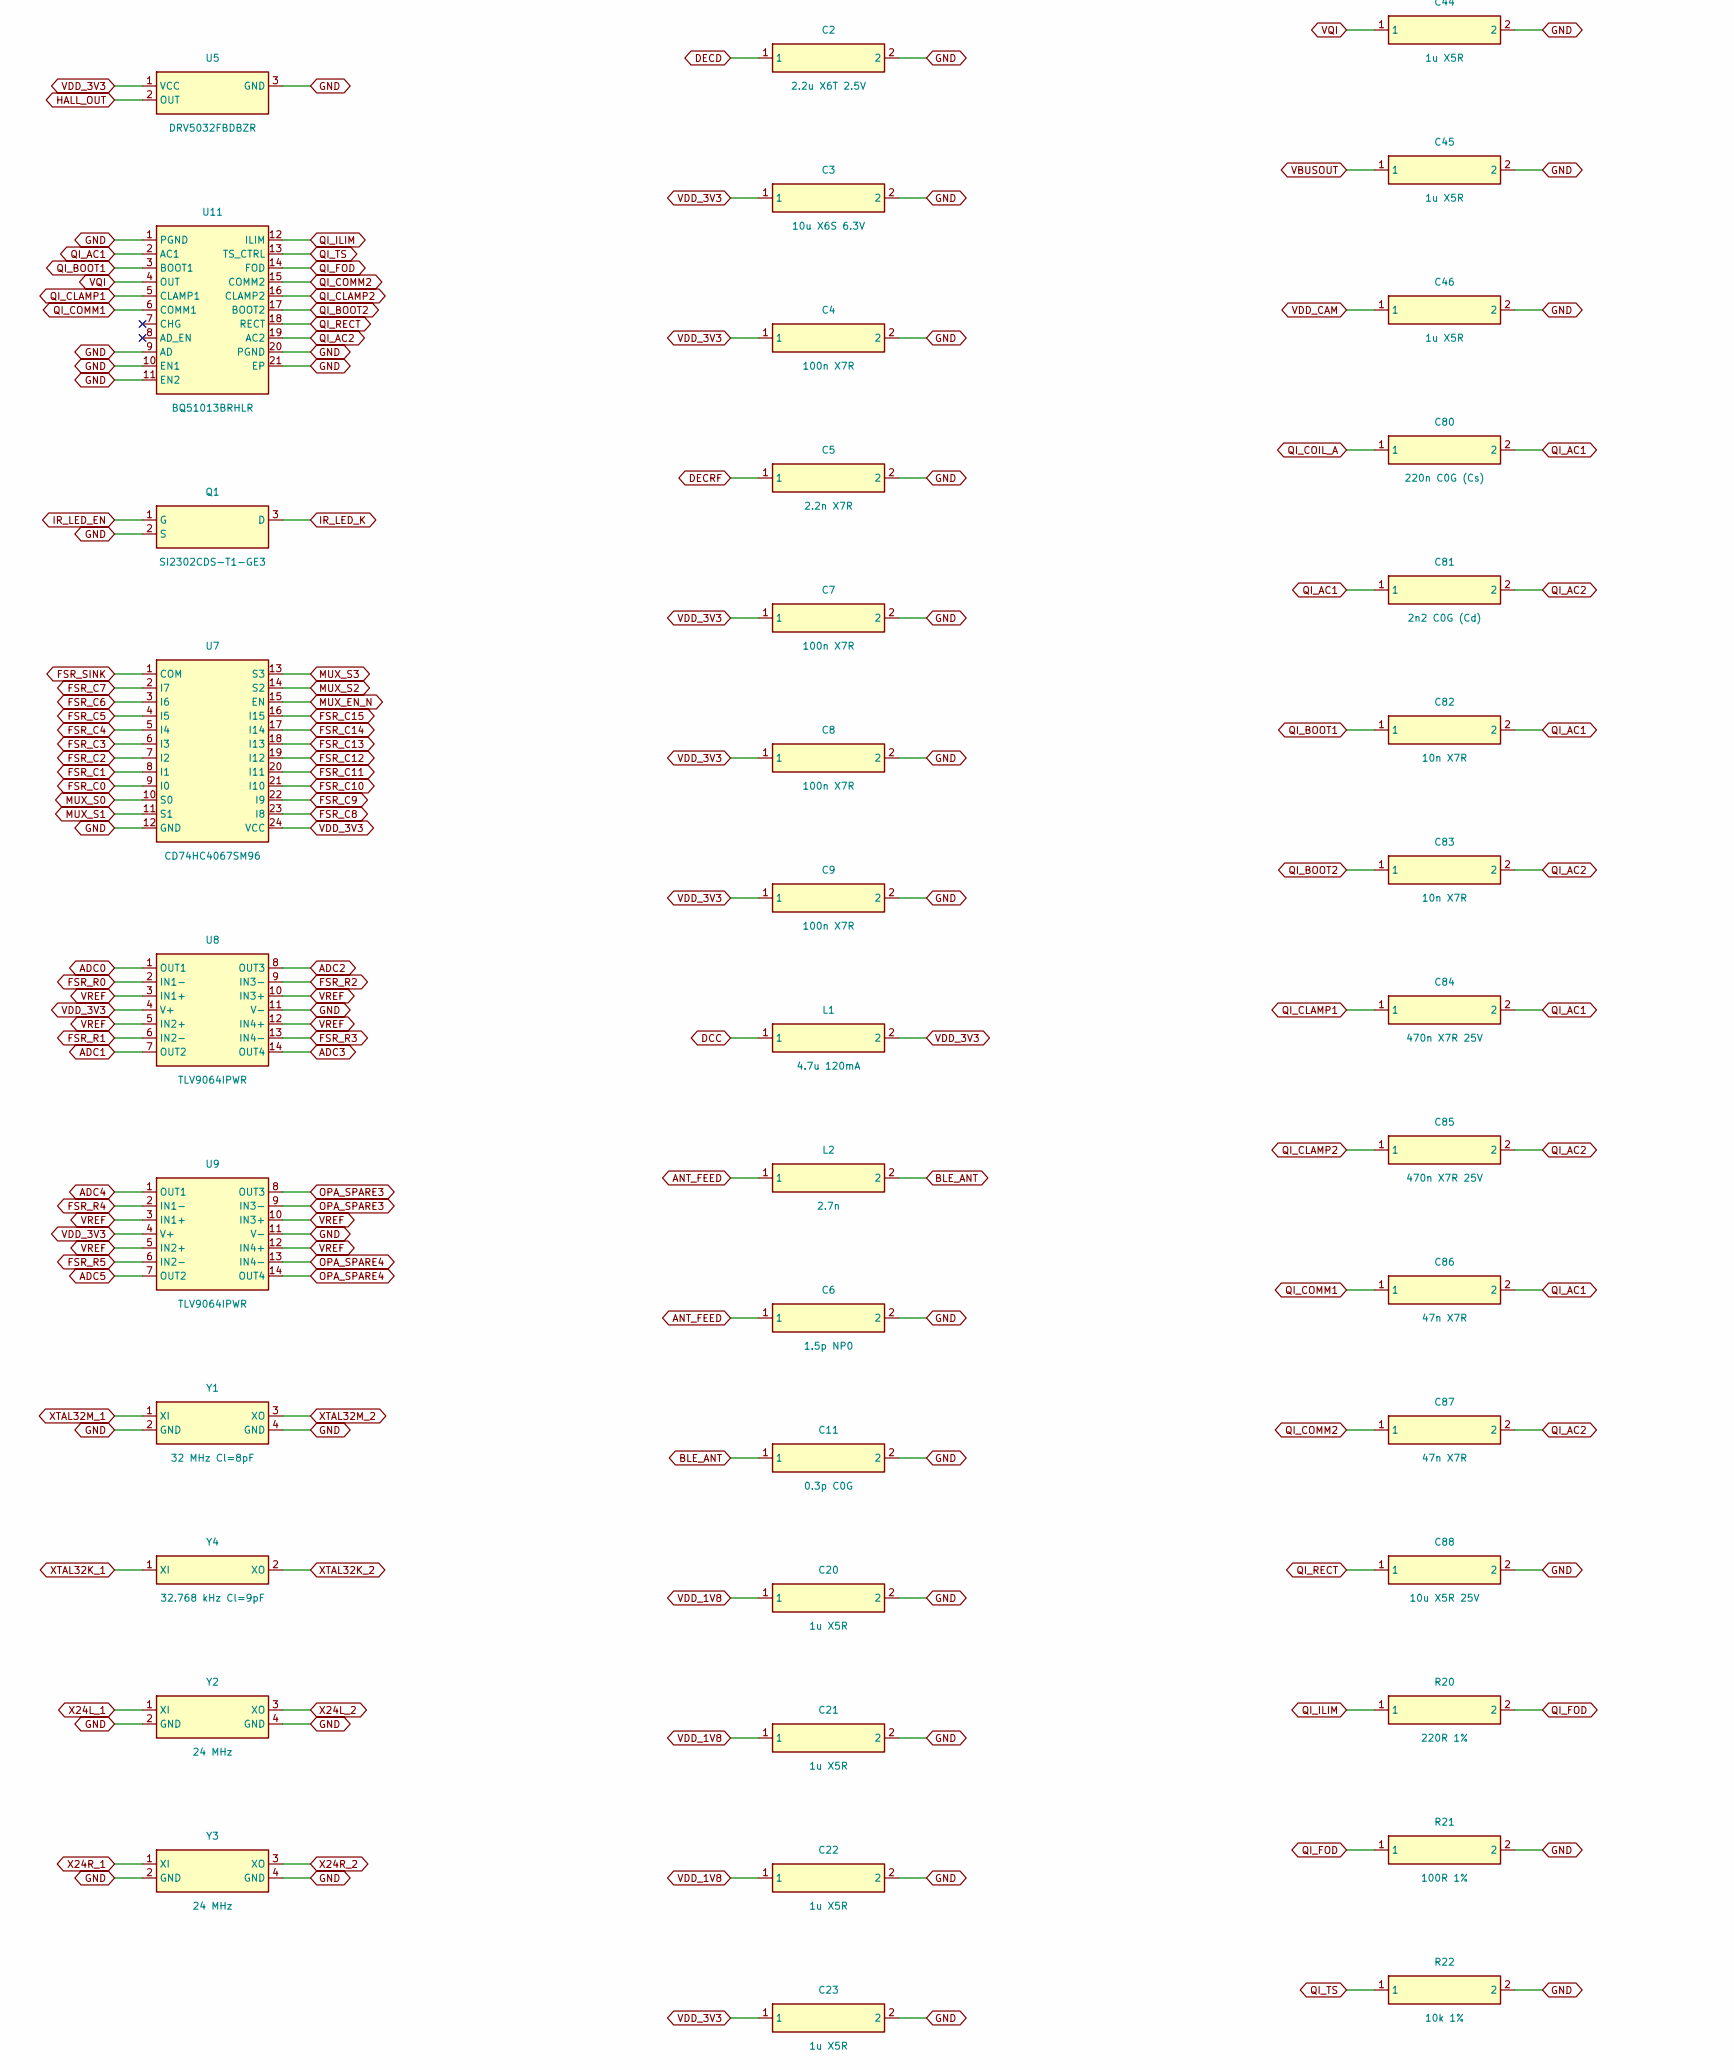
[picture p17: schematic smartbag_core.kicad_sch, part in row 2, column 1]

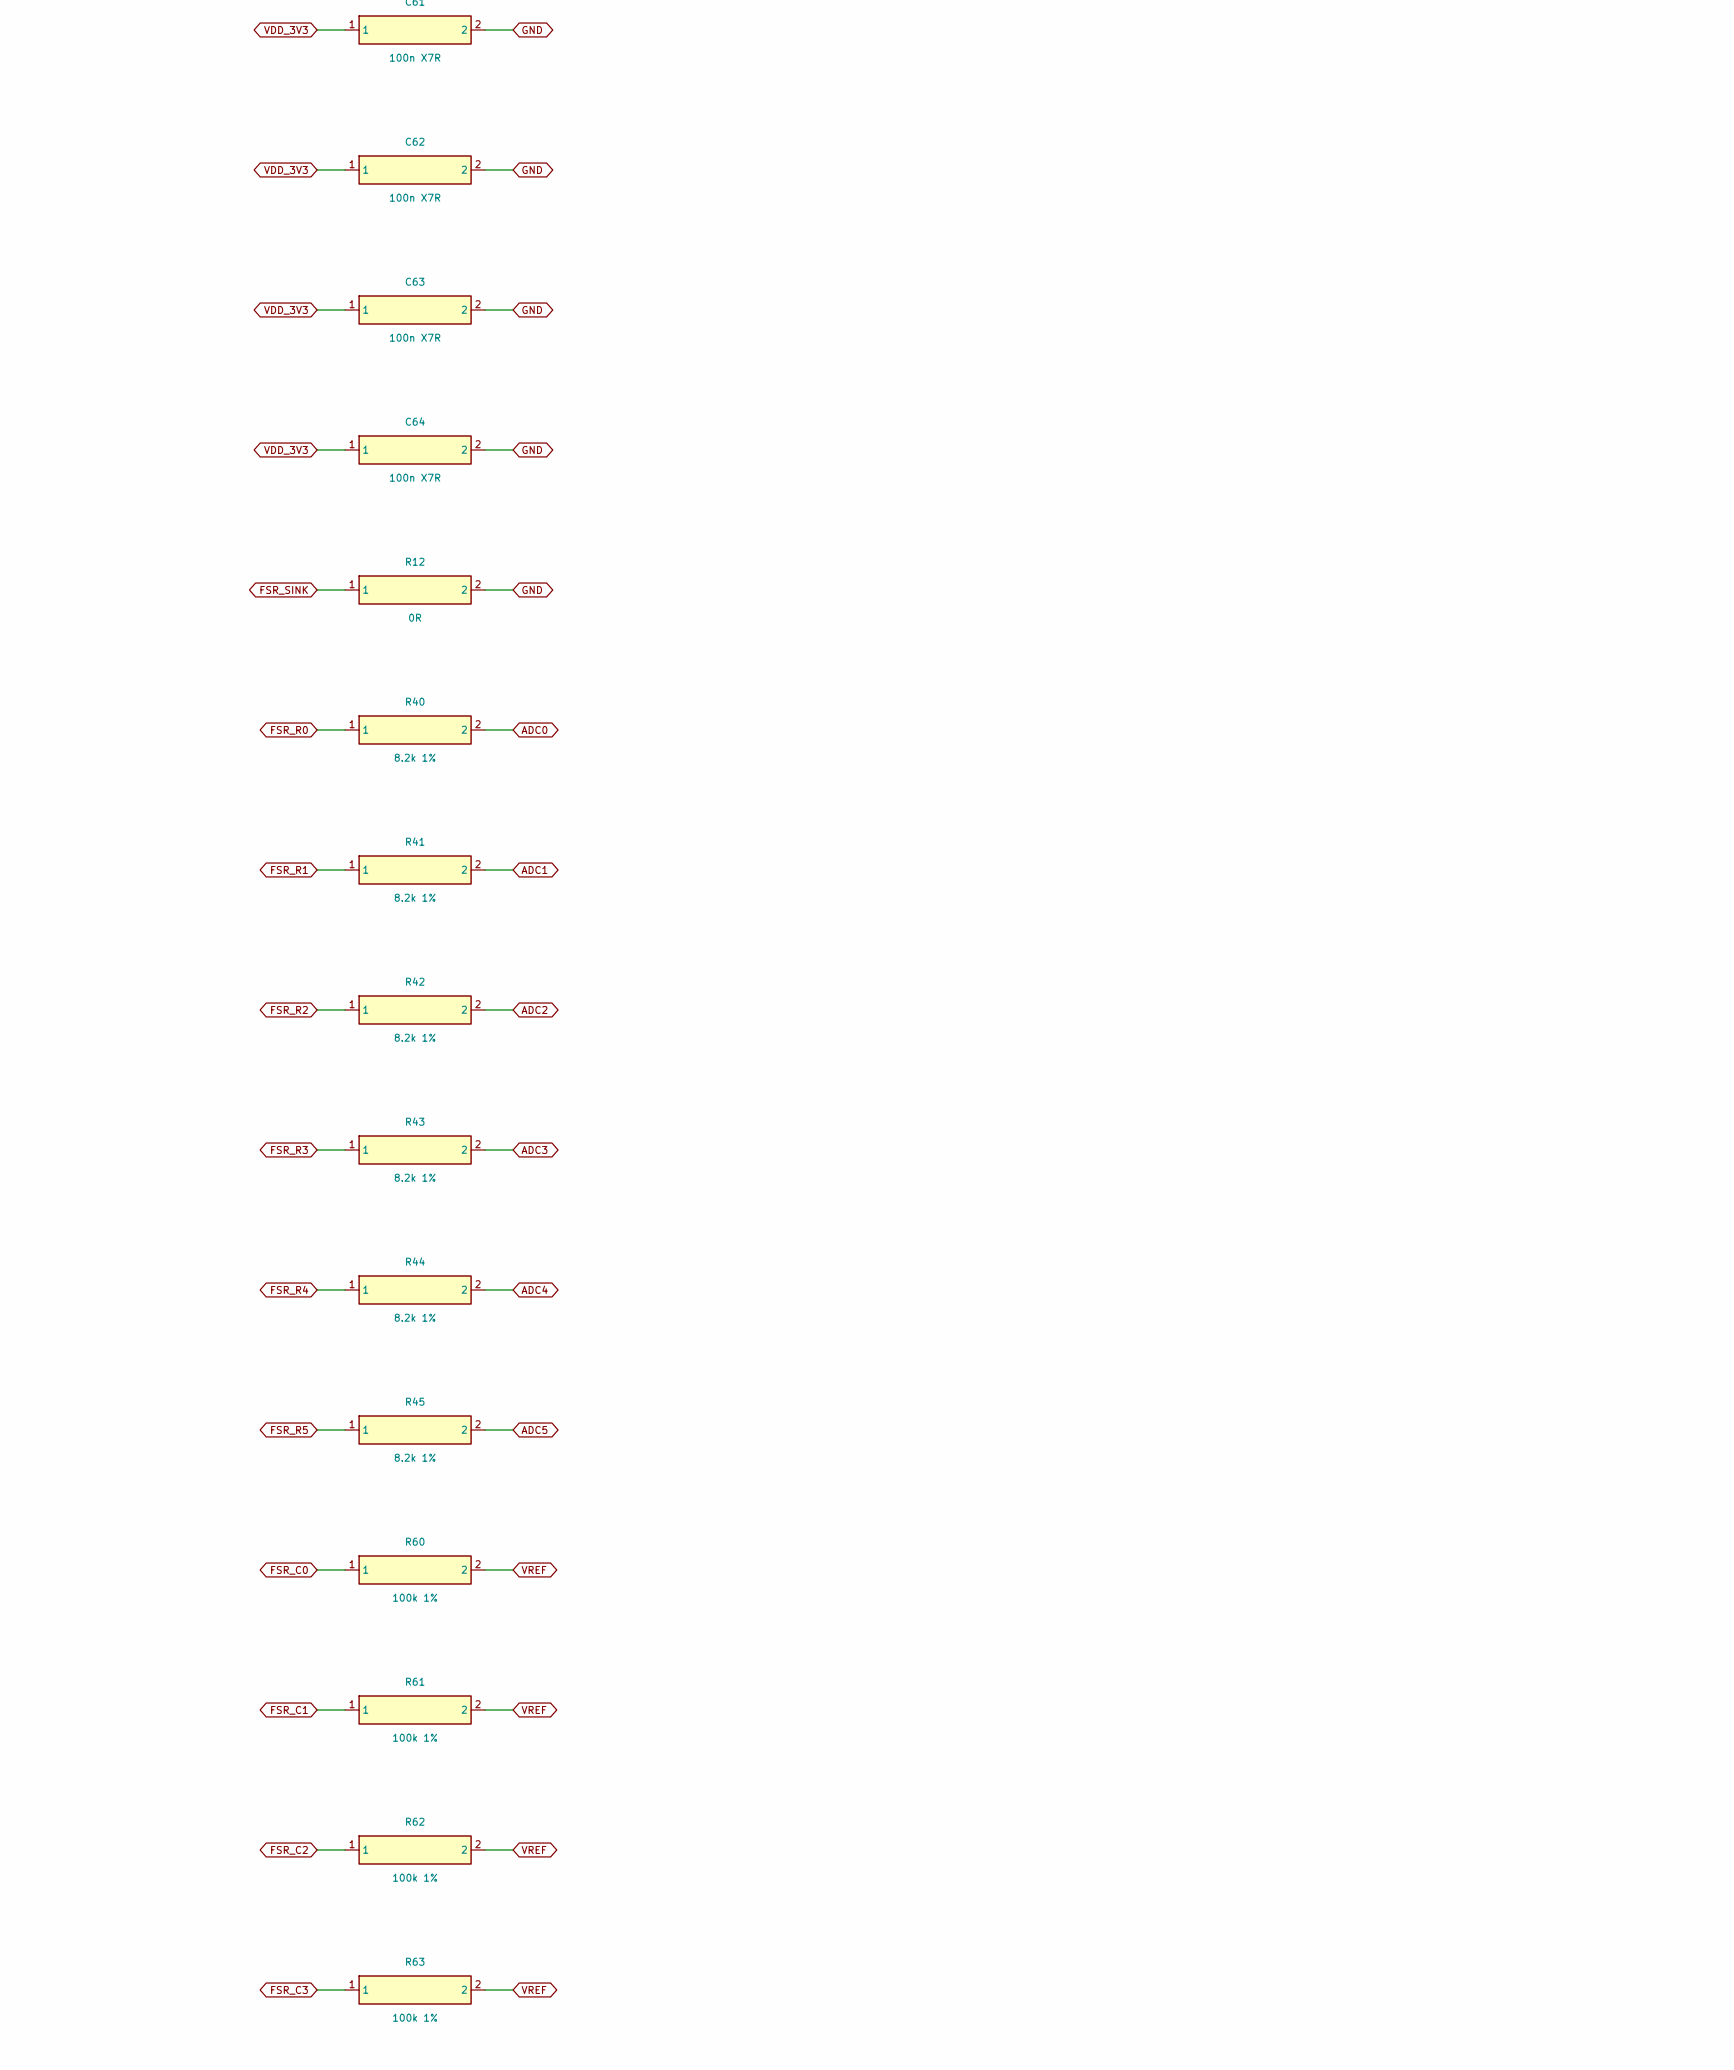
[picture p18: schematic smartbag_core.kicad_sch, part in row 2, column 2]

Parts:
AE1: 2450AT43F0100E; Johanson_2450AT43F0100_2400-2500Mhz
C1, C2: 2.2u X6T 2.5V; C_0402_1005Metric
C3: 10u X6S 6.3V; C_0402_1005Metric
C4, C7, C8, C9, C50, C51, C52, C61, C62, C63, C64: 100n X7R; C_0402_1005Metric
C5: 2.2n X7R; C_0402_1005Metric
C6: 1.5p NP0; C_0402_1005Metric
C11: 0.3p C0G; C_0402_1005Metric
C20, C21, C22, C23, C30, C31, C32, C33, C43, C44, C45, C46, C60: 1u X5R; C_0402_1005Metric
C24, C25, C34, C35: 8p NP0; C_0402_1005Metric
C40, C41, C42: 10u X5R 6.3V; C_0402_1005Metric
C80: 220n C0G (Cs); C_0603_1608Metric
C81: 2n2 C0G (Cd); C_0402_1005Metric
C82, C83: 10n X7R; C_0402_1005Metric
C84, C85: 470n X7R 25V; C_0603_1608Metric
C86, C87: 47n X7R; C_0402_1005Metric
C88: 10u X5R 25V; C_0603_1608Metric
FID1, FID2, FID3, FID4, FID5, FID6: fiducial; Fiducial_1mm_Mask2mm
J1: FFC optics, 12 way; Hirose_FH12-12S-0.5SH_1x12-1MP_P0.50mm_Horizontal
J2: Jauch LP523450JU 950mAh; JST_PH_S3B-PH-K_1x03_P2.00mm_Horizontal
J3: Qi RX coil; JST_SH_SM02B-SRSS-TB_1x02-1MP_P1.00mm_Horizontal
J4: FFC FSR matrix, 24 way; Hirose_FH12-24S-0.5SH_1x24-1MP_P0.50mm_Horizontal
J5: SWD debug; JST_SH_SM04B-SRSS-TB_1x04-1MP_P1.00mm_Horizontal
L1: 4.7u 120mA; L_0603_1608Metric
L2: 2.7n; L_0402_1005Metric
L3, L4: 2.2u 1.2A; L_0603_1608Metric
Q1: SI2302CDS-T1-GE3; SOT-23
R2, R3, R5, R22: 10k 1%; R_0402_1005Metric
R4: 1M 1%; R_0402_1005Metric
R6: 1k 1%; R_0402_1005Metric
R7, R8: 4.7k 1%; R_0402_1005Metric
R10: 6.8k 1%; R_0402_1005Metric
R11: 1.2k 1%; R_0402_1005Metric
R12: 0R; R_0402_1005Metric
R13, R60, R61, R62, R63, R64, R65, R66, R67, R68, R69, R70, R71, R72, R73, R74, R75: 100k 1%; R_0402_1005Metric
R20: 220R 1%; R_0402_1005Metric
R21: 100R 1%; R_0402_1005Metric
R40, R41, R42, R43, R44, R45: 8.2k 1%; R_0402_1005Metric
U1: nRF54L15-QFAA-R; QFN-48-1EP_6x6mm_P0.4mm_EP4.6x4.6mm
U2, U6: Acconeer A121; Acconeer_A121_fcCSP50
U3: nPM1300-QEAA-R7; QFN-32-1EP_5x5mm_P0.5mm_EP3.45x3.45mm
U4: BMI270; Bosch_LGA-14_3x2.5mm_P0.5mm
U5: DRV5032FBDBZR; SOT-23
U7: CD74HC4067SM96; SSOP-24_5.3x8.2mm_P0.65mm
U8, U9: TLV9064IPWR; TSSOP-14_4.4x5mm_P0.65mm
U11: BQ51013BRHLR; Texas_VQFN-RHL-20
Y1: 32 MHz Cl=8pF; Crystal_SMD_2016-4Pin_2.0x1.6mm
Y2, Y3: 24 MHz; Crystal_SMD_2016-4Pin_2.0x1.6mm
Y4: 32.768 kHz Cl=9pF; Crystal_SMD_2012-2Pin_2.0x1.2mm

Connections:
ADC0: R40.2, U1.5 (P1.04/AIN0), U8.1 (OUT1)
ADC1: R41.2, U1.6 (P1.05/AIN1), U8.7 (OUT2)
ADC2: R42.2, U1.7 (P1.06/AIN2), U8.8 (OUT3)
ADC3: R43.2, U1.8 (P1.07/AIN3), U8.14 (OUT4)
ADC4: R44.2, U1.39 (P1.11/AIN4), U9.1 (OUT1)
ADC5: R45.2, U1.40 (P1.12/AIN5), U9.7 (OUT2)
ANT_FEED: C6.1, L2.1, U1.31 (ANT)
BLE_ANT: AE1.1 (FEED), C11.1, L2.2
CS_CAM: J1.6 (CS), U1.16 (P2.05/CSN)
CS_RADAR_L: U1.11 (P2.00), U2.J2 (SPI_SS)
CS_RADAR_R: U1.21 (P2.10), U6.J2 (SPI_SS)
DCC: L1.1, U1.46 (DCC)
DECA: C1.1, U1.43 (DECA)
DECD: C2.1, U1.45 (DECD)
DECRF: C5.1, U1.33 (DECRF)
FSR_C0: J4.2 (C0), R60.1, U7.9 (I0)
FSR_C1: J4.3 (C1), R61.1, U7.8 (I1)
FSR_C2: J4.4 (C2), R62.1, U7.7 (I2)
FSR_C3: J4.5 (C3), R63.1, U7.6 (I3)
FSR_C4: J4.6 (C4), R64.1, U7.5 (I4)
FSR_C5: J4.7 (C5), R65.1, U7.4 (I5)
FSR_C6: J4.8 (C6), R66.1, U7.3 (I6)
FSR_C7: J4.9 (C7), R67.1, U7.2 (I7)
FSR_C8: J4.10 (C8), R68.1, U7.23 (I8)
FSR_C9: J4.11 (C9), R69.1, U7.22 (I9)
FSR_C10: J4.12 (C10), R70.1, U7.21 (I10)
FSR_C11: J4.13 (C11), R71.1, U7.20 (I11)
FSR_C12: J4.14 (C12), R72.1, U7.19 (I12)
FSR_C13: J4.15 (C13), R73.1, U7.18 (I13)
FSR_C14: J4.16 (C14), R74.1, U7.17 (I14)
FSR_C15: J4.17 (C15), R75.1, U7.16 (I15)
FSR_R0: J4.18 (R0), R40.1, U8.2 (IN1-)
FSR_R1: J4.19 (R1), R41.1, U8.6 (IN2-)
FSR_R2: J4.20 (R2), R42.1, U8.9 (IN3-)
FSR_R3: J4.21 (R3), R43.1, U8.13 (IN4-)
FSR_R4: J4.22 (R4), R44.1, U9.2 (IN1-)
FSR_R5: J4.23 (R5), R45.1, U9.6 (IN2-)
FSR_SINK: R12.1, U7.1 (COM)
GND: C1.2, C2.2, C3.2, C4.2, C5.2, C6.2, C7.2, C8.2, C9.2, C11.2, C20.2, C21.2, C22.2, C23.2, C24.2, C25.2, C30.2, C31.2, C32.2, C33.2, C34.2, C35.2, C40.2, C41.2, C42.2, C43.2, C44.2, C45.2, C46.2, C50.2, C51.2, C52.2, C60.2, C61.2, C62.2, C63.2, C64.2, C88.2, J1.1 (GND), J2.2 (BAT-), J4.1 (GND), J4.24 (SHLD), J5.4 (GND), Q1.2 (S), R2.2, R3.2, R6.2, R11.2, R12.2, R13.2, R21.2, R22.2, U1.32 (VSS_PA), U1.44 (VSS), U1.49 (EP), U2.A2, U2.A3 (GND), U2.A4 (GND), U2.A5 (GND), U2.A6 (GND), U2.A7 (GND), U2.A8 (GND), U2.A9, U2.B1, U2.B2 (GND), U2.B9 (GND), U2.B10, U2.C1 (GND), U2.C10 (GND), U2.D2 (GND), U2.D9 (GND), U2.E1 (GND), U2.E2 (GND), U2.E9 (GND), U2.E10, U2.F1, U2.F2 (GND), U2.F9 (GND), U2.G1 (GND), U2.G10 (GND), U2.H1, U2.H2 (GND), U2.H9 (GND), U2.J3 (GND), U2.J5 (GND), U2.J6 (GND), U2.J8 (GND), U2.K4 (GND), U2.K5, U2.K7 (GND), U3.2 (PVSS1), U3.6 (PVSS2), U3.8 (GPIO1), U3.9 (GPIO2), U3.10 (GPIO3), U3.11 (GPIO4), U3.23 (CC1), U3.24 (CC2), U3.26 (LED1), U3.27 (LED2), U3.30 (LSIN2), U3.31 (LSOUT2), U3.33 (EP), U4.1 (SDO), U4.2 (ASDx), U4.3 (ASCx), U4.6 (GNDIO), U4.7 (GND), U4.10 (OCSB), U4.11 (OSDO), U5.3 (GND), U6.A2, U6.A3 (GND), U6.A4 (GND), U6.A5 (GND), U6.A6 (GND), U6.A7 (GND), U6.A8 (GND), U6.A9, U6.B1, U6.B2 (GND), U6.B9 (GND), U6.B10, U6.C1 (GND), U6.C10 (GND), U6.D2 (GND), U6.D9 (GND), U6.E1 (GND), U6.E2 (GND)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
HALL_OUT: U1.28 (P0.03), U5.2 (OUT)
I2C_SCL: J1.8 (SCL), R8.1, U1.24 (P0.01), U3.14 (SCL), U4.13 (SCX)
I2C_SDA: J1.7 (SDA), R7.1, U1.23 (P0.00), U3.13 (SDA), U4.14 (SDX)
IMU_INT1: U1.27 (P0.02), U4.4 (INT1)
IR_LED_EN: Q1.1 (G), R13.1, U1.37 (P1.09)
IR_LED_K: J1.12 (LED-), Q1.3 (D)
LED0: R6.1, U3.25 (LED0)
MUX_EN_N: U1.19 (P2.08), U7.15 (EN)
MUX_S0: U1.3 (P1.02), U7.10 (S0)
MUX_S1: U1.4 (P1.03), U7.11 (S1)
MUX_S2: U1.9 (P1.08), U7.14 (S2)
MUX_S3: U1.18 (P2.07), U7.13 (S3)
NRESET: R5.1, U1.30 (nRESET)
NTC: J2.3 (NTC), U3.18 (NTC)
OPA_SPARE3: U9.8 (OUT3), U9.9 (IN3-)
OPA_SPARE4: U9.13 (IN4-), U9.14 (OUT4)
PMIC_IRQ: U1.29 (P0.04), U3.7 (GPIO0)
QI_AC1: C80.2, C81.1, C82.2, C84.2, C86.2, U11.2 (AC1)
QI_AC2: C81.2, C83.2, C85.2, C87.2, J3.2 (COIL_B), U11.19 (AC2)
QI_BOOT1: C82.1, U11.3 (BOOT1)
QI_BOOT2: C83.1, U11.17 (BOOT2)
QI_CLAMP1: C84.1, U11.5 (CLAMP1)
QI_CLAMP2: C85.1, U11.16 (CLAMP2)
QI_COIL_A: C80.1, J3.1 (COIL_A)
QI_COMM1: C86.1, U11.6 (COMM1)
QI_COMM2: C87.1, U11.15 (COMM2)
QI_FOD: R20.2, R21.1, U11.14 (FOD)
QI_ILIM: R20.1, U11.12 (ILIM)
QI_RECT: C88.1, U11.18 (RECT)
QI_TS: R22.1, U11.13 (TS_CTRL)
RADAR_EN: U1.17 (P2.06), U2.F10 (ENABLE), U6.F10 (ENABLE)
RADAR_IRQ_L: U1.14 (P2.03), U2.K8 (INTERRUPT)
RADAR_IRQ_R: U1.20 (P2.09), U6.K8 (INTERRUPT)
SHPHLD: R4.1, U3.15 (SHPHLD)
SPI_MISO: J1.5 (MISO), U1.15 (P2.04/SDI), U2.K3 (SPI_MISO), U6.K3 (SPI_MISO)
SPI_MOSI: J1.4 (MOSI), U1.13 (P2.02/SDO), U2.K6 (SPI_MOSI), U6.K6 (SPI_MOSI)
SPI_SCK: J1.3 (SCK), U1.12 (P2.01/SCK), U2.K2 (SPI_CLK), U6.K2 (SPI_CLK)
SW1: L3.1, U3.3 (SW1)
SW2: L4.1, U3.5 (SW2)
SWDCLK: J5.2 (SWCLK), U1.26 (SWDCLK)
SWDIO: J5.3 (SWDIO), U1.25 (SWDIO)
TOF_INT: J1.10 (TOF_INT), U1.42 (P1.14/AIN7)
TOF_XSHUT: J1.9 (XSHUT), U1.38 (P1.10)
VBAT: C43.1, J2.1 (BAT+), U3.19 (VBAT)
VBUSOUT: C45.1, U3.22 (VBUSOUT)
VDD_1V8: C20.1, C21.1, C22.1, C30.1, C31.1, C32.1, C41.1, L3.2, U2.C2 (VRX), U2.C9 (VTX), U2.D1 (VRX), U2.D10 (VTX), U2.J9 (VDIG), U3.1 (VOUT1), U6.C2 (VRX), U6.C9 (VTX), U6.D1 (VRX), U6.D10 (VTX), U6.J9 (VDIG)
VDD_3V3: C3.1, C4.1, C7.1, C8.1, C9.1, C23.1, C33.1, C42.1, C50.1, C51.1, C52.1, C61.1, C62.1, C63.1, C64.1, J5.1 (VDD), L1.2, L4.2, R5.2, R7.2, R8.2, R10.1, U1.10 (VDD), U1.22 (VDD), U1.36 (VDD), U1.47 (VDD), U1.48 (VDD), U2.J1 (RESET_N), U2.K9 (VIO), U3.12 (VDDIO), U3.32 (VOUT2), U4.5 (VDDIO), U4.8 (VDD), U4.12 (CSB), U5.1 (VCC), U6.J1 (RESET_N), U6.K9 (VIO), U7.24 (VCC), U8.4 (V+), U9.4 (V+)
VDD_CAM: C46.1, J1.2 (VDD), U3.29 (LSOUT1)
VQI: C44.1, U3.21 (VBUS), U11.4 (OUT)
VREF: C60.1, R10.2, R11.1, R60.2, R61.2, R62.2, R63.2, R64.2, R65.2, R66.2, R67.2, R68.2, R69.2, R70.2, R71.2, R72.2, R73.2, R74.2, R75.2, U8.3 (IN1+), U8.5 (IN2+), U8.10 (IN3+), U8.12 (IN4+), U9.3 (IN1+), U9.5 (IN2+), U9.10 (IN3+), U9.12 (IN4+)
VSET1: R2.1, U3.17 (VSET1)
VSET2: R3.1, U3.16 (VSET2)
VSYS: C40.1, J1.11 (LED+), R4.2, U3.4 (PVDD), U3.20 (VSYS), U3.28 (LSIN1)
X24L_1: C24.1, U2.J10 (XIN), Y2.1 (XI)
X24L_2: C25.1, U2.H10 (XOUT), Y2.3 (XO)
X24R_1: C34.1, U6.J10 (XIN), Y3.1 (XI)
X24R_2: C35.1, U6.H10 (XOUT), Y3.3 (XO)
XTAL32K_1: U1.1 (P1.00/XL1), Y4.1 (XI)
XTAL32K_2: U1.2 (P1.01/XL2), Y4.2 (XO)
XTAL32M_1: U1.34 (XC1), Y1.1 (XI)
XTAL32M_2: U1.35 (XC2), Y1.3 (XO)

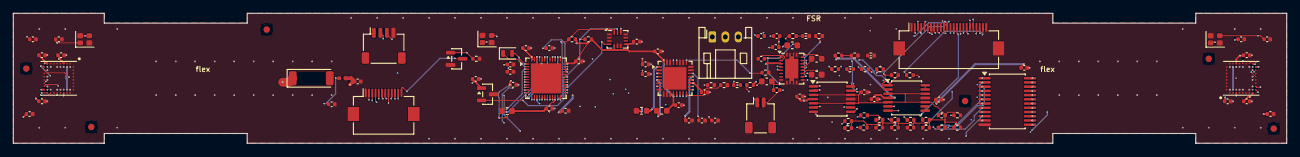
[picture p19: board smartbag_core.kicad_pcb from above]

Board: 6 copper layers, 196.0 x 20.0 mm, 113 parts (0 on the bottom side), 100 nets.

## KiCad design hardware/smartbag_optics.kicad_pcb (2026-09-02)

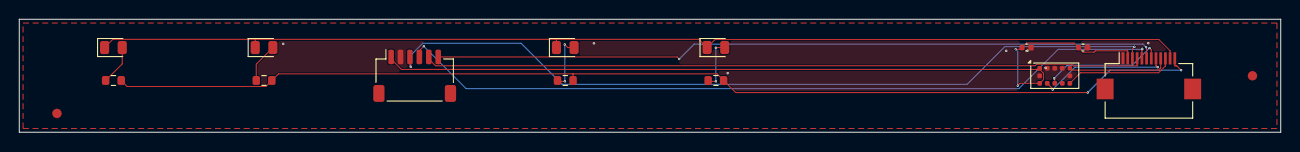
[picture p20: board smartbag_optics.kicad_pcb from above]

Board: 2 copper layers, 134.0 x 12.0 mm, 15 parts (0 on the bottom side), 16 nets.

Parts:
C1: 100n X7R; C_0402_1005Metric
C2: 4u7 X5R 10V; C_0402_1005Metric
D1, D2, D3, D4: VSMY1850X01 850nm; LED_0805_2012Metric
FID1, FID2: fiducial; Fiducial_1mm_Mask2mm
J10: FFC to insert, 12 way; Hirose_FH12-12S-0.5SH_1x12-1MP_P0.50mm_Horizontal
J11: camera module, 6 way; JST_SH_SM06B-SRSS-TB_1x06-1MP_P1.00mm_Horizontal
R1, R2, R3, R4: 51R 1%; R_0603_1608Metric
U10: VL53L1X; ST_VL53L1x

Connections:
CS_CAM: J10.6, J11.6
GND: C1.2, C2.2, J10.1, J11.2, U10.2, U10.3, U10.4, U10.6, U10.12
I2C_SCL: J10.8, U10.10
I2C_SDA: J10.7, U10.9
IR_LED_K: J10.12, R1.2, R2.2, R3.2, R4.2
LED1_K: D1.2, R1.1
LED2_K: D2.2, R2.1
LED3_K: D3.2, R3.1
LED4_K: D4.2, R4.1
SPI_MISO: J10.5, J11.4
SPI_MOSI: J10.4, J11.5
SPI_SCK: J10.3, J11.3
TOF_INT: J10.10, U10.7
TOF_XSHUT: J10.9, U10.5
VDD_CAM: C1.1, C2.1, J10.2, J11.1, U10.1, U10.11
VSYS: D1.1, D2.1, D3.1, D4.1, J10.11

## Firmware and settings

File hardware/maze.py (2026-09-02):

#!/usr/bin/env python3
"""A maze router for the handful of connections freerouting gave up on.

⛔ WHY THIS EXISTS AND finish.py DOES NOT DO IT. finish.py tries nine shapes per
pad — a straight line and two L-bends, on three layers — and on a board this
dense every one of them crosses something. It is honest about that: it reports
"no shape fits" and stops. What it cannot do is go *around*, and going around is
the whole job. Four connections were left, one of them 108 mm end to end.

⭐ THE TRICK IS THAT ZONES ARE NOT OBSTACLES. Almost every square millimetre of
F.Cu and B.Cu is ground pour, so a router that treated the pour as solid would
find no route anywhere. It does not have to: KiCad re-fills the zone around
whatever copper it finds, so a new track lays itself into the pour and the pour
retracts. The obstacles are pads, tracks and vias belonging to OTHER nets, plus
the rule areas and the board edge. That is the difference between "impossible"
and "twenty seconds".

⭐ AND THE OBSTACLES ARE DRAWN, NOT COMPUTED. Testing a million grid points
against two thousand segments in Python is a minute per net; drawing those
segments into a bitmap with a brush already fattened by (their width + the
clearance + ours) is milliseconds, and gives exactly the same answer. Pillow is
the collision engine.

⚠️ IT PROPOSES, DRC DISPOSES. Every route is applied to a copy, checked by a real
`kicad-cli pcb drc`, and kept only if the board comes out with fewer unconnected
items and no new violations. The router's own clearance model is an
approximation — pads are inflated by their bounding box, not their true shape —
so it is allowed to be optimistic as long as something exact has the last word.

Usage:
  <kicad-python> hardware/maze.py hardware/smartbag_core.kicad_pcb
"""
import heapq
import math
import os
import re
import shutil
import subprocess
import sys
import tempfile

import numpy as np
import pcbnew
from PIL import Image, ImageDraw

MM = 1e6                      # pcbnew works in nanometres
PITCH = 0.1                   # mm, one grid cell (see FINE_PITCH)
FINE_PITCH = 0.05             # mm, the second attempt
TRACK_W = 0.1                 # mm, replaced per net from the netclass
CLEAR = 0.1                   # mm, likewise
VIA_D, VIA_DRILL = 0.25, 0.10
VIA_COST = 24                 # in cells: a via is worth about 2.4 mm of track
MARGIN = 18.0                 # mm of room around the two endpoints to search in

# ⚠️ In1 and In4 are ground planes and are not routed on; In2 and In3 are
# the signal pair between them. Four routable layers, not three.
LAYERS = [pcbnew.F_Cu, pcbnew.In2_Cu, pcbnew.In3_Cu, pcbnew.B_Cu]
ALL_CU = [pcbnew.F_Cu, pcbnew.In1_Cu, pcbnew.In2_Cu, pcbnew.In3_Cu,
          pcbnew.In4_Cu, pcbnew.B_Cu]


# ── the DRC report tells us what is still open ───────────────────────────────
def drc(path, report=None, kinds=None):
    """(violations, unconnected, [(a, b, netname)]) from a real DRC run."""
    tmp = report or tempfile.NamedTemporaryFile(suffix=".rpt", delete=False).name
    subprocess.run(["kicad-cli", "pcb", "drc", "--schematic-parity",
                    "--severity-error", "-o", tmp, path],
                   capture_output=True)
    text = open(tmp).read()
    v = int(re.search(r"Found (\d+) DRC violations", text).group(1))
    u = int(re.search(r"Found (\d+) unconnected pads", text).group(1))
    pairs = []
    for block in text.split("[unconnected_items]")[1:]:
        # ⚠️ "Pad 10 [VDD_3V3]" has the pad number between the word and the net,
        # and the first version of this pattern required them to be adjacent —
        # so every pair lost its second endpoint and the router reported that
        # there was nothing to route.
        pts = re.findall(
            r"@\((-?[\d.]+) mm, (-?[\d.]+) mm\): (\w+)[^\[\n]*\[([^\]]*)\]",
            block[:400])
        if len(pts) >= 2 and pts[0][2] != "Zone" and pts[1][2] != "Zone":
            a = (float(pts[0][0]), float(pts[0][1]))
            b = (float(pts[1][0]), float(pts[1][1]))
            pairs.append((a, b, pts[0][3]))
    if kinds is not None:
        kinds.clear()
        for k in re.findall(r"^\[(\w+)\]", text, re.M):
            kinds[k] = kinds.get(k, 0) + 1
    if report is None:
        os.unlink(tmp)
    return v, u, pairs


# ⛔ A SHORT IS A CLEARANCE VIOLATION THAT WENT ALL THE WAY. freerouting laid
# QI_ILIM across VDD_3V3 on an inner layer and DRC called it shorting_items
# rather than clearance — a different word for the same pair of tracks in the
# same place, and the repair is identical. Leaving shorts out of this list meant
# the one violation that can destroy a board was the one nothing acted on.
OFFENCES = ("[clearance]", "[shorting_items]")


def clearance_pairs(path):
    """[(x, y, netname, length_mm)] for every item in a clearance or short."""
    tmp = tempfile.NamedTemporaryFile(suffix=".rpt", delete=False).name
    subprocess.run(["kicad-cli", "pcb", "drc", "--schematic-parity",
                    "--severity-error", "-o", tmp, path], capture_output=True)
    text = open(tmp).read()
    os.unlink(tmp)
    out = []
    blocks = []
    for kind in OFFENCES:
        blocks += text.split(kind)[1:]
    for block in blocks:
        # ⚠️ Vias offend too, and the first version of this pattern only read
        # tracks — so a QI_ILIM via sitting 0.0016 mm from a VDD_3V3 track was a
        # violation nothing could act on, and the tool kept reporting "0 ripped"
        # against a DRC report it had just read. A via is given length 0 so that
        # when it is paired with a track the via is always the one removed: a
        # layer change is cheap to redo, four millimetres of routed track is not.
        for m in re.finditer(
                r"@\((-?[\d.]+) mm, (-?[\d.]+) mm\): (Track|Via) \[([^\]]*)\]"
                r"[^\n]*?(?:length ([\d.]+) mm)?$", block[:400], re.M):
            out.append((float(m.group(1)), float(m.group(2)), m.group(4),
                        float(m.group(5)) if m.group(5) else 0.0))
    return out


def drop_dangling(path):
    """Remove fanout vias nothing ever used. Returns how many.

    ⛔ AND NOT THE ONES THAT ARE A PIN'S ONLY WAY OFF THE TOP LAYER. That
    exception is the whole of this function's history. generate_pcb.py puts a
    via 0.35 mm outside every signal pad of the dense QFNs so a signal can leave
    the package on F.Cu and immediately drop; the autorouter uses most of them
    and leaves the rest looking unused. They are not unused — they are the only
    thing standing between a pad and the other three layers.
    ⚠️ Removing two of them stranded U1's pins 10 and 22 on F.Cu inside a 0.4 mm
    escape row, and every router in this repository then reported, correctly,
    that there was no way out. Three tools and several hours went into the
    consequences of a tidy-up.
    """
    v, _u, _pairs = drc(path)
    report = tempfile.NamedTemporaryFile(suffix=".rpt", delete=False).name
    subprocess.run(["kicad-cli", "pcb", "drc", "--severity-all", "-o", report,
                    path], capture_output=True)
    text = open(report).read()
    os.unlink(report)
    pts = []
    for block in text.split("[via_dangling]")[1:]:
        m = re.search(r"@\((-?[\d.]+) mm, (-?[\d.]+) mm\)", block[:200])
        if m:
            pts.append((float(m.group(1)), float(m.group(2))))
    if not pts:
        return 0
    board = pcbnew.LoadBoard(path)
    doomed, spared = [], 0
    for t in list(board.GetTracks()):
        if t.Type() != pcbnew.PCB_VIA_T:
            continue
        p = t.GetPosition()
        if not any(abs(p.x / MM - x) < 0.02 and abs(p.y / MM - y) < 0.02
                   for x, y in pts):
            continue
        # ⭐ Is this via the only multi-layer access of a pad that has none?
        # If the island it sits on contains a pad and no other via, it is.
        net = t.GetNetCode()
        island = _island_tracks(board, net, (p.x / MM, p.y / MM))
        pads = [i for i in island if i.Type() == pcbnew.PCB_PAD_T]
        vias = [i for i in island if i.Type() == pcbnew.PCB_VIA_T]
        if pads and len(vias) <= 1:
            spared += 1
            continue
        doomed.append(t)
    for t in doomed:
        board.Remove(t)
    if doomed:
        pcbnew.ZONE_FILLER(board).Fill(board.Zones())
        board.Save(path)
    if spared:
        print(f"  {spared} dangling via(s) kept: a pad's only escape")
    return len(doomed)


def rip_offenders(path):
    """Delete the shorter track of each clearance pair. Returns how many.

    ⛔ A ROUTER THAT CANNOT UNDO CANNOT REPAIR. maze.py could only ever add
    copper, so a board that came back from freerouting with two tracks 0.127 mm
    apart where the Power class asks for 0.15 was a board it had nothing to say
    about — it would refuse its own routes for making a bad number worse and
    stop. Removing the offending piece first turns a clearance violation into an
    unconnected pad, which is the one problem this file knows how to solve.

    ⚠️ THE SHORTER ONE, and that is a real choice rather than a coin toss: these
    pairs are almost always a long working track and a stub the optimiser left
    behind at a junction. Ripping the long one throws away a route that was fine
    everywhere except one corner.
    """
    pairs = clearance_pairs(path)
    if not pairs:
        return 0
    board = pcbnew.LoadBoard(path)
    victims = {}
    for i in range(0, len(pairs) - 1, 2):
        a, b = pairs[i], pairs[i + 1]
        v = a if a[3] <= b[3] else b
        victims[(round(v[0], 4), round(v[1], 4))] = v[2]
    # ⚠️ MATCH BY NET AND NEARNESS, NOT BY EXACT START POINT. DRC reports a point
    # ON the offending track, which is its start only sometimes; keying on the
    # start meant the tool reported "0 ripped" while the violation it had just
    # read was still there. Anything of the right net with an end within a tenth
    # of a millimetre of the reported point is the track that was meant.
    doomed = []
    for t in list(board.GetTracks()):
        for (vx, vy), net in victims.items():
            if t.GetNetname() != net:
                continue
            ends = ((t.GetPosition(),) if t.Type() == pcbnew.PCB_VIA_T
                    else (t.GetStart(), t.GetEnd()))
            for e in ends:
                if abs(e.x / MM - vx) < 0.1 and abs(e.y / MM - vy) < 0.1:
                    doomed.append(t)
                    break
            else:
                continue
            break
    for t in doomed:
        board.Remove(t)
    if doomed:
        pcbnew.ZONE_FILLER(board).Fill(board.Zones())
        board.Save(path)
    return len(doomed)


def direct_join(path, a, b, netname, base_v, base_u):
    """Try the simplest thing first: a straight track between the two points.

    ⛔ THE MAZE ROUTER WAS FAILING ON GAPS A CHILD COULD DRAW. Two VREF fragments
    0.83 mm apart on the same layer, and A* produced a route that came back
    DRC-clean and still unconnected — seven times, on seven different nets. A
    hand-placed straight segment between the two reported points closed it
    immediately and cost nothing.
    ⭐ So the order is: try the line, then try the maze. The expensive machine
    exists for the 108 mm case that has to go around three components; asking it
    to solve a 0.8 mm gap was always going to be the part where its assumptions
    about anchors and layers earned nothing.

    ⚠️ Different layers get a via at the far end. Two fragments of one net that
    ended up on F and B are a layer change the router did not finish, and that is
    what a via is.
    """
    board = pcbnew.LoadBoard(path)
    net = board.GetNetcodeFromNetname(netname)
    if net == 0:
        return False
    layers = {}
    for t in list(board.GetTracks()):
        if t.GetNetCode() != net or t.Type() == pcbnew.PCB_VIA_T:
            continue
        for e in (t.GetStart(), t.GetEnd()):
            for pt in (a, b):
                if abs(e.x / MM - pt[0]) < 0.02 and abs(e.y / MM - pt[1]) < 0.02:
                    layers[pt] = t.GetLayer()
    for fp in board.GetFootprints():
        for pad in fp.Pads():
            if pad.GetNetCode() != net:
                continue
            p = pad.GetPosition()
            for pt in (a, b):
                if abs(p.x / MM - pt[0]) < 0.05 and abs(p.y / MM - pt[1]) < 0.05:
                    layers.setdefault(pt, pcbnew.F_Cu)

    la = layers.get(a, pcbnew.F_Cu)
    lb = layers.get(b, pcbnew.F_Cu)
    added = []
    if la != lb:
        v = pcbnew.PCB_VIA(board)
        v.SetPosition(pcbnew.VECTOR2I(int(b[0] * MM), int(b[1] * MM)))
        v.SetWidth(int(VIA_D * MM))
        v.SetDrill(int(VIA_DRILL * MM))
        v.SetLayerPair(pcbnew.F_Cu, pcbnew.B_Cu)
        v.SetNetCode(net)
        board.Add(v)
        added.append(v)
    t = pcbnew.PCB_TRACK(board)
    t.SetStart(pcbnew.VECTOR2I(int(a[0] * MM), int(a[1] * MM)))
    t.SetEnd(pcbnew.VECTOR2I(int(b[0] * MM), int(b[1] * MM)))
    t.SetWidth(int(TRACK_W * MM))
    t.SetLayer(la)
    t.SetNetCode(net)
    board.Add(t)
    added.append(t)
    pcbnew.ZONE_FILLER(board).Fill(board.Zones())
    board.Save(path)
    v2, u2, _ = drc(path)
    return u2 < base_u and v2 <= base_v


# ── the board, as three bitmaps ──────────────────────────────────────────────
class Grid:
    """Obstacle bitmaps for one net, over a window of the board.

    One image per routable layer for tracks, plus one more that is the union
    over EVERY copper layer — a via has to be clear on all of them, including
    the In1 plane it punches through.
    """

    def __init__(self, board, net, x0, y0, x1, y1, track_w=TRACK_W, clear=CLEAR,
                 pitch=PITCH):
        self.track_w, self.clear, self.pitch = track_w, clear, pitch
        self.x0, self.y0 = x0, y0
        PITCH_ = pitch
        self.w = int((x1 - x0) / PITCH_) + 1
        self.h = int((y1 - y0) / PITCH_) + 1
        self.net = net
        track_pad = (track_w / 2 + clear) / PITCH_     # cells to fatten by
        via_pad = (VIA_D / 2 + clear) / PITCH_

        self.track = {L: Image.new("1", (self.w, self.h), 0) for L in LAYERS}
        via_img = Image.new("1", (self.w, self.h), 0)
        draws = {L: ImageDraw.Draw(im) for L, im in self.track.items()}
        via_draw = ImageDraw.Draw(via_img)
        self.mine = {L: Image.new("1", (self.w, self.h), 0) for L in LAYERS}
        mine_draws = {L: ImageDraw.Draw(im) for L, im in self.mine.items()}

        def px(p):
            return ((p.x / MM - self.x0) / PITCH_, (p.y / MM - self.y0) / PITCH_)

        for t in board.GetTracks():
            own = t.GetNetCode() == net
            if t.Type() == pcbnew.PCB_VIA_T:
                r = t.GetWidth(pcbnew.F_Cu) / MM / 2 / PITCH_
                c = px(t.GetPosition())
                if own:
                    for L in LAYERS:
                        mine_draws[L].ellipse(_box(c, r), fill=1)
                    continue
                via_draw.ellipse(_box(c, r + via_pad), fill=1)
                for L in LAYERS:
                    draws[L].ellipse(_box(c, r + track_pad), fill=1)
            else:
                L = t.GetLayer()
                a, b = px(t.GetStart()), px(t.GetEnd())
                r = t.GetWidth() / MM / 2 / PITCH_
                if own:
                    if L in mine_draws:
                        mine_draws[L].line([a, b], fill=1, width=max(1, int(2 * r)))
                    continue
                # ⚠️ Round caps, and the width rounded UP. Pillow's `line` gives
                # a butt-ended rectangle, so a polyline's corners come out thin
                # and a route can be squeezed through the notch on the outside
                # of a bend — which is not a gap that exists on the board. The
                # first run produced nine clearance violations from exactly
                # that, plus a truncated width that under-inflated by up to one
                # cell.
                _w = math.ceil(2 * (r + via_pad)) + 1
                via_draw.line([a, b], fill=1, width=_w)
                via_draw.ellipse(_box(a, r + via_pad), fill=1)
                via_draw.ellipse(_box(b, r + via_pad), fill=1)
                if L in draws:
                    _w = math.ceil(2 * (r + track_pad)) + 1
                    draws[L].line([a, b], fill=1, width=_w)
                    draws[L].ellipse(_box(a, r + track_pad), fill=1)
                    draws[L].ellipse(_box(b, r + track_pad), fill=1)

        for fp in board.GetFootprints():
            for pad in fp.Pads():
                own = pad.GetNetCode() == net
                bb = pad.GetBoundingBox()
                lo = ((bb.GetLeft() / MM - self.x0) / PITCH_,
                      (bb.GetTop() / MM - self.y0) / PITCH_)
                hi = ((bb.GetRight() / MM - self.x0) / PITCH_,
                      (bb.GetBottom() / MM - self.y0) / PITCH_)
                for L in LAYERS:
                    if not pad.IsOnLayer(L):
                        continue
                    if own:
                        mine_draws[L].rectangle([lo, hi], fill=1)
                    else:
                        draws[L].rectangle(_rect(lo, hi, track_pad), fill=1)
                if not own:
                    via_draw.rectangle(_rect(lo, hi, via_pad), fill=1)

        # ⛔ Rule areas are not copper and block anyway: a fiducial's window and
        # the antenna's clearance are the two places on this board where the
        # absence of copper is the specification.
        for zone in board.Zones():
            if not zone.GetIsRuleArea():
                continue
            poly = zone.Outline()
            for i in range(poly.OutlineCount()):
                pts = [((poly.Outline(i).CPoint(k).x / MM - self.x0) / PITCH_,
                        (poly.Outline(i).CPoint(k).y / MM - self.y0) / PITCH_)
                       for k in range(poly.Outline(i).PointCount())]
                if len(pts) < 3:
                    continue
                if zone.GetDoNotAllowTracks():
                    for L in LAYERS:
                        draws[L].polygon(pts, fill=1)
                if zone.GetDoNotAllowVias():
                    via_draw.polygon(pts, fill=1)

        self.blocked = {L: np.array(im, dtype=bool) for L, im in self.track.items()}
        self.via_blocked = np.array(via_img, dtype=bool)
        self.own = {L: np.array(im, dtype=bool) for L, im in self.mine.items()}

        # ⚠️ Outside the board is not a place a track may go, and the edge needs
        # the same clearance as anything else. Drawn as a band along the outline
        # rather than by offsetting the polygon, which is non-convex here.
        edge = Image.new("1", (self.w, self.h), 1)
        ed = ImageDraw.Draw(edge)
        outline = []
        for d in board.GetDrawings():
            if d.GetLayer() == pcbnew.Edge_Cuts and d.GetShape() == pcbnew.SHAPE_T_SEGMENT:
                outline.append((px(d.GetStart()), px(d.GetEnd())))
        if outline:
            ring = _chain(outline)
            ed.polygon(ring, fill=0)
            ed.line(ring + [ring[0]], fill=1,
                    width=max(2, int(2 * (track_w / 2 + clear) / PITCH_)))
        outside = np.array(edge, dtype=bool)
        for L in LAYERS:
            self.blocked[L] |= outside
        self.via_blocked |= outside

    def free_around(self, mm_xy, radius=0.1):
        """Clear a small disk so a pin can leave its own pad.

        ⛔ A 0.4 mm PITCH QFN HAS NO LEGAL CHANNEL ON A 0.1 mm GRID. The gap
        between two adjacent pads is 0.4 mm less the pad width; inflate the
        neighbours by clearance plus half a track and what is left is a fraction
        of one cell, so the grid seals the pin in and the router reports no
        route — for a pin that plainly has one, because the autorouter got forty
        others out of the same package.

        ⭐ The escape is opened here and judged by DRC afterwards, which is the
        arrangement this whole file runs on: be optimistic where the model is
        coarse, and let something exact refuse.
        """
        cx, cy = self.cell(mm_xy)
        r = int(radius / self.pitch)
        y0, y1 = max(0, cy - r), min(self.h, cy + r + 1)
        x0, x1 = max(0, cx - r), min(self.w, cx + r + 1)
        yy, xx = np.ogrid[y0:y1, x0:x1]
        disk = (yy - cy) ** 2 + (xx - cx) ** 2 <= r * r
        for L in LAYERS:
            self.blocked[L][y0:y1, x0:x1] &= ~disk

    def cell(self, mm_xy):
        return (int(round((mm_xy[0] - self.x0) / self.pitch)),
                int(round((mm_xy[1] - self.y0) / self.pitch)))

    def mm(self, cell):
        return (self.x0 + cell[0] * self.pitch, self.y0 + cell[1] * self.pitch)


def rules_for(project, netname):
    """(track width, clearance) for one net, out of the project's own rules.

    ⛔ ONE HARDCODED CLEARANCE IS THE WRONG NUMBER FOR EVERY NET. This used 0.15
    mm for all of them — the Power class's figure — and the signal nets it was
    actually trying to route are Default, at 0.10. A tenth of a millimetre too
    much on each side of every obstacle is what turned a pin's escape channel
    into a sealed pocket of 79 cells: the router reported no route for a pin
    the autorouter had already got forty of its neighbours out of.
    """
    import json
    try:
        ns = json.load(open(project))["net_settings"]
    except Exception:
        return TRACK_W, CLEAR
    klass = "Default"
    for pat in ns.get("netclass_patterns") or []:
        if pat.get("pattern") == netname:
            klass = pat["netclass"]
            break
    for c in ns.get("classes") or []:
        if c.get("name") == klass:
            return (c.get("track_width", TRACK_W), c.get("clearance", CLEAR))
    return TRACK_W, CLEAR
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

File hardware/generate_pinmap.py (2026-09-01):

#!/usr/bin/env python3
"""The processor's pin map, written from the netlist rather than beside it.

⛔ A PIN MAP IS THE ONE THING IN FIRMWARE THAT IS NOT FIRMWARE'S TO DECIDE. It is
the schematic, restated in C, and every project that types it a second time
eventually has a board and an image that disagree about which pin is a chip
select. This one is generated: netlist.py says P2.10 carries CS_RADAR_R, so
sb_pinmap.h says P2.10 carries CS_RADAR_R, and there is no third place where a
human could put something else.

⭐ IT ALSO MAKES THE REASSIGNMENT SAFE. Routing moved the whole P2 block around —
signals that had to travel east were on the package's west edge, which cost
sixteen unconnected pads — and the only reason that was a cheap change is that
the firmware addresses pins through symbolic ids. This file is what turns those
ids back into silicon, and it is regenerated when the netlist moves.

⚠️ THE NAMES COME FROM THE nRF54L15 DATASHEET, via netlist.py's pin table: a pin
called "P2.05/CSN" is port 2, pin 5. Nothing here knows what an nRF is beyond
that convention, which is why it is asserted rather than assumed — a pin whose
name does not parse is an error, not a skipped line.

Usage:  python3 hardware/generate_pinmap.py
"""
import os
import re
import sys

HERE = os.path.dirname(os.path.abspath(__file__))
sys.path.insert(0, HERE)

import netlist as nl                # noqa: E402

TARGET = os.path.join(os.path.dirname(HERE), "firmware", "target")
OUT = os.path.join(TARGET, "src", "sb_pinmap.h")
OVERLAY = os.path.join(TARGET, "boards", "smartbag.overlay")

# HAL pin id -> the net that carries it. ⚠️ The left column is firmware/sb_hal.h's
# enum and the right is netlist.py's net name; this dict is the only place the
# two vocabularies meet.
HAL_PINS = [
    ("SB_PIN_RADAR_EN", "RADAR_EN"),
    ("SB_PIN_RADAR_IRQ_L", "RADAR_IRQ_L"),
    ("SB_PIN_RADAR_IRQ_R", "RADAR_IRQ_R"),
    ("SB_PIN_TOF_XSHUT", "TOF_XSHUT"),
    ("SB_PIN_TOF_INT", "TOF_INT"),
    ("SB_PIN_IMU_INT1", "IMU_INT1"),
    ("SB_PIN_HALL", "HALL_OUT"),
    ("SB_PIN_PMIC_IRQ", "PMIC_IRQ"),
    ("SB_PIN_IR_LED_EN", "IR_LED_EN"),
]

CHIP_SELECTS = [("SB_CS_RADAR_L", "CS_RADAR_L"),
                ("SB_CS_RADAR_R", "CS_RADAR_R"),
                ("SB_CS_CAMERA", "CS_CAM")]

MUX = ["MUX_S0", "MUX_S1", "MUX_S2", "MUX_S3"]
BUS = [("SPI_SCK", "SCK"), ("SPI_MOSI", "MOSI"), ("SPI_MISO", "MISO"),
       ("I2C_SDA", "SDA"), ("I2C_SCL", "SCL")]
# The six transimpedance outputs the multiplexer sweeps, in row order.
ADC_ROWS = ["ADC0", "ADC1", "ADC2", "ADC3", "ADC4", "ADC5"]


def processor_pins():
    """{net: (port, pin)} for every GPIO of U1, out of the netlist."""
    u1 = next(p for p in nl.PARTS if p[0] == "U1")
    out = {}
    for _num, name, _et, net in u1[5]:
        m = re.match(r"P(\d)\.(\d\d)", name)
        if not m:
            continue                       # SWD, XTAL, ANT, DCC, supplies
        out[net] = (int(m.group(1)), int(m.group(2)))
    return out


def main():
    pins = processor_pins()
    missing = [n for _, n in HAL_PINS + CHIP_SELECTS if n not in pins]
    missing += [n for n in MUX + ADC_ROWS + ["MUX_EN_N", "VSYS_SNS"]
                if n not in pins]
    missing += [n for n, _ in BUS if n not in pins]
    if missing:
        sys.exit(f"nets with no processor pin in netlist.py: {missing}")

    def row(net):
        port, pin = pins[net]
        return port, pin

    L = ['/* GENERATED by hardware/generate_pinmap.py — do not edit.',
         ' *',
         ' * ⛔ THE SCHEMATIC, RESTATED IN C. Every number below is read out of',
         ' * hardware/netlist.py, which is the same file the board and the',
         ' * schematic are built from. Editing this header by hand makes the',
         ' * image disagree with the copper, silently, and the only symptom is a',
         ' * peripheral that does not answer.',
         ' *',
         ' * ⚠️ Port and pin, not a Zephyr device: the devicetree in',
         ' * boards/smartbag.overlay is where these become gpio0/gpio1/gpio2',
         ' * handles. This header is what the overlay and the C agree on.',
         ' */',
         '#ifndef SB_PINMAP_H',
         '#define SB_PINMAP_H',
         '',
         '#include "sb_hal.h"',
         '',
         '/* {port, pin} for every id in sb_hal.h\'s pin enum, in enum order. */',
         'static const struct { uint8_t port, pin; } sb_pinmap[SB_PIN_COUNT] = {']
    for sym, net in HAL_PINS:
        port, pin = row(net)
        L.append(f"    [{sym}] = {{{port}, {pin:>2}}},        /* {net} */")
    L += ['};', '',
          '/* Chip selects, in sb_cs order. */',
          'static const struct { uint8_t port, pin; } sb_cs_pins[SB_CS_COUNT] = {']
    for sym, net in CHIP_SELECTS:
        port, pin = row(net)
        L.append(f"    [{sym}] = {{{port}, {pin:>2}}},        /* {net} */")
    L += ['};', '',
          '/* The FSR multiplexer: four select lines and an active-low enable. */',
          'static const struct { uint8_t port, pin; } sb_mux_sel[4] = {']
    for net in MUX:
        port, pin = row(net)
        L.append(f"    {{{port}, {pin:>2}}},                  /* {net} */")
    p_en, n_en = row("MUX_EN_N")
    L += ['};',
          f'#define SB_MUX_EN_PORT {p_en}',
          f'#define SB_MUX_EN_PIN  {n_en}      /* MUX_EN_N, active low */',
          '',
          '/* The six row amplifiers, as SAADC analog inputs. ⚠️ AINn is chosen by',
          ' * the pin, not by an index: on nRF54L each analog-capable pin maps to',
          ' * one AIN, and netlist.py records which by naming it. */',
          'static const struct { uint8_t port, pin; } sb_adc_rows[6] = {']
    for net in ADC_ROWS:
        port, pin = row(net)
        L.append(f"    {{{port}, {pin:>2}}},                  /* {net} */")
    p_v, n_v = row("VSYS_SNS")
    L += ['};',
          f'#define SB_VSYS_SNS_PORT {p_v}',
          f'#define SB_VSYS_SNS_PIN  {n_v}',
          '']
    for net, short in BUS:
        port, pin = row(net)
        L += [f'#define SB_{short}_PORT {port}', f'#define SB_{short}_PIN  {pin}']
    L += ['', '#endif /* SB_PINMAP_H */', '']

    os.makedirs(os.path.dirname(OUT), exist_ok=True)
    with open(OUT, "w") as f:
        f.write("\n".join(L))
    print(f"OK  {OUT}  ({len(HAL_PINS)} pins, {len(CHIP_SELECTS)} chip selects, "
          f"{len(ADC_ROWS)} analog rows)")
    write_overlay(pins)
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

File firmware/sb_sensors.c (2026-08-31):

#include "sb_sensors.h"

#include <string.h>

void sb_sensors_init(sb_sensors *s)
{
    memset(s, 0, sizeof(*s));
}

/* ── time-of-flight ──────────────────────────────────────────────────────── */
sb_sens_status sb_tof_up(sb_sensors *s, const sb_hal *hal)
{
    /* ⛔ ORDER MATTERS AND IT IS NOT THE OBVIOUS ONE. XSHUT is driven LOW first
     * even though the part is already off: the rail may still be decaying from
     * a previous burst, and releasing a shutdown pin into a half-powered part
     * is exactly the case the datasheet warns about. Low, rail, settle, high. */
    hal->gpio_set(hal->ctx, SB_PIN_TOF_XSHUT, SB_PIN_LOW);
    hal->delay_us(hal->ctx, SB_TOF_RAIL_SETTLE_MS * 1000);
    hal->gpio_set(hal->ctx, SB_PIN_TOF_XSHUT, SB_PIN_HIGH);
    hal->delay_us(hal->ctx, SB_TOF_BOOT_MS * 1000);

    /* Identify it before believing anything else it says. */
    uint8_t id[2] = {0, 0};
    if (!hal->i2c_read(hal->ctx, SB_TOF_I2C_ADDR, 0x01, id, 2)) {
        return SB_SENS_NO_REPLY;
    }
    s->tof_up = true;
    return SB_SENS_OK;
}

void sb_tof_down(sb_sensors *s, const sb_hal *hal)
{
    hal->gpio_set(hal->ctx, SB_PIN_TOF_XSHUT, SB_PIN_LOW);
    s->tof_up = false;
}

sb_sens_status sb_tof_range(sb_sensors *s, const sb_hal *hal, uint16_t *mm)
{
    if (!s->tof_up) {
        return SB_SENS_NOT_READY;
    }
    uint8_t go[3] = {0x00, 0x87, 0x40};        /* start ranging */
    if (!hal->i2c_write(hal->ctx, SB_TOF_I2C_ADDR, go, sizeof(go))) {
        return SB_SENS_NO_REPLY;
    }

    /* ⛔ A BOUNDED WAIT, NOT A SPIN. A sensor that has come off its flex never
     * raises its interrupt, and a loop with no deadline turns that into a
     * device that stops responding rather than one that reports a fault. The
     * counter exists so the failure is visible over BLE instead of silent. */
    uint32_t start = hal->now_ms(hal->ctx);
    while (!hal->gpio_get(hal->ctx, SB_PIN_TOF_INT)) {
        if (hal->now_ms(hal->ctx) - start >= SB_TOF_TIMEOUT_MS) {
            s->tof_timeouts++;
            return SB_SENS_TIMEOUT;
        }
        hal->delay_us(hal->ctx, 500);
    }

    uint8_t d[2];
    if (!hal->i2c_read(hal->ctx, SB_TOF_I2C_ADDR, 0x96, d, 2)) {
        return SB_SENS_NO_REPLY;
    }
    *mm = (uint16_t)((d[0] << 8) | d[1]);
    return SB_SENS_OK;
}

/* ── radar ───────────────────────────────────────────────────────────────── */
sb_sens_status sb_radar_up(sb_sensors *s, const sb_hal *hal)
{
    hal->gpio_set(hal->ctx, SB_PIN_RADAR_EN, SB_PIN_HIGH);
    hal->delay_us(hal->ctx, SB_RADAR_ENABLE_MS * 1000);

    /* ⚠️ BOTH sensors are probed, because ENABLE is shared: if one of them is
     * dead the other is still usable, and the map is then built from one
     * viewpoint instead of two. Refusing to come up at all because half the
     * hardware answered would be worse than a degraded map. */
    int alive = 0;
    for (int i = 0; i < 2; i++) {
        uint8_t tx[4] = {0xF0, 0, 0, 0}, rx[4] = {0};
        if (hal->spi_xfer(hal->ctx, i ? SB_CS_RADAR_R : SB_CS_RADAR_L,
                          tx, rx, sizeof(tx))) {
            alive++;
        }
    }
    if (alive == 0) {
        hal->gpio_set(hal->ctx, SB_PIN_RADAR_EN, SB_PIN_LOW);
        return SB_SENS_NO_REPLY;
    }
    s->radar_up = true;
    return SB_SENS_OK;
}

void sb_radar_down(sb_sensors *s, const sb_hal *hal)
{
    hal->gpio_set(hal->ctx, SB_PIN_RADAR_EN, SB_PIN_LOW);
    s->radar_up = false;
}
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

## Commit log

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2026-08-30 Schematic with clean ERC, tested firmware core, measured recognition pipeline
    The README used to open by admitting two things were missing. Both are now
    there, and what is still missing is stated as a number rather than a caveat.
    SCHEMATIC. Connectivity is declared once in hardware/netlist.py - pins,
    electrical types and nets for 26 parts - and consumed by the schematic
    generator, the board generator and the checks, so board and schematic cannot
    drift. kicad-cli reports 0 ERC violations, 0 DRC violations and 0 footprint
    errors on --schematic-parity.
    ERC found two things genuinely missing, and they were added rather than
    silenced: SWDIO/SWCLK went nowhere (there was no way to program the bo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
    [smartbag_core.kicad_pcb, smartbag_core.kicad_sch]
2026-08-30 Full-wave RF simulation, and it changed the design
    rf/patch_sim.py solves the 60 GHz patch element with openEMS FDTD. The setup is
    validated first - a patch sized by the transmission-line model comes back at
    59.0 GHz, -9.3 dB, within 1.7% of target - so that a negative result means the
    design rather than the solver.
    The element as drawn does not work. On the 0.6 mm rigid stack: -2.5 dB at
    50.8 GHz, nine gigahertz low and reflecting almost everything. h/lambda0 was
    0.12, which is enormous at 60 GHz; the board is 0.6 mm because that is what the
    rigid islands are, and nobody had chosen that for the antenna.
    The fix is the stackup, not the artwork: at 0.25 mm the same 1.2 mm patch gives
    -27.2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
    [generate_pcb.py]
2026-08-30 Taxel driver, GATT layer, companion app, RF feed and thermal budgets
    Four things were outstanding: routing, the drivers and the BLE stack, the
    app, and RF/thermal analysis. Three are now done and the fourth is
    measured and documented rather than faked.
    Two of them turned up problems the design has not answered:
    - rf/feed_loss.py: the transceiver sits 87 and 99 mm from the two antenna
    islands. At 60 GHz on 0.25 mm that is 0.94 dB/cm, so 8.2 dB one way and
    16.5 dB round trip — a factor of 2.6 in radar range thrown away before
    the antenna radiates. No layout fixes it; the distance is the floorplan.
    Three architectural ways out are listed and none is chosen here.
    - thermal/budget.py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
    [smartbag_core.kicad_pcb]
2026-08-30 Route the board with Freerouting; check the parts against real datasheets
    KiCad has no autorouter — it was removed in v6 — so the flow is pcbnew ->
    Specctra .dsn -> Freerouting -> .ses -> pcbnew. Freerouting is a maze
    router with rip-up and retry, which is exactly what three hand-written
    attempts had established was missing.
    Routing: 699 tracks, 204 vias, 0 DRC violations, 6 unconnected pads
    (was 80). In1.Cu carries zero tracks and stays a solid reference plane.
    Two of the three conclusions drawn from the failed hand-written attempts
    were wrong, and route.py now says so:
    - "via-in-pad is mandatory at 0.4 mm pitch" is false: 204 ordinary vias,
    no via-in-pad anywhere;
    - the attempts we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
    [bom.csv, smartbag_core.kicad_pcb, smartbag_core.kicad_sch]
2026-08-30 Fabrication outputs, and real pinouts for every IC
    tools/fab.sh turns the routed board into Gerbers (all 4 copper layers named
    explicitly — the default set is for a 2-layer board and would silently drop
    the inner planes), Excellon drill with PTH and NPTH separate, placement
    files, the BOM and a fabrication note generated from the project file so it
    cannot drift from the artwork it ships beside.
    The note says out loud that the board is not releasable: three ICs are
    footprints for parts that were never chosen.
    Working on that. Every IC now has a verified pinout from its own datasheet:
    - Acconeer A121: 50 balls, 27 ground, 0.5 mm pitch, transcribed ball by
    ball into hardware/generate_foo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
    [smartbag-bom.csv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]
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2026-08-31 Choose the camera, cost the inference, and let the antenna datasheet win
    Three things were still open. Each turned out to be answerable rather
    than a matter of taste, and two of them found errors.
    CAMERA. The SoC has no camera interface, so the module has to be SPI:
    Arducam Mega 3MP NoIR (B0435), six wires, no IR-cut filter, 3.3 V,
    56-136 mA. J1 was carrying I2C, a power-down and a reset that this part
    does not have; those three ways now carry the thing the board was
    actually missing — a way to switch the illuminators. thermal/budget.py
    had been costing them at 0.6 W for a hundredth of a second since before
    there was anything to switch them with. Q1 is that switch, with a gate
    pull-down s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
    [bom.csv, smartbag-bom.csv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]
2026-08-31 The ToF sensor the firmware always assumed, and fiducials
    Two production blockers, both of them things that were invisible to every
    check this project runs.
    THE TIME-OF-FLIGHT SENSOR. firmware/smartbag.h has declared
    SB_EV_TOF_CROSSED since the first commit — the beam across the mouth
    breaking is what arms the camera — dimensions.py has placed a sensor at
    TOF_X = 48, and the films show it working. No schematic ever contained
    one. The wake-up chain depended on an event no hardware could raise.
    It is a VL53L1X (LGA-12, 4.9 x 2.5 mm, I2C, XSHUT and GPIO1), it lives on
    the optics flex because it has to look across the opening, and J1 grew
    from ten ways to twelve to carry its I2C, shutdown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
    [bom.csv, smartbag-bom.csv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]
2026-08-31 The other two boards: the optics flex and the taxel sheet
    For the whole project the insert board was the only one that existed and
    it had two connectors going nowhere. That is why the firmware could
    depend on a time-of-flight sensor that appears in dimensions.py, in the
    films and in the state machine, and in no schematic anywhere.
    THE OPTICS FLEX (134 x 12 mm, 2 layers). The VL53L1X whose beam raises
    SB_EV_TOF_CROSSED, four VSMY1850X01 850 nm emitters, and a six-way header
    for the Arducam Mega 3MP NoIR. DRC 0 errors, 2 unconnected pads.
    The illuminators are honestly not a current source: 51 ohm gives 49 mA at
    4.2 V and 27 mA at 3.0 V, so the scene dims by half as the cell empties
    while ml/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
    [bom.csv, smartbag-bom.csv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]
2026-08-31 The charge policy: the last open finding, closed
    thermal/budget.py has printed the same red line on every run since it was
    written — 5 W into a Qi coil under a lithium cell inside a closed bag puts
    that cell near 60 C against a 45 C limit. The hardware to fix it went on
    the board two commits ago; what was missing was a policy, and a
    thermistor nobody asks a question of is decoration.
    firmware/sb_power.c is that policy, and it is pure: no I/O, no clock, no
    state, so all of it is testable. Full current only with the bag OPEN and
    the cell between 10 and 40 C; 2.2 W otherwise; nothing at all if the
    thermistor reads open.
    The interlock is the cheapest of the three fixes the analysis proposed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
    [sb_power.h]
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2026-08-31 finish.py: try the last few connections, with DRC as the judge
    Freerouting recommends something it cannot do — "it is recommended to
    stop it and finish the board manually" — and manually is fine, but a
    person drawing four tracks and eyeballing them is exactly the step this
    project avoids everywhere else.
    So the candidates are drawn blind: seven shapes per unconnected pad
    (straight and both L-bends, on the pad's own layer and through vias to
    two others), each applied, each judged by a full DRC run, and kept only
    if the board came out with fewer unconnected pads and no new violations.
    Anything else is reverted. It cannot make the board worse.
    On the four pads left on the insert board it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
    [smartbag_core-B_Cu.gbr, smartbag_core-B_Mask.gbr, smartbag_core-B_Paste.gbr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]
2026-08-31 Fiducials: the one part that can go anywhere, placed like it could not
    Thirteen DRC violations on the routed board were all the same three parts.
    A fiducial has no net, so nothing in the flow knew it was there: the
    placement relaxer shoved two of them into capacitors and stalled, the
    stitching via grid dropped a hole in a third, and freerouting ran a
    VDD_3V3 track 0.44 mm from a fourth. A placement camera looking for a
    round mark on bare soldermask would have found copper.
    - fiducials are placed last, by search rather than by nudging, and their
    position is a decision the netlist states: two per rigid island,
    diagonally opposite, because the flex tails let the islands move with
    respect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
    [bom.csv, smartbag_core.kicad_pcb, smartbag_core.kicad_sch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]
2026-08-31 Sixteen unconnected pads were a pin assignment, not a routing problem
    The board came back from the router with one contiguous run of U1's pins
    unrouted, and what they had in common was direction: every destination
    was tens of millimetres east, and MUX_S3 sat on pin 11 — the west edge.
    That net began by crossing the whole processor before it could start
    travelling.
    Which GPIO carries which signal is a layout decision, and on this part it
    is nearly free: the firmware reaches pins through a HAL of symbolic ids,
    so the physical assignment is invisible to it. The P2 block is now
    ordered by destination — westbound nets on the west pins, eastbound on
    the east, furthest travel outermost. SPI_SC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
    [bom.csv, smartbag-bom.csv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]
2026-08-31 Re-render every film and still, and one caption that had stopped being true
    The staleness check added last week had been failing since it was
    written: media/smartbag.mp4 and smartbag_sequence.mp4 were older than
    dimensions.py, so both films showed a bag whose geometry had moved on.
    All five shots are re-rendered and both films re-cut.
    ⚠️ A caption said "196 × 20 mm strip · 2-layer rigid-flex". It was
    written when the board was two layers and stayed behind when In1.Cu
    became a solid ground reference and In2.Cu took most of the routing —
    919 of 1713 segments. A film is a claim like any other.
    ⚠️ Four Blender processes ended up rendering the same shot directories at
    once, from lau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
2026-08-31 The app is an app, and the bag in it is the bag
    Three things the app got wrong, all of them the same mistake in different
    places: showing what was easy to draw instead of what someone holding a
    handbag wants to know.
    - The map was a plan view — three rectangles and six dots, seen from
    above. Nobody recognises their own bag from above, and objects that
    stand upright in a 78 mm insert appear as slivers. It is now the bag
    drawn from the FRONT at its real dimensions (240 mm across the base,
    276 at the top of the body, 245 to the rim, straight out of
    dimensions.py) with the contents standing on the sensing floor, at
    their measured positions and their real sizes.
    - The empty top hal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
2026-08-31 The tab bar was inside the screen's corner, and the corner was wrong too
    Two defects at the same pixel. The bar had 7 px of bottom padding, which
    puts what you tap deep inside a rounded corner's arc — the background
    running to the edge is right and is what gets clipped, the controls must
    sit above it. env(safe-area-inset-bottom) does not fix that on its own:
    it is 0 in an iframe, 0 on the desktop and 0 on any phone without a home
    indicator, so the clearance has to exist without it.
    And the mock's screen had a 44 px radius inside a 54 px body with a 12 px
    bezel, where the opening is 42. Two pixels of mismatch let the screen's
    corner poke outside the curve the frame draws, which showed as a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
2026-09-01 A battery you can order, and the coil comes out from under it
    BT1 was the one line in the bill of materials that was not a part: a
    4.2 x 58 x 148 mm semi-custom pouch, a shape derived from the insert
    floor it had to fill. Nobody stocks that, so the design ended at "have a
    cell made".
    It is now Jauch LP523450JU — 950 mAh, 53.0 x 34.5 x 5.4 mm (5.8 after
    cycling, and the pocket is cut to that), PCM, UN38.3, IEC62133-2, 507 in
    stock at Digi-Key for $11.71. It brings its own 10k B=3435 thermistor on
    pin 3 of a JST PHR-3 harness, which is exactly what nPM1300 wants and
    what firmware/sb_power.c has been written against since the thermal
    analysis asked for it.
    ⛔ AND THE PIN ORDER WAS WRONG. J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
    [bom.csv, smartbag_core.kicad_pcb, smartbag_optics.kicad_pcb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]
2026-09-01 The target build: nine HAL functions, and a pin map nobody types twice
    sb_hal.h has said since it was written that everything below it was a
    function pointer and none of it was implemented — nine functions, plus a
    vendor stack, and that was the honest size of the remaining silicon work.
    This is those nine, on an nRF54L15 under Zephyr, plus the main() that
    hands them to the logic and the devicetree that says which pin is which.
    ⭐ THE LOGIC IS COMPILED IN, NOT COPIED IN. ../sb_power.c and its
    neighbours are the same files the host tests build, appearing once. A
    target build that forked them would let the tested version and the
    shipped version drift, which is the entire failure the HAL exi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
    [generate_pinmap.py]
2026-09-01 set -e was decoration: every step was piped to tail
    A crash inside specctra.py printed its traceback and the pipeline carried
    straight on into fill, stitch and route. The board came out with 117
    unconnected pads out of an import that had never happened, and reported
    it as a normal run.
    The cause is one line per script: `python3 ... | tail -1`. A pipeline's
    exit status is the LAST command's, tail always succeeds, and `set -e`
    therefore never saw anything fail. Five scripts now set pipefail.
    ⛔ AND THE CRASH ITSELF WAS TWO CLEANUP PASSES ON ONE BOARD. pcbnew's
    GetTracks() is a live wrapper: once anything has been removed, it comes
    back as a raw SWIG pointer that will not iterate — and on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
    [smartbag_core.kicad_pcb, smartbag_core.kicad_sch]
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2026-09-01 It compiles: 173 KB of flash on an nRF54L15
    firmware/target was written against the Zephyr API rather than against a
    compiler, and its README said so in the second line. It said so because
    there was no SDK on this machine — there was: ~/zephyrproject at Zephyr
    4.4.99 with nrf54l15dk support, and ~/zephyr-sdk-1.0.1 with the ARM
    toolchain. Looking for them was cheaper than the paragraph explaining
    why they were not there.
    FLASH: 173288 B / 1524 KB 11.10%
    RAM: 43662 B / 256 KB 16.66%
    Four things were wrong and every one is the kind only a build finds:
    - the board's devicetree gives spi00 a SLEEP pinctrl state as well as a
    default, so an overlay naming one state leaves pinctrl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
    [generate_pinmap.py]
2026-09-01 Flex tails 14 mm -> 17 mm, and the optimiser's speed-up is a trap
    The tails were widened from 8 to 14 mm once already, and the argument has
    not changed: bend radius is a function of THICKNESS, not width, so a
    wider tail folds exactly as tightly and just carries more copper across
    the fold. 14 was still the bottleneck once the real cell brought a JST PH
    twice the SH's area and the A121's fourteen interior ground balls got the
    vias they needed — the SPI bus to the right radar was the first thing the
    router gave up on, again. 17 and not 20 because a millimetre and a half
    of polyimide either side of the copper is what keeps a fold from tearing
    at the edge of a track.
    ⛔ AND THE OPTIMISER'S O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
    [smartbag_core.kicad_pcb]
2026-09-01 A fanout via per pin: 10 unconnected -> 1
    Forty-eight pins escaping on a single layer was the bottleneck all along,
    and it stayed invisible because it never produced a wrong answer — only a
    router that gave up. U1 is a QFN48 on a 0.4 mm pitch with thirty-five
    signals to get out; without a fanout each one travels on F.Cu until it
    finds room to drop, so the pins facing away from their destination cross
    the whole package on the board's most congested layer.
    qfn_fanout() puts a via 0.35 mm outside every signal pin of U1, U3 and
    U7, outward along the pad's own normal so it never lands between two
    pins. It is what a person would draw and the standard escape for a
    fine-pitch QFN: one via per sig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
    [smartbag-bom.csv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]
2026-09-01 A bill of materials you can put in a basket
    23 named parts, each with a manufacturer number whose package was
    measured against its own datasheet — and none of that puts anything in a
    cart. tools/order.py writes what a distributor takes: part number and
    quantity, for a BUILD rather than for a board, because five prototypes of
    a design with two radars on it is ten radars and the commonest way to be
    short on assembly day is to have ordered one board's worth of something
    that appears twice.
    Trying to order found two parts that do not exist to order, the same way
    the battery was found — by looking for a basket rather than for a
    datasheet:
    - U10 was "VL53L1X", which is the family. The ordera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
    [bom.csv, smartbag-bom.csv, smartbag-order.csv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]
2026-09-01 A 9:16 clip for the discovery feed, and it is not a crop
    Kickstarter's mobile discovery mode wants 9:16 and this project had five
    shots, all of them 16:9. Cutting the ends off a landscape shot of a
    276 mm bag gives you the middle of a bag, and every frame of it looks
    like a mistake.
    render/animation.py takes --vertical and renders the shots again with the
    frame turned on its side. ⛔ THE LENS CORRECTION GOES THE OPPOSITE WAY TO
    THE INSTINCT: a portrait frame is narrower, so the reflex is to widen the
    lens — and that leaves the bag in the middle of a tall empty room, which
    is exactly what the first attempt produced. Blender fits the sensor to
    the LARGER dimension, so turning the frame alr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
2026-09-01 The handle goes with the panel it is sewn to
    Cutting the bag open left the front strap sliced in mid-air: a severed
    leather loop hanging over the opening with nothing beneath it, because
    the panel it is attached to had retracted and it had not. The version
    before that did not cut the handles at all and the strap ran straight
    through the opening, which was worse — so this is the second attempt at
    the same fix, and the first one traded one wrong picture for another.
    ⭐ A QUARTER THAT RETRACTS TAKES ITS HANDLE WITH IT. The handles now get
    their own cutting box rather than the section's: full width, front half
    only in depth. The front strap goes away entirely, the back one keeps the
    wall it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
2026-09-01 sb_feed() was never called: the bag could not see
    The hole was odd-shaped. Every decision the bag makes hangs off sb_feed()
    — the wake-up chain, the ledger, the staleness rule, 378 assertions — and
    nothing anywhere called it. The image booted, advertised, charged and
    answered a phone, and reported an empty bag forever.
    firmware/sb_sense.c is the loop that reads a sensor and produces an event.
    A state machine over the HAL, so the sequence runs on a laptop against a
    simulated bag: asleep -> awake -> capturing -> settling -> mapping. Three
    of its rules are decisions with tests that fail without them — a debounce
    that refuses to change its mind rather than one that waits, a beam that
    has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
    [bom.py, sb_camera.c]
2026-09-01 Every line has a price, and two of them are not on a shelf
    Fifteen of the twenty-seven named lines had no price at all: the BOM said
    "a BOM is not an order" and then stopped one step short of being one. All
    fifteen are now quoted from the distributor, one page at a time, with the
    date on each.
    ⛔ And the thing that actually delays a build is not the price. Two lines
    cannot be filled today — the Würth receiver coil, which was already known
    to have a lead time, and the DRV5032 Hall sensor, which was not: zero in
    stock, 463 due 24 September. That is the one part the whole wake-up chain
    starts with, and nothing in this repository would have said so, because
    nothing compared what a build nee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
    [smartbag-order.csv]
2026-09-01 Forty-one of forty-one supply pins had no decoupling worth the name
    The check did not exist, so I wrote it, and every IC supply pin on the board
    failed it. The worst was the multiplexer at 26 mm — a 100 nF part twenty-six
    millimetres from its pin is an inductor with a capacitor in series. The board
    had been routed, DRC'd, rendered, costed and called orderable in that state.
    And netlist.py said it was already fixed. "THE 100 nF PARTS HUG THE PINS THEY
    DECOUPLE... the QFN has VDD on all four sides, so there is a capacitor on all
    four sides", naming C5 as the one on the top edge — which is 2.2 nF on DECRF,
    an internal regulator pin. U1 pins 47/48 never had decoupling and neither did
    U7. A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
    [smartbag_core.kicad_sch]
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2026-09-02 The tidy-up was removing the escapes, and that was the whole story
    Both connections this board could not close were the same thing, and it was
    self-inflicted. `maze.py --tidy` removes fanout vias that look unused — and a
    via 0.35 mm outside a pad is not unused, it is the only thing standing between
    that pad and the other three copper layers. Removing two of them stranded U1's
    pins 10 and 22 on F.Cu inside a 0.4 mm escape row, and every router here then
    reported, correctly, that there was no way out.
    The islands said it plainly once I asked: a pad plus one stub track, ZERO vias,
    against a main island of 150 tracks and 22 vias. Not a routing problem. A hole
    somebody had filled in.
    drop_dan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
    [smartbag_core.kicad_pcb]
2026-09-02 Two of the three closed: the escapes were the missing half
    U1.10 reaches its decoupling capacitor through two B.Cu segments from the
    escape via the tidy-up had removed. FSR_R2 needed one drop at (242.631,
    147.295) — a B.Cu track that had finished exactly on an F.Cu pad.
    3 unconnected -> 1, still 0 clearance violations and 0 shorts.
    ⛔ And two more of the same mistake on the way, both mine: a B.Cu track ending
    on an F.Cu pad connects nothing, and I laid one before checking. The
    destination's layer is part of the destination.
    [smartbag_core.kicad_pcb]
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2026-09-02 Six copper layers in the zip, and the layer list no longer typed by hand
    The fabrication package was plotting a six-layer board as four. tools/fab.sh
    named the copper layers in a string, the string was right for four, the stackup
    became six, and In3 and In4 were simply not in the gerbers. The comment directly
    above that string warned about exactly this failure — "the default set is for a
    2-layer board and would silently drop the inner planes" — and then did not save
    it, because a warning about a hand-typed list is still a hand-typed list.
    It reads the layer table out of the .kicad_pcb now. A board file cannot be wrong
    about how many copper layers it has.
    copper: F.Cu,In1.Cu,In2.Cu,In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
    [smartbag-passives.csv, smartbag-patterns.dxf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]
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2026-09-03 Dead tools out, and a comment that said EMPTY over two entries
    repairs.py carried '⭐ EMPTY, AND THAT IS THE RESULT' directly above a list with
    two repairs in it, for about an hour. The list genuinely was emptied when six
    layers closed the nets four could not — and then the rebuild showed the two
    paths those layers made possible are still not something freerouting finds, so
    they came back and the comment did not. Same failure netlist.py had about the
    decoupling: a claim in prose with the contradiction three lines below it.
    Removed, with nothing depending on either:
    hardware/close_gaps.py 202 lines, written today, never found a real defect —
    the eight isl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
    [flip_back.py, repairs.py]
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
